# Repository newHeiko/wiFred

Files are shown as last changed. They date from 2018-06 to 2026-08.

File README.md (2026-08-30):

# wiFred
wiThrottle-compatible hardware controller

This repo contains schematics, PCB and documentation for the wiFred, a wiThrottle-compatible WiFi hardware controller developed to unchain the Fremo Fred [1] / Fredi [2] from its loconet cable.

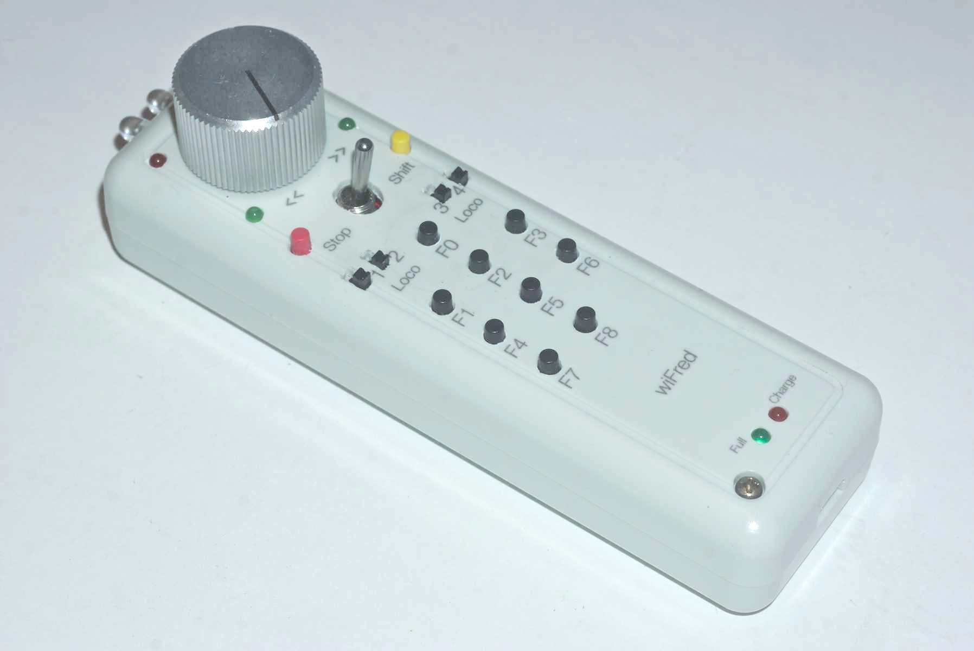
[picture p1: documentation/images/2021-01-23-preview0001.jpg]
wiFred rev0.5


### Branch information
Several versions are contained in different branches:

- master branch: Designed to fit into Strapubox 2090 housing, powered by a lithium battery, hardware: ESP32-S2-WROOM, THT pushbuttons
  - rev0.6 (initial)
  - rev0.62 (switched USB connector to USB-C)
  - rev0.63 (replaced constant current source for flashlight with charge pump, replaced a few out-of-stock parts)
  - rev0.64 (added silk-screen text for LEDs and colored buttons, moved flashlight LEDs further apart, added twist protection for direction switch)
  - Latest Firmware: https://github.com/newHeiko/wiFred/blob/master/software/pre-compiled/2026-08-30-5456979-master.bin
- esp12 branch: Designed to fit into Strapubox 2090 housing, powered by a lithium battery, hardware: AVR ATMega328P plus ESP12F, SMD pushbuttons
  - rev0.4 (no flashlight prototype)
  - rev0.5 (Added flashlight)
  - rev0.51 (Fixed silkscreen on PCB)
  - rev0.52 (Moved LEDs out of the key matrix to get rid of double function key presses)
  - Latest Firmware: https://github.com/newHeiko/wiFred/blob/master/software/pre-compiled/2026-08-30-b6b983a-esp12.bin to go with AVR firmware https://github.com/newHeiko/wiFred/blob/master/software/pre-compiled/2025-03-26-ddf1322-esp12.hex
- esp12-old branch: No longer developed. Mostly the same hardware as esp12 branch before the rev0.52 fix, but with old protocol between AVR and ESP12F and key presses often activating multiple functions. See the documentation at https://newHeiko.github.io/wiFred/documentation/fix05matrix_en.html for fixing the PCB to work with firmware from esp12-branch.
- newAgeEnclosures branch: No longer developed, designed for New Age Enclosures Compact AA housing, powered by 2x AA cells, hardware: AVR ATMega328P plus ESP12F, SMD pushbuttons
- AABatteryPrototype branch: No longer developed, designed for Strapubox 6090 housing, powered by 2x AA cells, hardware: AVR ATMega328P plus ESP12F, SMD pushbuttons, very tight fit requires multiple modifications to Strapubox housing

[1]: <http://fremodcc.sourceforge.net/diy/fred/fred_e.html>
[2]: <http://fremodcc.sourceforge.net/diy/fred2/fredi_d.html>

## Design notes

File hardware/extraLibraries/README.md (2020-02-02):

Extra libraries used in creating the wiFred schematic and PCB:

- my_devices for crystal - included here
- ESP8266.lib for ESP-12F - found at https://github.com/jdunmire/kicad-ESP8266
- NCV8161BSN300T1G.lib for NCV8161 from mouser component download
- MCP73831T-2ACI_OT.lib for MCP73831 from mouser component download

The mouser component download links to http://componentsearchengine.com/ - search either mouser or componentsearchengine.com for the device name and click on the Download ECAD button. You will need the library loader software to convert the .epw file to kicad library files.

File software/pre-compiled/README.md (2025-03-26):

# Pre-compiled firmware updates for wiFred

## wiFred starting from rev0.6 (single controller)

- Use the \*-master.bin files

## wiFred rev 0.5x starting from 0.52 (two controllers)

- Use the \*esp12.bin files for the ESP12 and the \*esp12.hex files for the AVR

## wiFred rev 0.5 or rev0.51 (two controllers)

- Fix the PCB to match 0.52 or higher as following:
  - Remove SMD LED resistors R302, R303 and R304
  - Solder new wired resistors from the R302/R303/R304 pads to the ISP connector pins 1 and 3. See the documentation for pictures and a more detailed description
- Use the same firmwares as for rev0.52 mentioned above

## wiFred up to rev0.4x (two controllers)

- Compile AVR firmware from source from the esp12 branch, undefining WITH_FLASHLIGHT in led.h
- Use the \*esp12.bin files for the ESP12

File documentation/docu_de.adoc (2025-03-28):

= wiFred: WLAN-Drehregler für Modelleisenbahnen mit dem wiThrottle-Protokoll
Heiko Rosemann
0.3, 6-27-2021: v0.6 Beschreibung hinzugefügt - automatisch übersetzt von Axel Thobaben unter Verwendung von Microsoft Edge
:description: Usage documentation, server choices, building instructions, schematics, part lists...
:url-repo: https://github.com/newHeiko/wiFred
:icons: image
:iconsdir: images/icons/
:imagesdir: images/
:lang: de
:toc:

wiFred mit lasergraviertem Gehäuse

[abstract]
== Zusammenfassung

Dieses Dokument beschreibt die Verwendung und Konfiguration des wiFred - eine sehr einfache drahtlose Drehregler für Modelleisenbahnen, um sich mit wiThrottle-Servern wie JMRI zu verbinden. Es enthält auch Schaltpläne und Stücklisten für das Gerät - sowohl für LiPo-Akkuversionen in der aktiven Entwicklung - als auch Programmieranleitungen und Montagetipps sowie eine Übersicht über Optionen für die Serverseite.

Die neueste Version dieses Dokuments finden Sie unter https://newheiko.github.io/wiFred/documentation/docu_de.html, https://github.com/newHeiko/wiFred/raw/master/docu_de.pdf und https://github.com/newHeiko/wiFred/blob/master/docu_de.adoc.

Wenn Sie mehr über die Entwicklungsgeschichte des wiFred erfahren möchten, springen Sie zu <<background>> - ansonsten lesen Sie weiter mit <<throttle>>.

[#throttle]
== Schnellstartanleitung

include::quickBuild_de.adoc[leveloffset=+1,tags=!drilljig]
include::quickBuild_de.adoc[leveloffset=+1,tags=!laser]
include::quickStartup_de.adoc[leveloffset=+1]

== Verwendung

=== Betriebsloks

[#ledTable]
[cols="1,1,1,3"]
.LED-Muster und ihre Bedeutung auf dem wiFred
|===
|Rote LED|Grüne LED (links)|Grüne LED (rechts)|Status

|Langsames Blinken (0.5 Hz)|Aus|Aus|Versuch, eine Verbindung zum WLAN-Netzwerk herzustellen

|Schnelles Blinken (2 Hz)|Aus|Aus|Erfolgreiche WLAN-Verbindung, Versuch, eine Verbindung zum wiThrottle-Server herzustellen und Loks zu erwerben

|Aus|Aus|An|Regelbetrieb, Vorwärtsrichtung

|Aus|An|Aus|Regelbetrieb, Rückwärtsrichtung

|Aus|Blinken|An|Not-Halt, Vorwärtsrichtung. Passiert auch beim Richtungswechsel mit Drehzahlpotentiometer nicht bei Null

|Aus|An|Blinken|Not-Halt, umgekehrte Richtung. Passiert auch beim Richtungswechsel mit Drehzahlpotentiometer nicht bei Null

|Aus|Aus|Blinken|Batterie schwach, Regelbetrieb, Vorwärtsrichtung

|Aus|Blinken|Aus|Batterie schwach, normaler Betrieb, umgekehrte Richtung

|Aus|Blinken|Blinken|Batterie schwach, Not-Halt, Vorwärtsrichtung

|Aus|Blinken|Blinken|Batterie schwach, Not-Halt, umgekehrte Richtung

|Kurze Blitze|Aus|Aus|Handregler im Low-Power-Modus

|Aus|Aus|Aus|Batterie leer oder kein Akku eingelegt

|An|Aus|Aus|Keine Verbindung zum vorhandenen WLAN-Netzwerk. Interne Konfiguration WiFi-Netzwerk erstellt

|Blinken|Blinken|Aus|Beim Start: ESTOP gedrückt, wird nach fünf Sekunden auf die Werkseinstellungen zurückgesetzt. Taste loslassen für normalen Startfootnote:ESP32[Nur verfügbar für Versionen ab 0.6 mit ESP32-S2 MCU]

|Blinken|Aus|Blinken|Beim Start: SHIFT gedrückt, öffnet das interne Konfigurations-WLAN-Netzwerk nach fünf Sekunden. Taste loslassen für normalen Startfootnote:ESP32[]

|Aus|Blinken|Blinken|Beim Start: F0 gedrückt, wenn eine Verbindung mit einem WLAN hergestellt wird. Stellt keine Verbindung zum Server her, sondern aktiviert den Konfigurationsmodus nach fünf Sekunden. Taste loslassen für normalen Startfootnote:ESP32[]

|An|An|An|Konfigurationsmodus aktiviert, während eine Verbindung mit dem vorhandenen WLAN-Netzwerk besteht. Alle Loks Not-Halt, um Ausreißer zu vermeiden. Drücken Sie erneut SHIFT + ESTOP, um den Konfigurationsmodus zu beenden

4+|Um sich von einem Not-Halt zu erholen, drehen Sie das Geschwindigkeitspotentiometer auf Null, um die Verstärkungssteuerung wiederherzustellen.

4+|Siehe auch <<ledTableVoltage>> um die LED-Muster beim Ausschalten aller Loks zu interpretieren.
|===

[#ledTableVoltage]
[cols="1,1,1,3"]
.LED-Muster und wie sie die Batteriespannung beim Ausschalten des wiFred anzeigen
|===
|Rote LED|Grüne LED (links)|Grüne LED (rechts)|Batteriespannung

|Blinken|Aus|Aus|Unter 3,7V

|An|Aus|Aus|Zwischen 3,7V und 3,8V

|An|Blinken|Aus|Zwischen 3,8V und 3,9V

|An|An|Aus|Zwischen 3,9V und 4,0V

|An|An|Blinken|Über 4,0V
|===

[#throttleControls]
.Bedienelemente und Funktionen des wiFred-Handreglers
Handregler

<<throttleControls>> zeigt die Bedienelemente des WLAN-Handreglers. Sie bestehen aus:

- Vier Lokauswahlschalter (Lok 1 links, Lok 4 rechts, Drehzahl potentiometer aktivieren)

- Geschwindigkeitspotentiometer (Gegen den Uhrzeigersinn Endstop: Stop, Endstop im Uhrzeigersinn: Full Speed)

- Richtungsschalter - bewegen Sie sich nach rechts für Vorwärtsbewegung, links für Rückwärtsbewegung

- Schwarze Funktionstasten F0 bis F8

- Gelbe Shift-Taste zum Auslösen von F9-F16 und Einschalten der Taschenlampenfunktion

- Rote Nothalt-Taste

- Zwei grüne Fahrtrichtungsanzeige-LEDs neben dem Drehzahlpotentiometer

- Rote Status-LED neben Drehzahlpotentiometer

- Rote Ladeanzeige-LED am unteren Ende des Geräts - leuchtet während des Ladevorgangs

- Grüne voll aufgeladene Anzeige-LED am unteren Ende des Geräts - leuchtet bei voller Ladung, solange das Ladegerät noch angeschlossen ist

Sobald einer der Lokauswahlschalter in die Position "aktiviert" bewegt wird, wird der Handregler hochgefahren und versucht, eine Verbindung zu einem drahtlosen Netzwerk herzustellen. Wenn alle vier Lokauswahlschalter "deaktiviert" sind, trennt sich die Drehregler nach einer Kulanzzeit von fünf Sekunden vom drahtlosen Netzwerk. Das Gerät wechselt dann in den Energiesparmodus, in dem der Akku länger als ein Jahr hält.

Wenn innerhalb von 60 Sekunden keine Verbindung zu dem im Gerät konfigurierten Netzwerk hergestellt werden kann, erstellt die Drehregler ein eigenes drahtloses Netzwerk namens wiFred-config sowie sechs Hex-Ziffern, die von der MAC-Adresse der wiFred-WLAN-Schnittstelle, z. B. wiFred-config61FB7B, entnommen wurden, um die Konfiguration wie unter <<config>> beschrieben zu aktivieren.

Den vier Lokauswahlschaltern können vier verschiedene Loks zugeordnet werden. Befehle, die vom Geschwindigkeitspotentiometer, dem Richtungsschalter und den Funktionstasten abgeleitet werden, werden (quasi) gleichzeitig an alle ausgewählten Loks übertragen, wobei eine bestimmte Übersetzungstabelle es ermöglicht, dass einige Loks rückwärts fahren, wenn andere vorwärts fahre, und auch Funktionstasten nur auf einige der vier Loks beschränkt - dies wird in <<throttle_LocoConf>> und <<throttle_FunctionConf>> ausführlicher beschrieben.

Durch Drücken der roten Nothalt-Taste sendet der Handregler einen Nothalt-Befehl an alle vier angeschlossenen Loks. Drehen Sie nach einem Not-Halt das Geschwindigkeitspotentiometer auf Null, um die Steuerung der Loks wieder zu aktivieren.

Wenn Sie die rote Not-Aus-Taste drücken, während Sie die Umschalttaste gedrückt halten, wird das Gerät in den Konfigurationsmodus versetzt (und es wird ein Not-Halt für alle angeschlossenen Loks ausgelöst). Weitere Informationen zum Zugriff auf die Konfiguration des Handreglers finden Sie unter <<config>>.

Jede Änderung der Lokauswahlschalter führt dazu, dass der Handregler einen Not-Halt-Befehl an alle angeschlossenen Loks sendet. Dadurch wird sichergestellt, dass jede Lok, die deaktiviert wird, auf dem Layout anhält und verhindert, dass neu ausgewählte Loks plötzlich mit Geschwindigkeit abheben. Gleiches gilt für eine Änderung des Richtungswechsels, um Schnelle Rückwärtsmanöver zu vermeiden. Drehen Sie das Geschwindigkeitspotentiometer auf Null, um die Steuerung der Loks wieder zu aktivieren.

Wenn der Akku schwach ist, wird das Gerät vor dem Laden der Batterien nicht wieder aktiviert, aber wenn es schon aktiv ist, läuft es etwa eine Stunde weiter. Wenn der Akku leer ist, wird er getrennt und in den Energiesparmodus versetzt. Die erwartete Laufzeit beträgt etwa 20 Stunden Vollzeitbetrieb, mehr, wenn die Drehregler in den Energiesparmodus versetzt wird, wenn die Loks nicht laufen.

Während der Inbetriebnahme und des Betriebs zeigen die LEDs die in <<ledTable>> beschriebenen Muster an. Nach dem Ausschalten des wiFred zeigen die LEDs für einige Sekunden die aktuelle Batteriespannung an, wie in <<ledTableVoltage>> beschrieben.

=== Aufladen des wiFred

Der wiFred kann über den Micro-USB- oder USB-C-Anschluss am unteren Ende des Gerätes aufgeladen werden. Der maximale Ladestrom beträgt ca. 400 mA und das Gerät kommuniziert nicht mit dem USB-Host, so dass technisch gesehen keine Garantie dafür besteht, dass das Aufladen über ein USB-Kabel funktioniert, aber die meisten Ladegeräte, Computeranschlüsse oder Powerbanks überprüfen den Strom vor dem Einschalten nicht.

Solange der Akku geladen wird, leuchtet die rote Ladeanzeige-LED. Wenn der Akku vollständig geladen ist, leuchtet die grüne Anzeige-LED, solange das Ladegerät noch angeschlossen ist. Die erwartete Ladezeit beträgt etwa fünf bis sechs Stunden für eine vollständige Ladung.

Auch während des Ladevorgangs kann das Gerät noch betrieben werden (besonders hilfreich bei einer Powerbank), aber da der Betriebsstrom aus dem Akku kommt, wird der Akku nie vollständig geladen.

Wenn beide Ladezustands-LEDs aufleuchten, wenn ein Ladekabel angeschlossen wird, ist wahrscheinlich die interne Verbindung zum Akku fehlerhaft.

[#config]
== Konfigurieren des wiFred

Bevor Sie das Gerät verwenden können, muss es konfiguriert werden. Zumindest muss die wiFred-Hauptkonfigurationsseite <<#throttleConfMainPage>> einmal abgeschickt werden, um im nichtflüchtigen Speicher gespeichert zu werden. Wenn beim Start keine gültige Konfiguration erkannt wird, startet das Gerät mit einer Standardkonfiguration ohne aktivierte Loks und ohne WLAN-Einstellungen, sodass es keine Verbindung zu einem WLAN-Netzwerk herstellen kann.

IMPORTANT: Nach Eingabe jeglicher Art von Text (Namen, Zahlen...) in Textfelder muss der entsprechende "Speichern"-Button gedrückt werden, um die Änderungen an den wiFred zu übermitteln.

=== Wechseln in den Konfigurationsmodus

NOTE:  Der wiFred sollte zur Konfiguration in den Konfigurationsmodus versetzt werden. Wenn die IP-Adresse oder der Hostname des wiFred bekannt ist, ist auch ein Zugriff auf die Konfigurationsseiten möglich, indem man zu einem beliebigen Zeitpunkt (während der wiFred mit dem WLAN verbunden ist) mit einem Webbrowser darauf zugreift. Dies ist größtenteils ungetestet und kann zu zwischenzeitlich inkonsistenter Konfiguration führen. Mindestens die Deaktivierung und anschließende Re-Aktivierung der Lok mit dem Schiebeschalter dürfte immer nötig sein, um Konfigurationsänderungen zu übernehmen.

Es gibt vier Möglichkeiten, in den Konfigurationsmodus zu wechseln:

. Schalten Sie die Drehregler ein / wählen Sie eine Lok, wenn das konfigurierte WLAN-Netzwerk nicht in Reichweite ist (oder wenn keine gültige Konfiguration vorhanden ist - der erste Start einer neuen Drehregler fällt in diese Kategorie)

. Schalten Sie die Drehregler ein / wählen Sie eine Lok aus, während Sie fünf Sekunden lang die SHIFT-Taste gedrückt haltenfootnote:ESP32[]

. Drücken Sie die SHIFT-Taste und ESTOP zusammen, wenn die Drehregler angeschlossen ist

. Drücken Sie F0 für fünf Sekunden, während / nachdem das Gerät mit einem WLAN-Netzwerk verbunden istfootnote:ESP32[]

In den ersten beiden Fällen erstellt der Handregler ein drahtloses Netzwerk mit dem Namen wiFred-config plus sechs Hex-Ziffern, die von der MAC-Adresse der wiFred-WLAN-Schnittstelle stammen, z. B. wiFred-config61FB7B, und kündigt seine Anwesenheit unter dem Namen config.local an sowie die Erstellung eines Captive-Portals an. Jedes WIFi-Gerät mit einem Webbrowser kann eine Verbindung zu diesem Netzwerk herstellen und einen Webbrowser öffnen und http://192.168.4.1 oder http://config.local zu öffnen.

NOTE: Dies wurde mit Mozilla Firefox und Opera unter Linux mit Avahi (einer Zeroconf-Implementierung), FOSS Browser auf Android 9/10 und Safari auf iOS 13/14 getestet.

Im dritten und vierten Fall kündigt der Handregler seine Anwesenheit nur unter dem Namen config.local unter Verwendung des Bonjour/Zeroconf-Protokolls. Jedes Gerät im selben WLAN-Netzwerk mit Bonjour/Zeroconf kann über einen Webbrowser auf die Konfiguration unter http://config.local zugreifen. Unter <<configurationComputer>> finden Sie eine Erläuterung, was erforderlich ist, damit Ihr Gerät Bonjour/Zeroconf-Ankündigungen liest.

NOTE:  Dies wurde mit Mozilla Firefox und Opera unter Linux mit Avahi (einer Zeroconf-Implementierung) und BonjourBrowser auf Android 10 getestet.

<<throttleConfMainPage>> zeigt die erste Seite, die Sie sehen, wenn Sie einen Webbrowser auf Ihren wiFred-Drehregler richten. Es ist in mehrere Abschnitte unterteilt, die in den folgenden Kapiteln erläutert werden.

[#throttleConfMainPage]
.Screenshot der wiFred-Hauptkonfigurationsseite
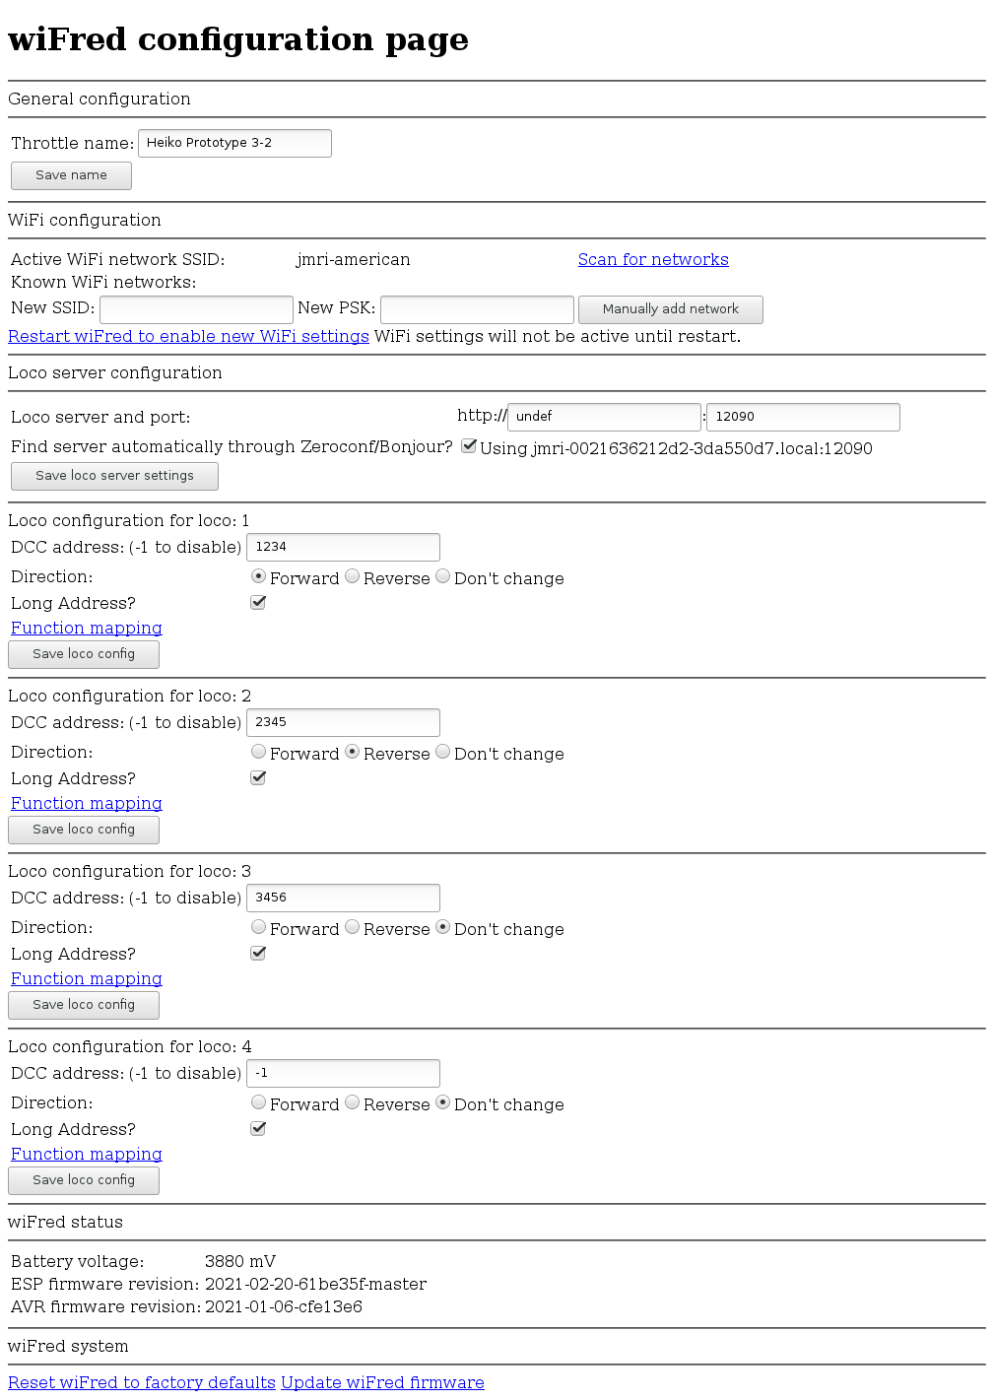
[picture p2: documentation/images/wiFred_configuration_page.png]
wiFred main configuration page


=== Allgemeine Konfiguration

Im Abschnitt "General Configuration" gibt es nur eine Konfigurationsoption: Den Handregler-Namen. Dies ist eine Freiform-Identifikationszeichenfolge des Handreglers. Es wird im wiThrottle-Fenster von JMRI angezeigt, wie in  <<withrottleScreenshot>> gezeigt, der eine angeschlossene Drehregler zeigt, und kann verwendet werden, um die Drehregler während der Konfiguration zu identifizieren.

NOTE: Der wiFred kündigt seine Präsenz im WiFi-Netzwerk auch über Bonjour / Zeroconf mit einer bereinigten Version des Namens an, d.h. ein Handregler namens "Heiko Prototype 2-2" wird seine Anwesenheit als heikoprototype22.local ankündigen, wenn er sich nicht im Konfigurationsmodus befindet.

=== WLAN-Konfiguration

Der Abschnitt "WiFi configuration" zeigt eine Liste der konfigurierten WLAN-Netzwerke. Der wiFred stellt eine Verbindung zu einem Netzwerk in dieser Liste her. Wenn mehrere konfigurierte Netzwerke in Reichweite sind, wählt er das stärkste aus.

Vorhandene Einträge können durch Klicken auf die Schaltfläche "Remove SSID" in der Zeile des Netzwerks, das entfernt werden soll, entfernt werden.

Neue Einträge können entweder durch manuelle Eingabe der SSID und PSKfootnote:PSK[Pre-Shared Key, oft nur Passwort genannt] bei Bedarf und Klick auf die Schaltfläche "Manually add network" oder durch Klicken auf den Link "Scan for networks" hinzugefügt werden, der den Benutzer auf die in <<throttleConfWiFiPage>> gezeigte Seite führt.

[#throttleConfWiFiPage]
.Screenshot der wiFred "Scan for networks"-Seite
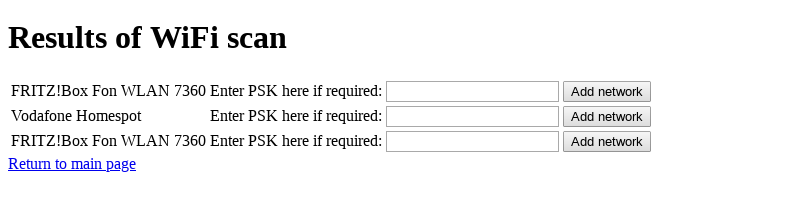
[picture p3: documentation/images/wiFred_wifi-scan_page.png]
Scan for networks Seite


Das Laden dieser Seite dauert einige Sekunden, da der Scan nach Netzwerken zuerst abgeschlossen werden muss. Es zeigt alle Netzwerke an, die während des Scans gefunden wurden. Netzwerke können der Liste hinzugefügt werden, indem Sie auf die Schaltfläche "Add network" klicken, nachdem Sie das PSKfootnote:PSK[] in das Feld daneben eingegeben haben.

NOTE: Der wiFred unterstützt WPS nicht und akzeptiert nicht mehrere Netzwerke mit derselben SSID, aber unterschiedlichen PSKs. Weitere Details zu den Netzwerkanforderungen finden Sie unter <<serverSetup>>.

Die neue WLAN-Konfiguration wird erst aktiviert, wenn der wiFred neu gestartet wird, entweder durch einen Aus- und Einschaltvorgang oder durch Klicken auf den Link "Restart wiFred to enable new WiFi-settings" auf der Konfigurationsseite.

=== Lok-Server-Konfiguration

Im Anschluss an die WLAN-Konfiguration ermöglicht der Abschnitt "Loco server configuration" die Konfiguration des wiThrottle-Servers, mit dem sich der wiFred verbinden soll. Die Standardeinstellung - Server automatisch erkennen - funktioniert gut, wenn nur ein wiThrottle-Server im Netzwerk vorhanden ist. Es verbindet sich mit jedem Server, der seine Anwesenheit auf Port 12090 über Zeroconf / Bonjour ankündigt. Das Ergebnis der Zeroconf / Bonjour-Suche wird hier angezeigt, wenn der wiFred automatisch einen Server entdeckt hat.

[#throttle_LocoConf]
=== Loco configuration

Nach der "Lokserverkonfiguration" sind den vier verschiedenen Lokomotiven vier identische Abschnitte zugeordnet, die mit diesem Handregler gesteuert werden können. Jeder Abschnitt besteht aus den folgenden Einstellungen:

DCC address:: Kann eine kurze Adresse zwischen 1 und 127 (auch für Mehrfachtraktionen verwendet) oder eine lange Adresse zwischen 0 und 10239 sein.

NOTE: Kurze Adressen zwischen 1 und 127 sind nicht dasselbe wie lange Adressen zwischen 1 und 127, und viele DCC-Systeme unterstützen nicht alle diese Adressen.footnote:[Insbesondere die langen Adressen 0-127 werden häufig nicht unterstützt, z.B. auf Loconet-Systemen.] Nicht unterstützte Adressen werden stillschweigend ignoriert.

Ist diese auf -1 gesetzt, ist die entsprechende Lok deaktiviert.

Long address?:: Kontrollkästchen, um das Verhalten des oben beschriebenen DCC-Adresseingabefeldes zu ändern.

Direction:: Dies hat drei Möglichkeiten:

* Forward: Lok fährt vorwärts, wenn wiFred auf vorwärts eingestellt ist und umgekehrt

* Reverse: Lok fährt rückwärts, wenn wiFred auf vorwärts eingestellt ist und umgekehrt

* Don't change: Die Lok fährt weiterhin in die gleiche Richtung, in die sie bei der Aktivierung eingestellt wurde, und wechselt die Richtung, wenn die wiFred die Richtung wechselt

Function mapping:: Link zur Funktionsmapping-Unterseite für die entsprechende Lok, wie unter <<throttle_FunctionConf>> beschrieben. Wenn Sie auf diesen Link klicken, gehen alle auf der aktuellen Seite eingegebenen Informationen verloren und der Webbrowser gelangt auf eine andere Unterseite.

IMPORTANT: Erinnerung: Änderungen werden über die Schaltfläche "Save loco config" gespeichert, die in verschiedenen Webbrowsern unterschiedlich aussehen kann (Firefox gezeigt).

[#throttle_FunctionConf]
=== Konfiguration der DCC-Funktion

Wenn eine Funktionstaste gedrückt wird, sendet die Drehregler standardmäßig die entsprechenden Befehle an jede unter Kontrolle befindliche Lok. Unter Umständen ist dies nicht erwünscht - das naheliegende Beispiel ist eine Lok in der Mitte einer Mehrfachtraktion, die kein Spitzenlicht haben sollte. So bietet diese Seite - gezeigt in <<throttleConfigFunctionPage>> - die Möglichkeit, zwischen verschiedenen Einstellungen für jede Funktion an jeder der vier Lokomotiven (eine Seite pro Lokomotive) zu wählen:

[#throttleConfigFunctionPage]
.Screenshot der Konfigurationsseite für die WiFred-Funktionszuordnung
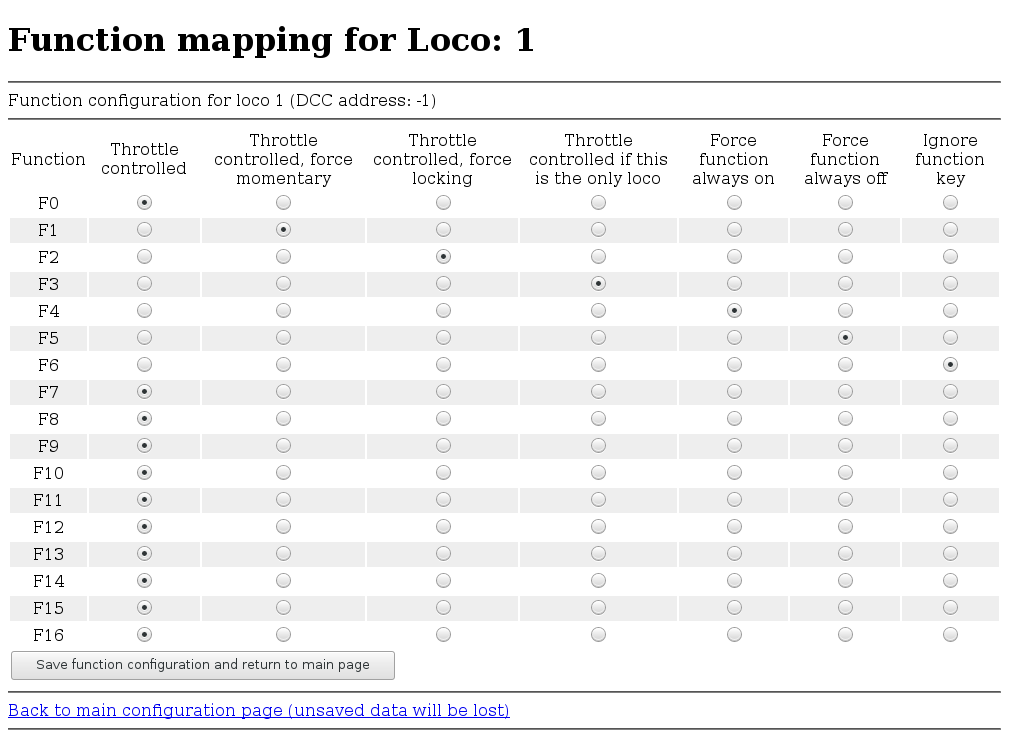
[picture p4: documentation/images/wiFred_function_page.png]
wiFred function page


Throttle controlled:: Wenn die erste Lok durch Bewegen des Auswahlschalters an die "ausgewählte" Position aktiviert wird, wird der aktuelle Status der Funktion abgefragt und gespeichert. Bei der Auswahl der nächsten Lok wird der Funktionsstatus auf den gleichen stellen. Anschließend werden Tastendrücke an die Lok durchgereicht. Ob die Funktion tastendfootnote:MOM[Tastende Funktionen werden nur aktiviert, solange die Funktionstaste gedrückt wird - wie eine Pfeife oder eine Hupe, die genauso lange ertönt, wie die Taste gedrückt wird.] oder rastendfootnote:[Rastende Funktionen werden mit jedem Druck auf die Funktionstaste umgeschaltet - wie das erste Drücken von F0 normalerweise das Spitzenlicht einschaltet, das nächste Drücken von F0 schaltet es wieder aus.] sein wird, wird vom Server bestimmt, im Falle von JMRI durch den Roster-Eintrag.

Throttle controlled, force momentary:: Die Funktionstaste wird als tastende Funktionfootnote:MOM[] an die Lok durchgereicht.

Throttle controlled, force locking:: Wie für *Throttle controlled* beschrieben, wird die Funktion jedoch unabhängig von den Servereinstellungen als rastend festgelegtfootnote:[Die JMRI-Einstellung "F2 always momentary" überschreibt dies.]

Throttle controlled if this is the only loco:: Wie für *Throttle controlled, force locking* beschrieben, aber die Funktionstaste wird die Funktion nur umschalten, wenn keine andere Lok aktiviert ist. Dies ermöglicht z.B. das Ein- und Ausschalten von Spitzenlicht und Rücklicht an einzelnen Loks vor dem Zusammenkoppeln einer Mehrfachtraktion.

Force function always on:: Die Funktion wird bei Aktivierung der Lok eingeschaltet und bleibt unabhängig von Tastendrücken eingeschaltetfootnote:[Dadurch werden auch momentane Funktionen dauerhaft eingeschaltet.].

Force function always off:: Die Funktion wird bei Aktivierung der Lok abgeschaltet und bleibt unabhängig von Tastendrücken ausgeschaltet.

Ignore function key:: Es werden keine Funktionsbefehle an diese Lok gesendet.

IMPORTANT: Erinnerung: Änderungen werden über die Schaltfläche "Save function configuration" gespeichert, die in verschiedenen Webbrowsern unterschiedlich aussehen kann (Firefox gezeigt).

=== wiFred-Status

Der Abschnitt "wiFred status" zeigt die aktuelle Batteriespannung, gemessen am wiFred. Dies wird beim erneuten Laden der Seite aktualisiert, nicht kontinuierlich.

Es zeigt auch die aktuelle Firmware-Version(en).

=== wiFred-System

Im Abschnitt wiFred system können diverse Einstellungen zur Hardware des wiFred angepasst werden.

Die erste Einstellung betrifft wiFreds, die einen Fahrtrichtungsumschalter mit Mittelstellung haben, und bestimmt, welche Befehle der wiFred bei Mittelstellung sendet. Die Optionen sind:

Ignore:: Behält die Fahrtrichtung bei, die der wiFred vor dem Umschalten in Mittelstellung hatte. Die Geschwindigkeit wird weiterhin durch das Potentiometer bestimmt. Eine vollständige Fahrtrichtungsumkehr löst einen Not-Halt aus.

Zero Speed:: Behält die Fahrtrichtung bei, sendet aber Fahrstufe Null an alle Loks. Diese Einstellung ist für Loks gedacht, die auf hohe Anfahr- und Bremsverzögerung eingestellt sind. Wenn die Fahrtrichtung in weniger als einer halben Sekunde vollständig umgeschaltet wird, löst der wiFred einen Not-Halt aus, sonst beschleunigen die Loks in der neuen Fahrtrichtung wieder auf die eingestellte Geschwindigkeit.footnote:[Diese Einstellung ist kompatibel mit der "Segeln"-Funktion des Fredi]

Set F<n>:: Simuliert die Betätigung der eingestellten Funktionstaste beim Umschalten von Vorwärts auf Mittelstellung und das Loslassen beim Umschalten von Mittelstellung auf Rückwärts (und umgekehrt).footnote:[Die entsprechende Funktion sollte, wie in <<throttle_FunctionConf>> beschrieben, als tastend festgelegt sein damit dies wie gedacht funktioniert] Diese Einstellung ist für Loks gedacht, die auf einer Funktionstaste eine Bremsfunktion oder ESUs Drive Hold haben. Die an die Loks gesendete Geschwindigkeit wird weiterhin durch das Potentiometer bestimmt, solange der Fahrtrichtungsumschalter in Mittelstellung liegt. Wenn die Fahrtrichtung in weniger als einer halben Sekunde vollständig umgeschaltet wird, löst der wiFred einen Not-Halt aus, sonst sendet der wiFred weiterhin die am Potentiometer eingestellte Geschwindigkeit an die Loks.

Der Abschnitt schließt mit zwei Links:

- Reset wiFred to factory defaults - der zu einer Bestätigungsseite führt, die in <<throttleConfResetPage>> angezeigt wird, um alle Konfigurationsdaten auf die Werkseinstellungen wie bei einem neuen wiFred zurückzusetzen.

- Update wiFred firmware - der zu einer Firmware-Update-Seite führt, die in <<throttleConfUpdatePage>>  angezeigt wird, um die wiFred-Firmware des ESP8266 / ESP32-S2 zu aktualisieren. Suchen Sie die .bin-Datei aus dem arduino-Build-Ordner oder aus dem [Github-Repository für wiFred], klicken Sie auf "Durchsuchen", navigieren Sie zur .bin-Datei und starten Sie schließlich das Update mit einem Klick auf "Update Firmware" - was eine Weile dauern wird.

NOTE: Es kann erforderlich sein, den wiFred vollständig auszuschalten, damit er nach einem Firmware-Update ordnungsgemäß neu gestartet werden kann.

NOTE: Bei einer wiFred-Version ab 0.6 mit ESP32-S2 MCU kann das Zurücksetzen auf die Werkseinstellungen auch durch Fünf-Sekunden-Halten der ESTOP-Taste beim Start erfolgen.

[#throttleConfResetPage]
.Screenshot der wiFred-Konfigurationsrücksetzungsseite
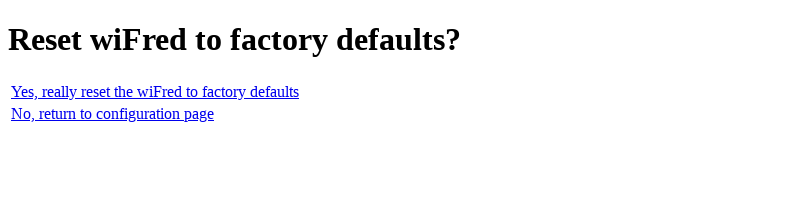
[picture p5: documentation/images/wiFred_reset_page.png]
wiFred-Konfigurationsrücksetzungsseite


[#throttleConfUpdatePage]
.Screenshot der wiFred-Firmware-Update-Seite
wiFred-Firmware-Update-Seite

[#serverSetup]
== Optionen für die Servereinrichtung

=== Komponenten, die zum Betrieb des wiFred erforderlich sind

[#withrottleScreenshot]
.Screenshot des wiThrottle-Bildschirms mit einem angeschlossenen Handregler
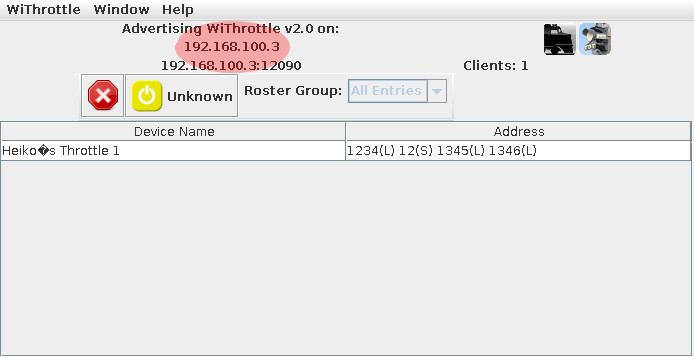
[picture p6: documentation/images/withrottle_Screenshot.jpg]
wiThrottle Bildschirm


<<runningTrains>> zeigt die Verbindungen zwischen den Geräten, die für den Betrieb von Zügen mit dem wiFred erforderlich sind.

[#runningTrains]
.Infrastruktur zum Betrieb von Loks mit dem wiFred
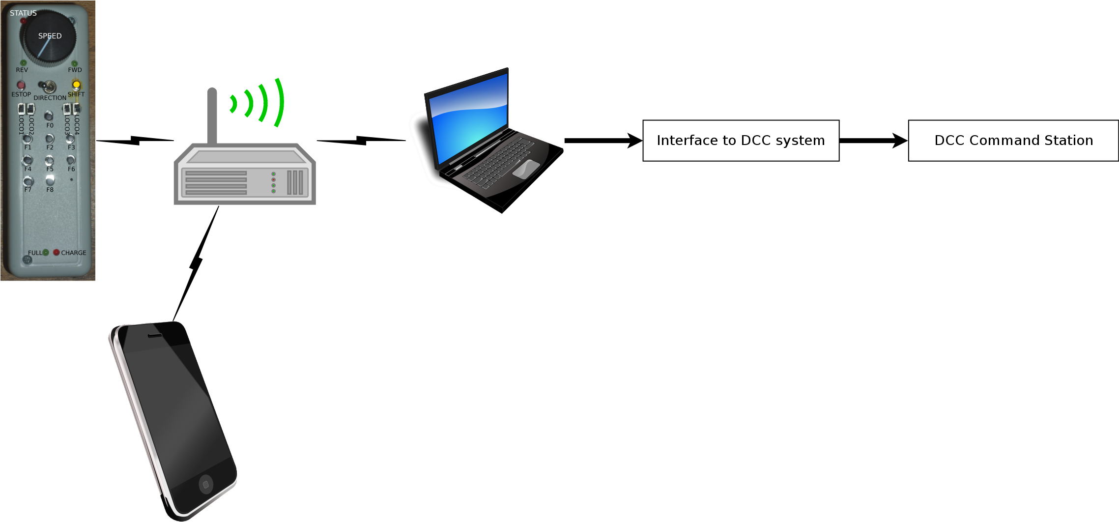
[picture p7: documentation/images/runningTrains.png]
Infrastruktur zum Betrieb von Loks mit dem wiFred


Die Symbole in <<runningTrains>> symbolisieren die folgenden Teile:

. Ein IEEE 802.11b/g/n 2,4 GHz WiFi Access Point, der ausführlich unter <<serverWiFi>>  beschrieben wird

. Ein PC oder Laptop mit Windows, Linux oder MacOS zum Ausführen des JMRI-Servers, der in den <<serverJMRI>> ausführlich beschrieben ist

. Eine Möglichkeit, den JMRI-Server mit dem Modelleisenbahnlayout zu verbinden, das unter <<serverLayoutConn>> ausführlich beschrieben wird

. Ein Gerät mit einem Webbrowser, das mit demselben Netzwerk wie der wiFred verbunden ist, um den wiFred zu konfigurieren - kann das gleiche physische Gerät wie dasjenige sein, auf dem der Server ausgeführt wird, wenn es die Anforderungen in <<configurationComputer>> erfüllt

In den folgenden Abschnitten werden mehrere Optionen für jeden Schritt oder die Kombination dieser Schritte beschrieben.

NOTE: Grundsätzlich gilt: Wenn ein Layout so eingerichtet ist, dass Züge mit einem Smartphone mit wiThrottle oder EngineDriver gesteuert werden können, sollte ein wiFred ohne Änderungen an der Layoutkonfiguration funktionieren. Wenn ein Layout so eingerichtet ist, dass Züge von einem JMRI-Fahrregler auf einem Computer gesteuert werden können, muss nur eine WLAN-Verbindung zum JMRI-Computer hinzugefügt werden.

=== Sofort einsatzbereite serverseitige Optionen

Eine ziemlich out-of-the-box-Lösung für einen Raspberry Pi wird von <<rpiImage>> bereitgestellt, der sein eigenes WiFi-Netzwerk erstellt, automatisch mehrere Optionen für die Schnittstelle zu einem DCC-Layout erkennt und einen wiThrottle-Server startet. Es wurde in den Versionen JMRI 4.16 und JMRI 4.20 getestet, um mit dem wiFred zu arbeiten und sowohl über einen RRCircuits LocoBuffer USB als auch über einen Digitrax PR3 über Loconet mit einem Z21 black verbunden zu werden.

Obwohl bisher ungetestet, sollte das Hinzufügen eines <<Digitrax>> zu einem Digitrax-System oder eines <<MRC>> zu einem MRC-System es dem wiFred ermöglichen, auch Loks out-of-the-box zu steuern.

[#windowsWiFi]
=== Schritt-für-Schritt-Anleitung für einen Windows-Computer-Hotspot

Dies wurde auf einem Windows 7 64Bit Laptop-Computer mit einer 2,4 GHz WiFi-Karte im PC getestet.

==== Installation

. Installieren Sie https://www.nirsoft.net/utils/wifi_hotspot_starter.html[HostedNetworkStarter]

. Installieren Sie https://www.dhcpserver.de/cms/download/[DHCP server] - laden Sie alle Dateien aus der ZIP-Datei herunter und extrahieren Sie sie an einen Ort auf Ihrer Festplatte, z. B. C:\DHCPServer

. Installieren Sie ein JDK, Version 8 und 11 wurden getestet. Beispiel: https://adoptopenjdk.net/releases.html[Version OpenJDK 11 (LTS), JVM HotSpot]  Wählen Sie die 64-Bit-Version für die meisten modernen Hardware, 32-Bit nur, wenn Sie ein 32-Bit-Betriebssystem verwenden. Einfachste Option: MSI-Datei, Download und Installation.

. Installieren Sie https://www.jmri.org[JMRI] - Versionen, die für die Ausführung mit dem wiFred getestet wurden, umfassen 4.14, 4.16, 4.18 und 4.20. Neueste Produktionsversion empfohlen.

NOTE: Windows 10 bietet eine Hotspot-Funktion, die anstelle von HostedNetworkStarter und DHCP-Server funktioniert, sodass Sie direkt in die Installation von JDK und JMRI einsteigen können.

==== Konfiguration

. Starten Sie HostedNetworkStarter über das Startmenü, geben Sie einen Netzwerknamen und einen Netzwerkschlüssel ein und klicken Sie dann auf die Schaltfläche Start. Notieren Sie sich den "Namen der gehosteten Netzwerkverbindung" für den nächsten Schritt

. Starten Sie den DHCP-Server-Assistenten von C:\DHCPServer\dhcpwiz.exe, wählen Sie das Netzwerk mit dem Namen aus, der mit dem "Host Network Connection Name" aus dem Schritt zuvor identisch ist, klicken Sie einige Male auf "Next" (Deaktivieren Sie die Auswahl aller zusätzlichen unterstützten Protokolle), Schreiben Sie in die INI-Datei, starten Sie den Dienst und konfigurieren Sie Firewall-Ausnahmen

. Starten Sie JMRI mit dem DecoderPro-Symbol auf dem Desktop, richten Sie Ihre Layoutverbindung ein, testen Sie, ob Sie eine Lok mit einer JMRI-Drehregler ausführen können

. Starten Sie in JMRI den WiThrottle Server über das Menü Aktionen. Wenn ein Firewall-Popup angezeigt wird, lassen Sie alle zu.

. Bearbeiten Sie in JMRI die Einstellungen aus dem Menü Bearbeiten, wählen Sie WiThrottle im linken Bereich und klicken Sie auf das Kontrollkästchen "Automatisch mit Anwendung starten". Alle zulässigen Steuerelemente können deaktiviert werden.

==== Betrieb

. Starten Sie HostedNetworkStarter über das Startmenü, geben Sie einen Netzwerknamen und einen Netzwerkschlüssel ein und klicken Sie dann auf die Schaltfläche Start.

. Starten Sie JMRI mit dem DecoderPro-Symbol auf dem Desktop

[#serverWiFi]
=== Anforderungen an WLAN Access Points

Der wiFred funktioniert im Grunde auf jedem 2,4 GHz IEEE802.11b oder -g WiFi-Netzwerk, das neue Geräte akzeptiert und ihnen eine IPv4-Adresse über einen DHCP-Server zur Verfügung stellt. Es unterstützt offene Netzwerke oder WPA2-Verschlüsselung, jedoch nicht WPS.

Es wurde erfolgreich getestet mit einer FRITZ!Box, einem unbekannten Kabelrouter, mehreren öffentlichen WLAN-Netzwerken und mehreren Software-Hotspots einschließlich Linux hostapd sowohl auf einem Intel Atom Netbook der ersten Generation als auch auf einem Raspberry Pi, dem Windows 10 Hotspot und einer Windows 7 Software, wie in #serverWiFi beschrieben.

NOTE: Einige WLAN-Zugangspunkte und Router bieten eine Funktion namens "Wireless Isolation" oder ähnliches, die es verbundenen Geräten verbietet, sich miteinander zu verbinden. Diese Funktion sollte deaktiviert werden, damit wiFreds ihren Server finden und konfiguriert werden können.

[#serverJMRI]
=== JMRI-Serveranforderungen

Jeder PC, auf dem mindestens Java 8 ausgeführt werden kann, kann den JMRI-Server ausführen. Selbst alte 32Bit Netbook-Computer der ersten Generation wie der 2008 Eee-PC haben mehr als genug Rechenleistung für diese Aufgabe. Es gibt JMRI-Versionen für Windows, Linux oder MacOS, daher sollte jedes dieser Betriebssysteme in Ordnung sein.

[#serverLayoutConn]
=== Layout-Verbindungsoptionen

<<JMRI>> unterstützt eine Vielzahl unterschiedlicher Verbindungen zum Layout, wie unter <<jmrihardwaresupport>> beschrieben. Im Allgemeinen, wenn eine JMRI-Installation eine Lok auf dem Layout ausführen kann, ist es eine einfache Angelegenheit, den JMRI-Computer mit einem WLAN-Zugangspunkt zu verbinden (falls nicht bereits verbunden) und den wiThrottle-Server über das Aktionsmenü in DecoderPro zu starten.

Der wiFred wurde getestet mit einem LocoBufferUSB oder einem Digitrax PR3, die jeweils über Loconet mit einer Intellibox, einer Z21 black, einer DCS 51 Zephyr xtra oder einer Minibox 2 DIY DCC Zentrale verbunden ist. Es wurde auch verwendet, um eine Lok auf einem SPROG-Programmierer zu betreiben.

[#configurationComputer]
=== Computer oder Smartphone zur Konfiguration von wiFred

Webbrowser, Zeroconf. Avahi. Bonjour (iTunes?). MacOS out of the box?
iOS? Android?

Für die Erstkonfiguration des wiFred können die meisten der oben genannten Geräte entfallen. Wie in <<confWifred>> gezeigt wird nur ein WLAN-fähiges Gerät mit einem Webbrowser benötigt.

[#confWifred]
.Für die Erstkonfiguration sind die Anforderungen sehr gering
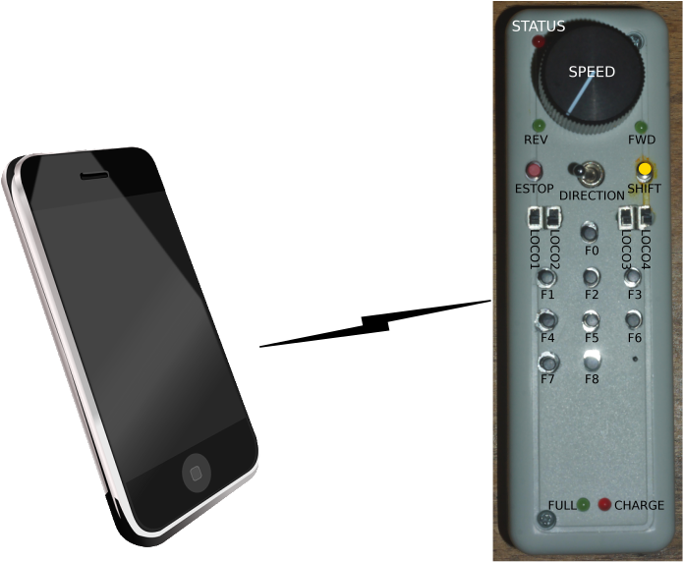
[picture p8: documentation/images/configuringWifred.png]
wiFred-Erstkonfiguration


Getestet mit iOS 13 und iOS 14, Android 9 und 10 sowie Firefox unter Linux wird die Erstkonfigurationsseite automatisch geladen, wenn das Gerät mit dem wiFred-configXXXX-Netzwerk verbunden ist.

Für die reguläre Konfiguration ist Bonjour/Zeroconf/mDNS-Unterstützung erforderlich, sobald der wiFred erfolgreich eine Verbindung zu einem WLAN-Netzwerk hergestellt und in den Konfigurationsmodus versetzt wurde, um das Gerät zu finden, das sich selbst als http://config.local ankündigt. Dieser Dienst wird unter Linux von einem Softwarepaket namens avahi bereitgestellt, sollte auf iOS und MacOS sofort funktionieren und kann unter Windows mit iTunes installiert werden. Für mobile Betriebssysteme gibt es Apps namens Discovery für iOS und BonjourBrowser für Android, die nicht nur http://config.local übersetzen, um auf die Konfigurationswebsite des im Netzwerk zu verweisen, der sich im Konfigurationsmodus befindet, sondern auch alle wiFreds durchsuchen, die derzeit ihre Anwesenheit ankündigen. <<bonjourBrowser>> zeigt einen Screenshot der Android-Version. Wenn Sie auf ein Gerät klicken, wird ein Browser zu seiner Konfigurationswebsite geöffnet.

NOTE:  Der wiFred sollte zur Konfiguration in den Konfigurationsmodus versetzt werden. Wenn die IP-Adresse oder der Hostname des wiFred bekannt ist, ist auch ein Zugriff auf die Konfigurationsseiten möglich, indem man zu einem beliebigen Zeitpunkt (während der wiFred mit dem WLAN verbunden ist) mit einem Webbrowser darauf zugreift. Dies ist größtenteils ungetestet und kann zu zwischenzeitlich inkonsistenter Konfiguration führen. Mindestens die Deaktivierung und anschließende Re-Aktivierung der Lok mit dem Schiebeschalter dürfte immer nötig sein, um Konfigurationsänderungen zu übernehmen.

[#bonjourBrowser]
.Benutzeroberfläche von BonjourBrowser, die zwei im Netzwerk aktive wiFreds anzeigt.
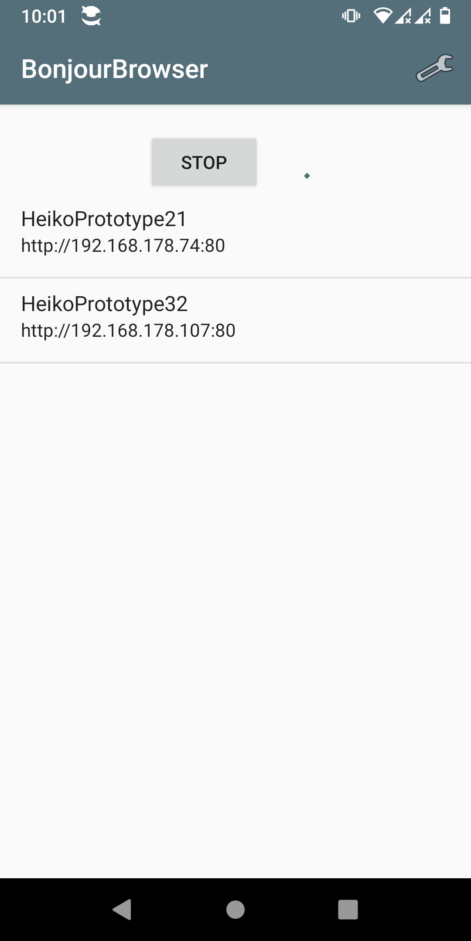
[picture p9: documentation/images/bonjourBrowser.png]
BonjourBrowser mit zwei wiFreds


=== Schnittstelle zu Konfigurationssoftware

Zur Verwendung mit einer Konfigurationssoftware sendet der wiFred unmittelbar nach der Verbindung ins WLAN einen UDP-Broadcast und stellt unter /api/getConfigXML die Konfiguration zur Verfügung.

Mehr Information dazu bei mailto:wiFred@bornwnd.de[Detlef Born].

== Hardware-Beschreibung

=== Ab Revision 0.6

Die wiFred-Hardware ist um ein ESP32-S2-WROOM-Modul zentriert, das die LEDs steuert und die Schalter, Drucktasten und Das Geschwindigkeitspotentiometer ausliest. Es erhält seine Energie von einer Einzelzellen-LiPo-Batterie über einen linearen 3,3-V-Spannungsregler, der direkt von den Lokwahlschaltern aktiviert wird, die durch einen Satz von Dioden logisch verbunden werden. Ein RC-Tiefpass verzögert das Ausschalten des wiFred um ein paar Sekunden.

Optional können zwei weiße 5 mm-LEDs, die aus der Oberseite der Leiterplatte herausragen, als Taschenlampe installiert werden. Sie werden von einer Konstantstromquelle direkt aus dem Akku angetrieben und beim Drücken der gelben SHIFT-Taste aktiviert.

Der ESP32-S2 überwacht auch die Batteriespannung und wechselt in den Ruhezustand, wenn die Batteriespannung zu niedrig abfällt. Dies sollte den Stromverbrauch auf einen einigermaßen sicheren Wert senken, auch wenn er nicht so niedrig ist, wie er sein kann, wenn alle Lokauswahlschalter ausgeschaltet sind. Das Aufladen des Akkus kann über den integrierten USB-Anschluss erfolgen, wobei zwei LEDs den Ladestatus anzeigen.

Der Schaltplan ist in mehrere Seiten aufgeteilt und wird in <<schematic06page1>> bis <<schematic06page3>> gezeigt. Er wurde mit kicad erstellt und ist zusammen mit dem PCB-Design im <<github>> verfügbar.

[#schematic06page1]
.Schaltplanseite mit Batterieanschluss, Ladeschaltung und Netzteil
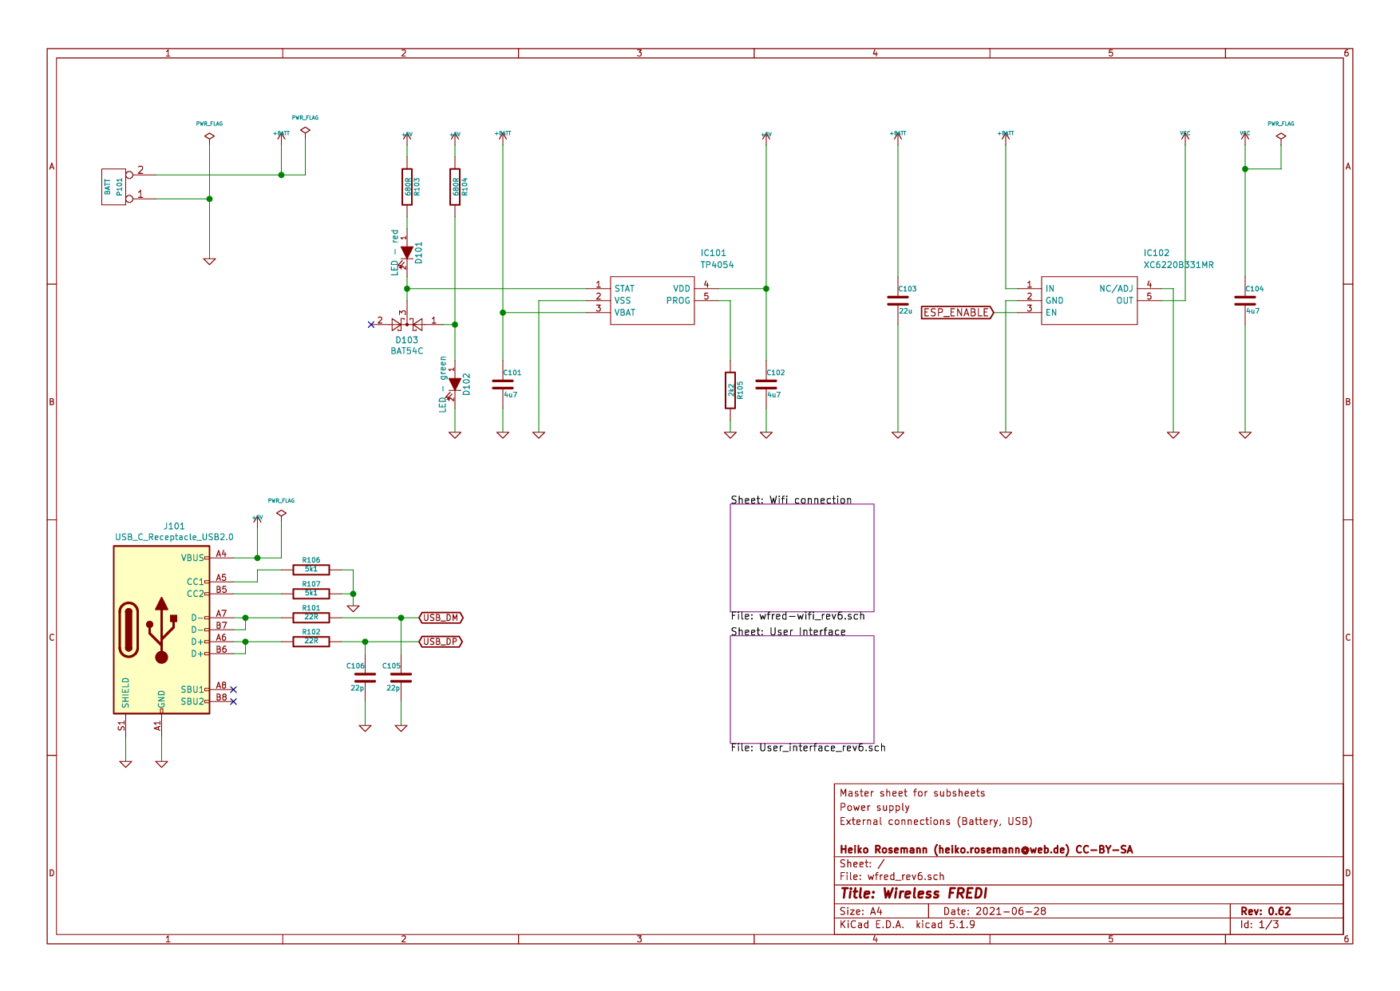
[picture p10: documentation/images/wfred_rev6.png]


[#schematic06page2]
.Schaltplanseite mit ESP32-S2-WROOM für WLAN-Verbindung, mit Bootloader-Jumper und Verbindung zum Programmierkabel
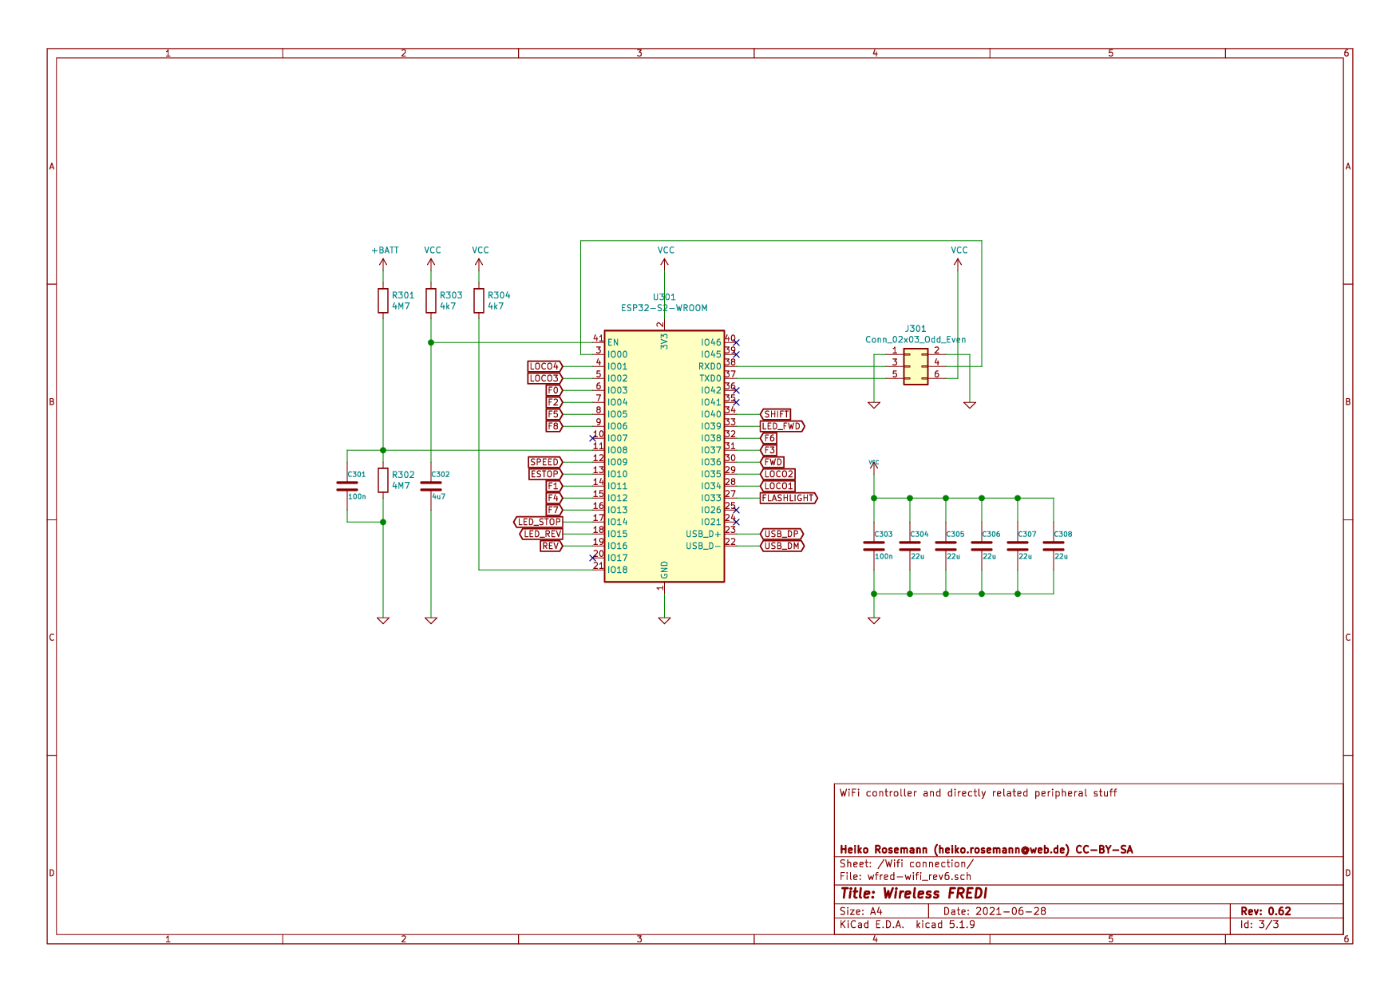
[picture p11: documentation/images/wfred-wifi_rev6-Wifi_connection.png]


[#schematic06page3]
.Schaltplanseite für Benutzeroberfläche (Taster, Schalter, LEDs, Poti und Taschenlampe)
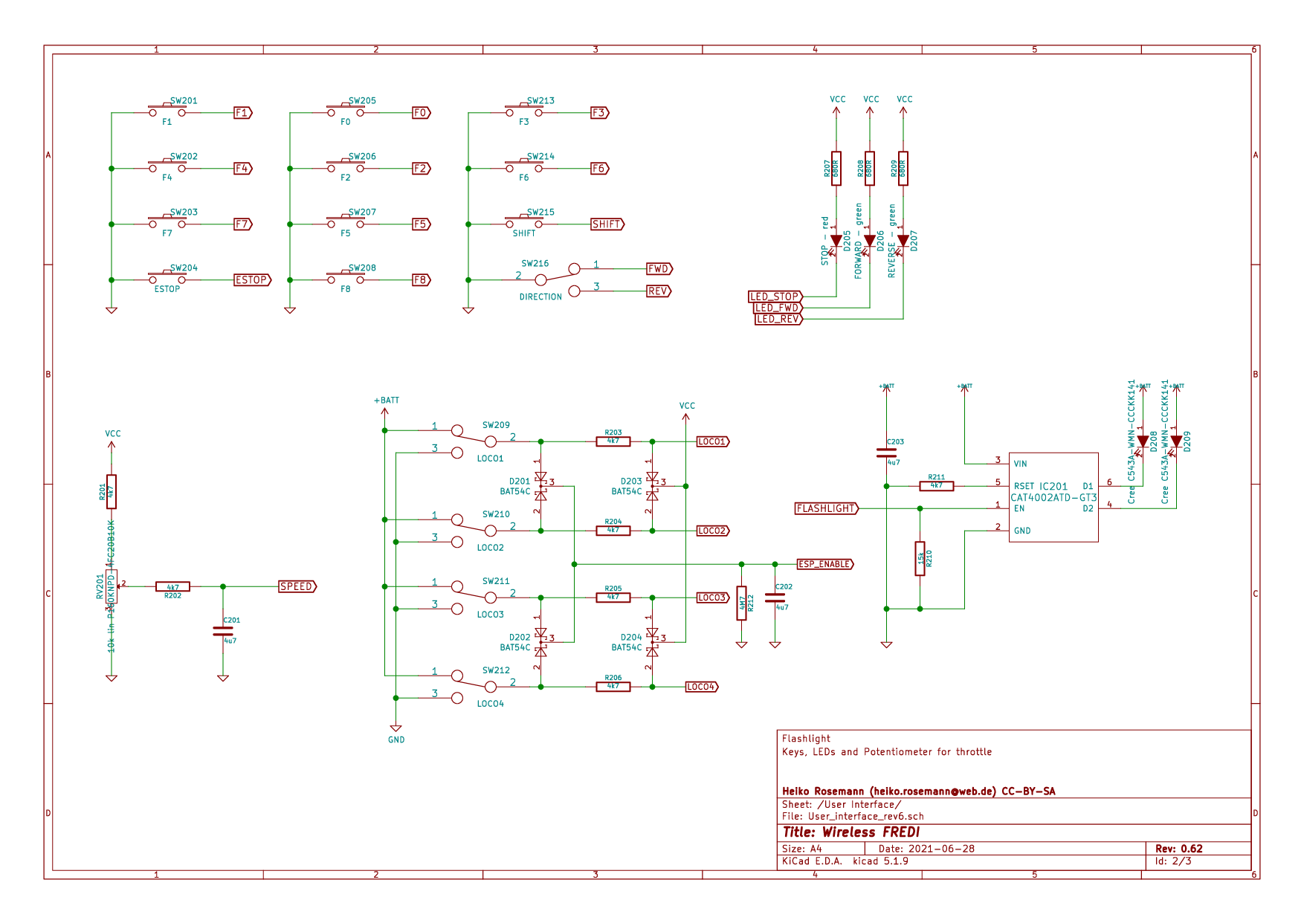
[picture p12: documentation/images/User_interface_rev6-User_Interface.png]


=== Schreiben der Firmware auf den ESP32-S2-WROOM

Um den ESP32-S2 in den Firmware-Flashing-Modus zu versetzen, muss vor dem Einschalten ein Jumper auf den BOOT-Pins installiert werden, wie in <<bootJumper06>> gezeigt. Nach dem Eintritt in den Bootloader registriert sich der ESP32-S2 als USB-CDC-Gerät, wenn er an einen PC angeschlossen ist, und kann über diesen programmiert werden. Alternativ kann die serielle Schnittstelle an den TXD/RXD-Pins verwendet werden. Die serielle Schnittstelle muss mit 3,3 V-Pegel arbeiten, wie von einem FTDI232-Gerät, das mit 3,3 V betrieben wird.

[#bootJumper06]
.Position des Boot-Jumpers - links vom 0.6 Prototyp, rechts von 0.62 Rendering
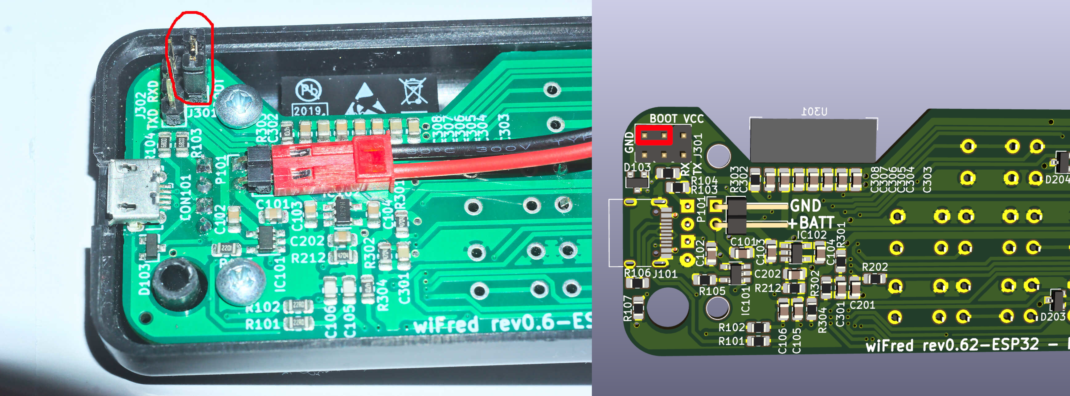
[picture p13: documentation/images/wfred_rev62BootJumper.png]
Boot jumper for 0.6 wiFred


Alle Dateien im Unterverzeichnis software/esp-firmware des <<github>> müssen in einem Ordner abgelegt werden, dann muss die Hauptskizze esp-firmware.ino mit der Arduino IDE geöffnet werden. Die Einstellungen für die Arduino IDE finden Sie in der Hauptdatei, die Programmierung des Geräts sollte über die Schaltfläche Hochladen im Sketch-Menü funktionieren. Eine alternative Lösung mit einer vorkompilierten Firmware und esptool.py kann in Zukunft dokumentiert werden.

=== Tipps zum Aufbau der Revision 0.6

Alle SMD-Teile und Steckverbinder in <<BOM06SMD>> befinden sich auf der Unterseite, so dass sie einfach von einem automatisierten PCB-Bestückungsservice installiert werden können. Gerber-Dateien und Speicherortdateien werden im <<github>> zur Verfügung gestellt. Sie sind jedoch nicht kleiner als 0805, so dass es auch für erfahrene Elektronik-Hobbyisten möglich sein sollte, sie von Hand zu löten, obwohl der USB-C-Stecker einen sehr kleinen Pitch hat.

[#BOM06SMD]
[cols="1,2,1",options="breakable,autowidth"]
.Liste der Komponenten auf der Unterseite - SMDs und Stiftleisten - für den wiFred ab revision 0.6
|===
|Designator|Package|Designation

|C106, C105|C_0805_2012Metric_Pad1.15x1.40mm_HandSolder|22p

|C201, C302, C102, C203, C202, C104, C101|C_0805_2012Metric_Pad1.15x1.40mm_HandSolder|4u7

|C303, C301|C_0805_2012Metric_Pad1.15x1.40mm_HandSolder|100n

|C308, C307, C306, C305, C103, C304|C_0805_2012Metric_Pad1.15x1.40mm_HandSolder|22u

|D103, D204, D203, D202, D201|SOT-23|BAT54C

|IC101|SOT-23-5_HandSoldering|TP4054

|IC102|SOT-23-5_HandSoldering|XC6220B331MR

|IC201|SOT-23-6_Handsoldering|CAT4002ATD-GT3

|J101|USB_C_Receptacle_HRO_TYPE-C-31-M-12|USB_C_Receptacle_USB2.0

|J301|PinHeader_2x03_P2.54mm_Vertical|Conn_02x03_Odd_Even

|P101|PinHeader_1x02_P2.54mm_Horizontal|BATT

|R102, R101|R_0805_2012Metric_Pad1.15x1.40mm_HandSolder|22R

|R103, R209, R208, R207, R104|R_0805_2012Metric_Pad1.15x1.40mm_HandSolder|680R

|R105|R_0805_2012Metric_Pad1.15x1.40mm_HandSolder|2k2

|R107, R106|R_0805_2012Metric_Pad1.15x1.40mm_HandSolder|5k1

|R212, R302, R301|R_0805_2012Metric_Pad1.15x1.40mm_HandSolder|4M7

|R303, R304, R206, R211, R205, R204, R203, R202, R201|R_0805_2012Metric_Pad1.15x1.40mm_HandSolder|4k7

|===

Dann - wie <<BOM06TOP>> gezeigt - gibt es nur das ESP32-S2-WROOM-Modul auf der Oberseite der Leiterplatte und alle Schalter, Drucktasten, Potentiometer und LEDs. Nach der Installation des ESP32-S2-WROOM sollte der Richtungsschalter zuerst mit einer 8-mm-Sechskantmutter in die Leiterplatte geschraubt, dann mit den Abschnitten der LEDs an den Pads befestigt und das Geschwindigkeitspotentiometer mit einer 10-mm-Sechskantmutter in die Leiterplatte geschraubt werden, bevor die Leitungen gelöt werden.

Bei allen anderen Schaltern, Tastern und LEDs empfiehlt es sich, zuerst die Löcher in das Gehäuse zu bohren, dann die Teile auf die Leiterplatte zu legen und die Leiterplatte vor dem Löten der Teile in das Gehäuse zu schrauben. Löcher für die Tasterschalter sollten mit einem Durchmesser von 3,5 mm gebohrt werden. Löcher für die LEDs sollten bei 3 mm Durchmesser und Löcher für das Drehzahlpotentiometer bei 8 mm, für den Richtungsschalter bei 6,5 mm Durchmesser gebohrt werden. Die Ausschnitte für die Lokauswahlschalter werden am besten mit 1,5 mm gebohrt und mit einer Laubsäge oder einem scharfen Hobbymesser und einer Feile ausgearbeitet. Der einfachste Ansatz ist ein lasergraviertes Gehäuse - PDF- und DXF-Dateien der Markierungen sind auch im <<github>> verfügbar.

[#BOM06TOP]
[cols="1,2,1",options="breakable,autowidth"]
.Liste der Komponenten auf der Oberseite - ESP32-S2-WROOM und Benutzerschnittstelle - für den wiFred ab revision 0.6
|===
|Designator|Package|Designation

|D101|LED_D3.0mm|LED - red

|D102|LED_D3.0mm|LED - green

|D205|LED_D3.0mm|STOP - red

|D206|LED_D3.0mm|FORWARD - green

|D207|LED_D3.0mm|REVERSE - green

|D208|LED_D5.0mm_Horicontal_FLIPPED_O1.27mm|Cree C543A-WMN-CCCKK141

|D209|LED_D5.0mm_Horizontal_O1.27mm_Z3.0mm_Clear|Cree C543A-WMN-CCCKK141

|RV201|P160KNPD|10k lin P160KNPD-4FC20B10K

|SW201|SW_PUSH_6mm_H9.5mm|F1

|SW202|SW_PUSH_6mm_H9.5mm|F4

|SW203|SW_PUSH_6mm_H9.5mm|F7

|SW204|SW_PUSH_6mm_H9.5mm|ESTOP

|SW205|SW_PUSH_6mm_H9.5mm|F0

|SW206|SW_PUSH_6mm_H9.5mm|F2

|SW207|SW_PUSH_6mm_H9.5mm|F5

|SW208|SW_PUSH_6mm_H9.5mm|F8

|SW209|OS102011MS2Q|LOCO1

|SW210|OS102011MS2Q|LOCO2

|SW211|OS102011MS2Q|LOCO3

|SW212|OS102011MS2Q|LOCO4

|SW213|SW_PUSH_6mm_H9.5mm|F3

|SW214|SW_PUSH_6mm_H9.5mm|F6

|SW215|SW_PUSH_6mm_H9.5mm|SHIFT

|SW216|100SP1T1B1M1QEH|DIRECTION

|U301|ESP32-S2-WROVER-HandSoldering|ESP32-S2-WROOM

|===

Um eine vollständige Stückliste zu bilden, schließen Sie auch die <<BOM06extra>> aufgeführten Teile ein, die nicht auf die Leiterplatte gelötet, sondern später in der Montage verwendet werden.

[#BOM06extra]
[cols="1,2,1"]
.Liste der Komponenten für die ab Revision 0.6 ohne elektronische Teile zum Löten auf Leiterplatte
|===
|Designator|Package|Designation

|B1|Battery|Lithium battery 1700mAh

|H1a|Housing black|Strapubox 2090

|or H1b|Housing white|Strapubox 2090

|J1|Jumper|

|K1a|Potentiometer Knob silver|24mm

|or K1b|Potentiometer Knob black|24mm

|P1|PCB|124mm x 35mm x 1.6mm

|S1, S2, S3, S4|Mounting Screws|2,9mm x 6,5mm

|===

Nach der Bestückung der Leiterplatte mit allen Komponenten müssen die Löcher und Ausschnitte im Gehäuse höchstwahrscheinlich überarbeitet / verlängert werden, um tatsächlich zu der Leiterplatte zu passen. Dann kann die Leiterplatte mit vier Schrauben in das Gehäuse geschraubt werden. Danach sollte die Batterie an den BATT-Stecker angeschlossen werden. Dabei ist sicherzustellen, dass die Ausrichtung korrekt ist, wie in <<battConnection06>> gezeigt und auf die Platine gedruckt. Der schwarze Draht ist GND, der rote Draht ist der positive. Dann sollte die Batterie mit doppelseitigem Klebeband auf die Unterseite des Gehäuses geklebt werden, damit sie nicht mit Teilen auf der Leiterplatte kollidiert. insbesondere den Stiftleisten und der Richtungsschalter.

[#battConnection06]
.Anschluss der Batterie an P101 ab Revision 0.6 - schwarzer Draht ist GND, roter Draht ist Plus
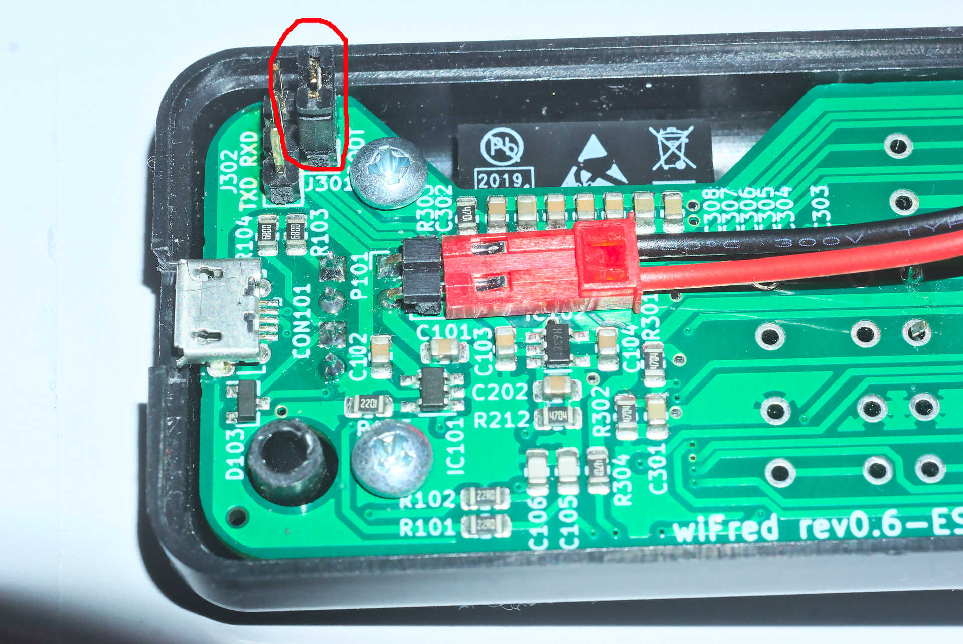
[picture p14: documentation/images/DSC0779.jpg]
Battery connection


[#drilljigPicture]
.Verwendung der Originalplatine und der Bohrvorrichtung, um die Positionen der Löcher auf das Gehäuse zu übertragen - bessere Ergebnisse werden erzielt, wenn die Leiterplatten festgeschraubt werden
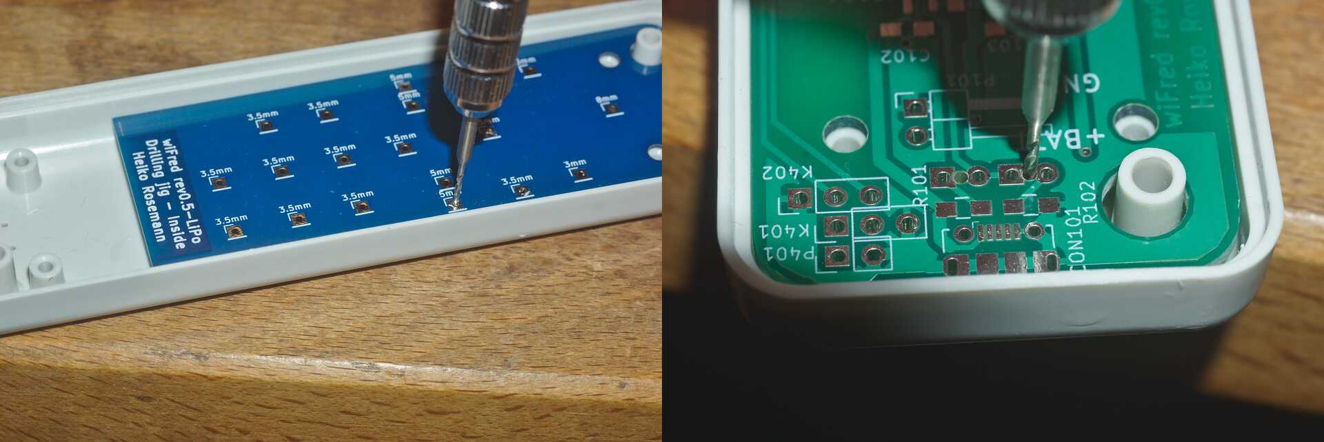
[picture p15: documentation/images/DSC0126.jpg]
Drilljig


[#battConnection]
.Anschluss der Batterie an P101 auf Revision 0.4 - schwarzer Draht ist GND, roter Draht ist Plus
Battery connection

=== Bis Revision 0.5

Die wiFred-Hardware ist um einen ESP8266 für die WLAN-Verbindung zentriert. Der ESP8266 kommuniziert über seine serielle Schnittstelle mit einem ATMega 328P-Mikrocontroller, der die Stromversorgung verwaltet, die LEDs steuert, die Lokwahlschalter, das Drehzahlpotentiometer, den Richtungsschalter und die Drucktastenschalter für Funktionen und Not-Halt liest. Die Kommunikation erfolgt über einen 2x3-Pin-Header, der es dem Benutzer ermöglicht, ein Programmierkabel an dieselbe serielle Schnittstelle anzuschließen, wenn die Jumper entfernt werden.

Optional können zwei weiße 5 mm-LEDs, die aus der Oberseite der Leiterplatte herausragen, als Taschenlampe installiert werden. Sie werden von einer Konstantstromquelle direkt aus dem Akku betrieben und beim Drücken der gelben SHIFT-Taste aktiviert.

Der wiFred wird von einem Einzelzellen-LiPo-Akku angetrieben. Der ATMega 328P wird direkt an die LiPo-Zelle angeschlossen und wechselt in den Ruhezustand, wenn kein Lokwahlschalter aktiv ist, wodurch der Stromverbrauch auf weniger als 1 μA reduziert wird. Der ESP8266 wird von einem linearen Spannungsregler mit einer Ausgangsspannung von 3 V gespeist, der vom ATMega 328P deaktiviert wird, wenn das Gerät in den Standby-Modus wechselt.

Der Schaltplan ist in mehrere Seiten aufgeteilt und findet sich in <<schematic05page1>> bis <<schematic05page4>>. Er wurde mit kicad erstellt und ist zusammen mit dem PCB-Design im <<github>> verfügbar.

[#schematic05page1]
.Schaltplanseite mit Batterieanschluss, Ladeschaltung und Netzteil
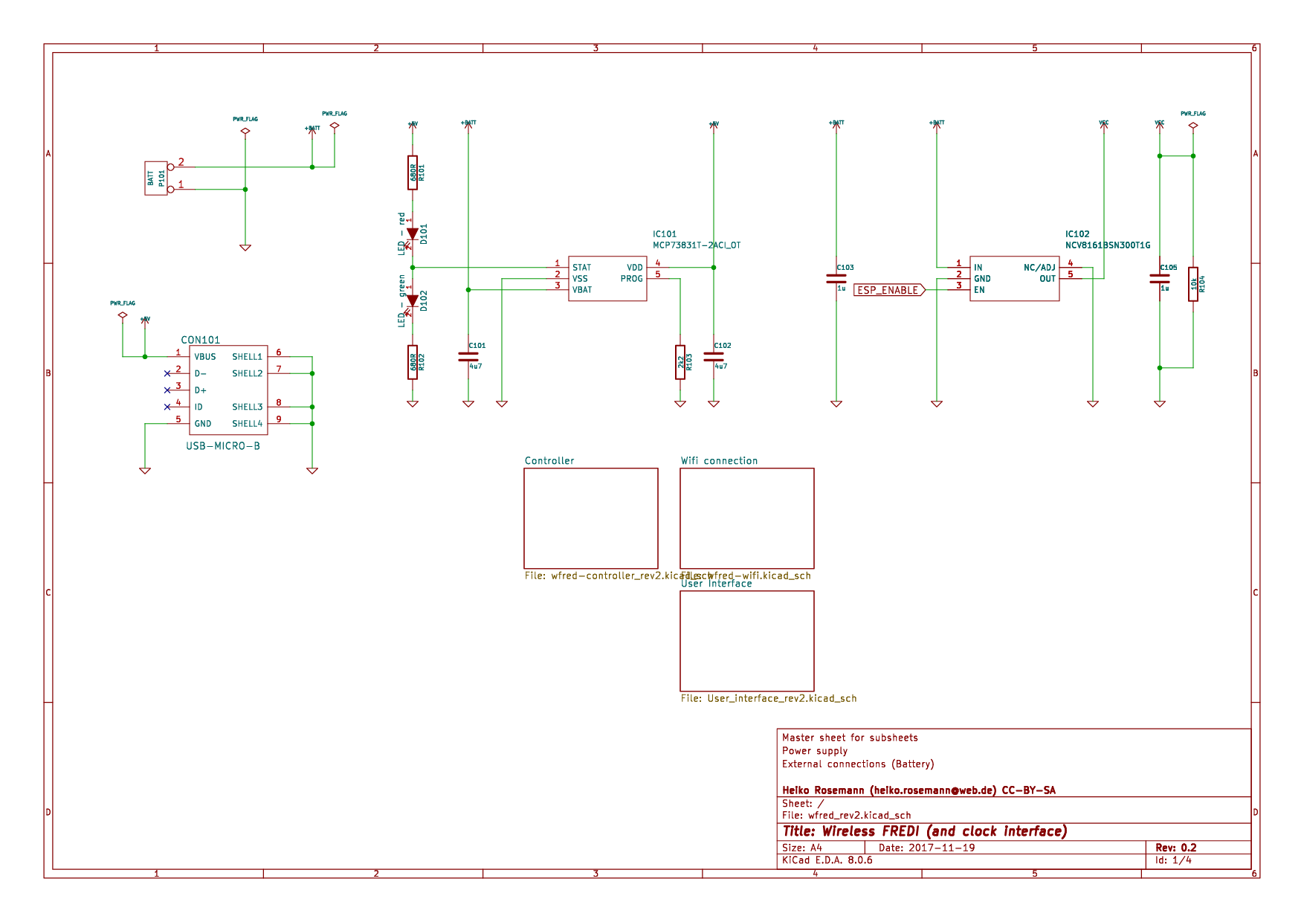
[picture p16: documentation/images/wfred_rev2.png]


[#schematic05page2]
.Schaltplanseite mit ESP8266 für WLAN-Verbindung mit Bootloader-Jumper und Verbindung zum Programmierkabel
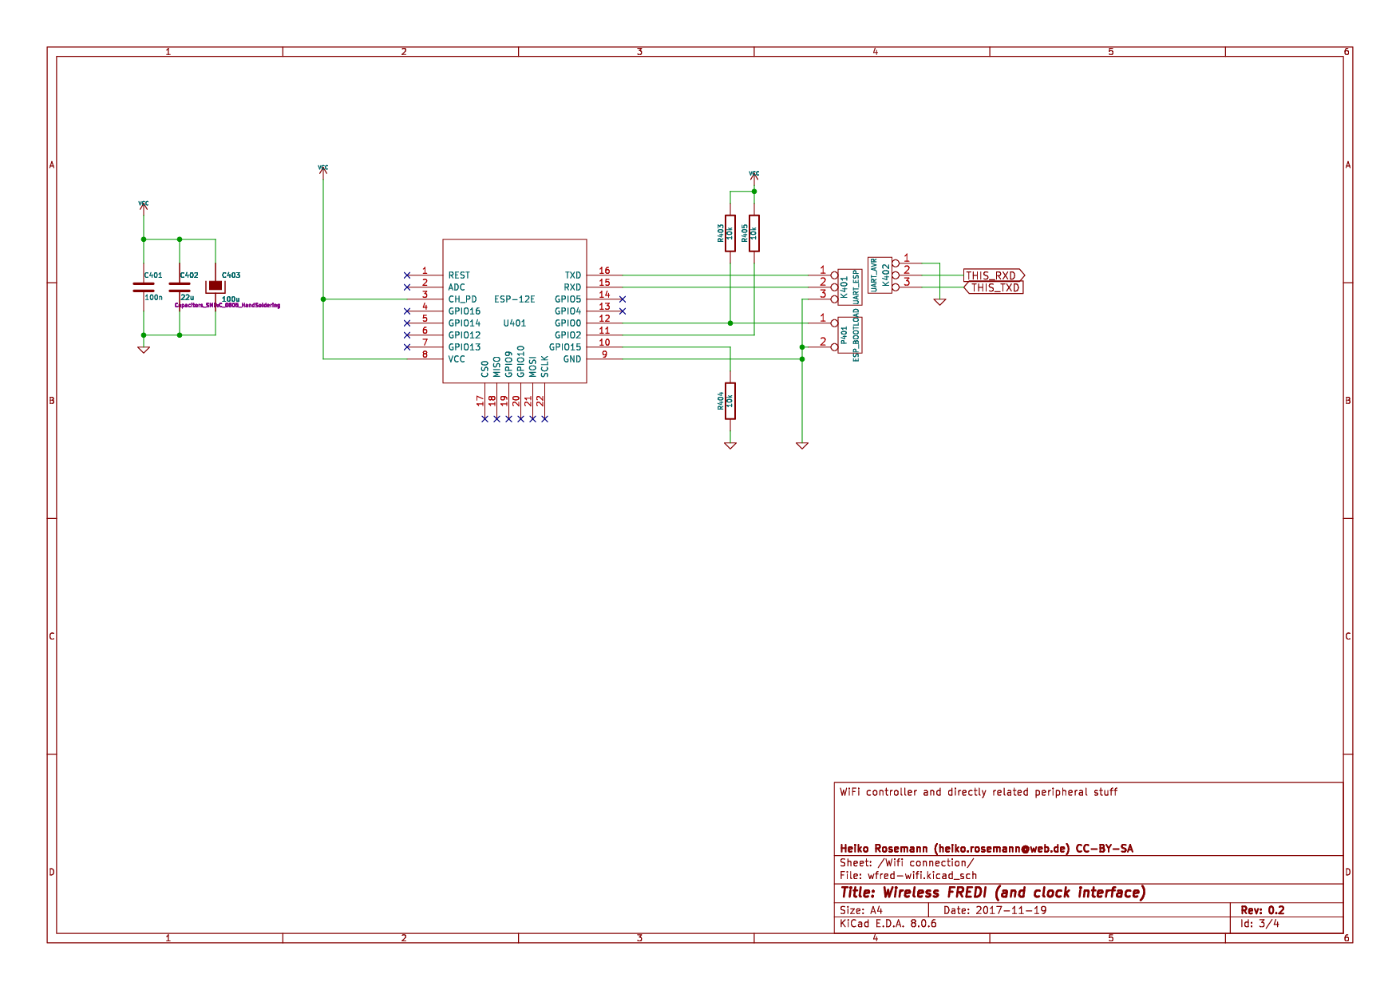
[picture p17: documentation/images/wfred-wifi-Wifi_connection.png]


[#schematic05page3]
.Schaltplanseite mit ATMega 328P zusammen mit Quartz und in ISP-Anschluss
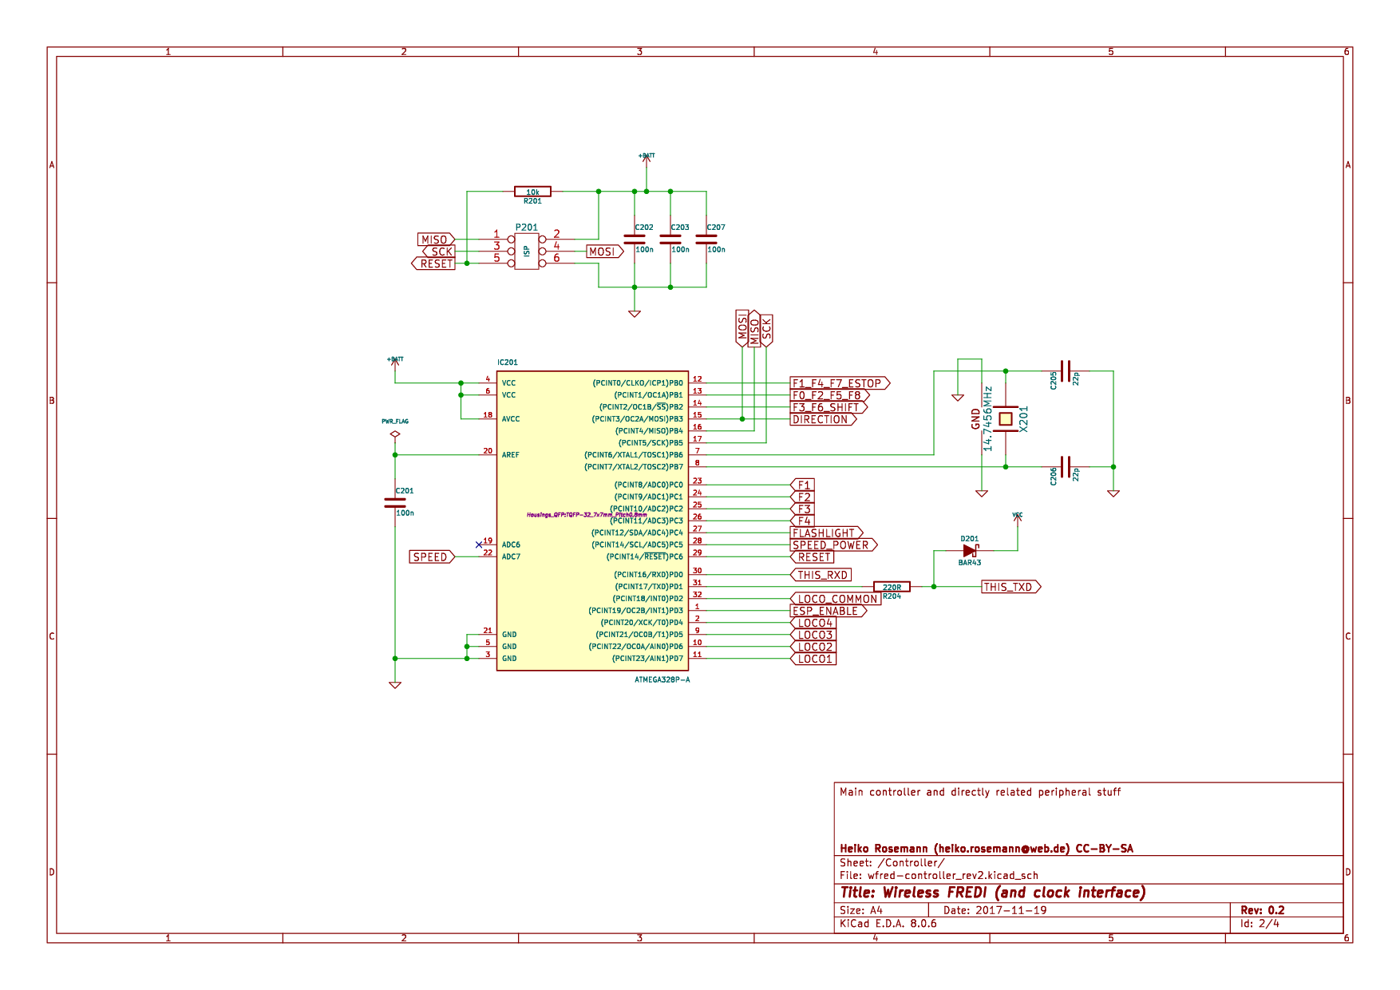
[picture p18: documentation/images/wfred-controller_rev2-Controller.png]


[#schematic05page4]
.Schaltplanseite mit Tastern, Lokwahlschaltern, Richtungsschalter, Drehzahlpotentiometer und Taschenlampen-LEDs mit Controller
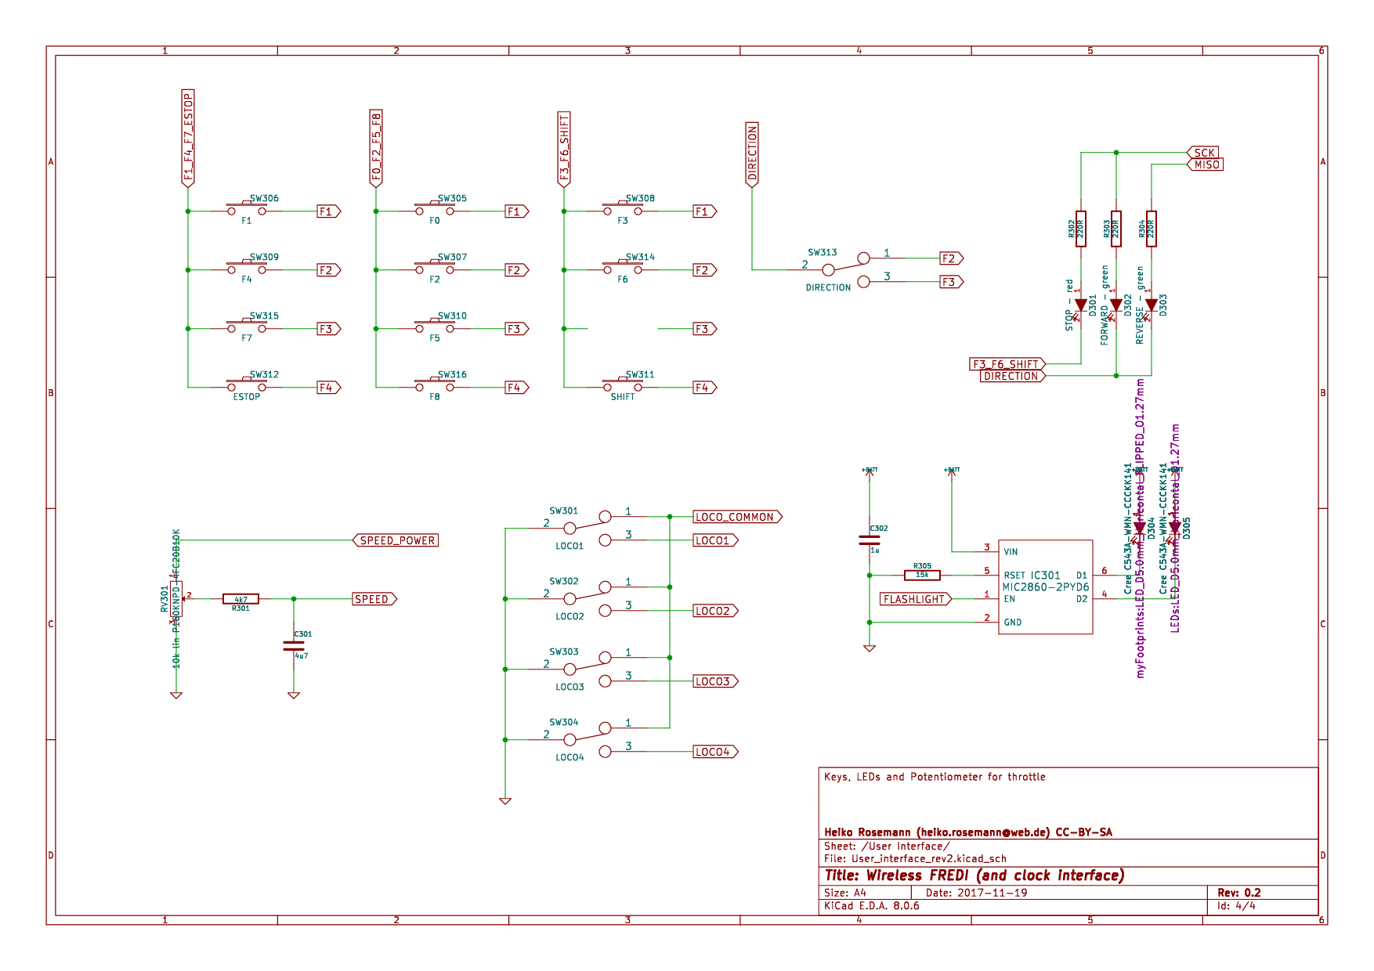
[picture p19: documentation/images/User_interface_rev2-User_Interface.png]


include::fix05matrix_de.adoc[leveloffset=+2,lines=1]
include::fix05matrix_de.adoc[leveloffset=+2,tag=largefile]

[#hintsFor05]
=== Tipps zum Aufbau der Revision bis 0.5

Die Leiterplatte hat Löcher in der Mitte der LED-Footprints, um ihre Positionen mit einer scharfen Nadel auf ein StrapuBox-Gehäuse zu übertragen oder Zentrierlöcher mit einem 1-mm-Bohrer zu bohren. Für alle anderen Löcher steht eine Bohrvorrichtung zur Verfügung, die auch das Bohren von Zentrierlöchern für die Taster, den Richtungsschalter und das Drehzahlpotentiometer ermöglicht. <<drilljigPicture>> zeigt den Prozess und seine Ergebnisse. Löcher für die Taster sollten mit einem Durchmesser von 3,5 mm gebohrt werden. Löcher für die LEDs sollten bei 3 mm Durchmesser und Löcher für das Drehzahlpotentiometer bei 8 mm, für den Richtungsschalter bei 6,5 mm Durchmesser gebohrt werden. Die Ausschnitte für die Lokauswahlschalter werden am besten bei 1,5 mm gebohrt und mit einer Laubsäge oder einem scharfen Hobbymesser und einer Feile auf die Leiterplatte angepasst.

[#BOM05]
[cols="1,2,1",options="breakable,autowidth"]
.Bauteile für die wiFred-Platine bis Revision 0.5
|===
|Designator|Package|Designation

|C102, C101|C_0805_HandSoldering|4u7

|C105, C103, C302|C_0805_HandSoldering|1u

|C206, C205|C_0805_HandSoldering|22p

|C401, C203, C202, C201, C207|C_0805_HandSoldering|100n

|C402, C301|C_0805_HandSoldering|22u

|C403|C_0805_HandSoldering|100u

|CON101|USB_Micro-B_Molex-105017-0001|USB-MICRO-B

|D101|LED_D3.0mm|LED - red

|D102|LED_D3.0mm|LED - green

|D201|SOT-23_Handsoldering|BAR43

|D301|LED_D3.0mm|STOP - red

|D302|LED_D3.0mm|FORWARD - green

|D303|LED_D3.0mm|REVERSE - green

|D303, D302, D301, D101, D102|LED Spacer|3mm

|D304|LED_D5.0mm_Horicontal_FLIPPED_O1.27mm|LED white

|D305|LED_D5.0mm_Horicontal_O1.27mm|LED white

|IC101|SOT95P270X145-5N|MCP73831T-2ACI_OT

|IC102|SOT95P275X110-5N|NCV8161BSN300T1G

|IC201|TQFP-32_7x7mm_Pitch0.8mm|ATMEGA328P-A

|IC301|SOT-23-6_Handsoldering|MIC2860-2PYD6

|K401|Pin_Header_Straight_1x03_Pitch2.54mm|UART_ESP

|K402|Pin_Header_Straight_1x03_Pitch2.54mm|UART_AVR

|P1|PCB|124mm x 35mm x 1.6mm

|P101|Pin_Header_Angled_1x02_Pitch2.54mm|BATT

|P201|Pin_Header_Straight_2x03_Pitch2.54mm_SMD|ISP

|P401|Pin_Header_Straight_1x02_Pitch2.54mm|ESP_BOOTLOAD

|R101, R102|C_0805_HandSoldering|680R

|R103|C_0805_HandSoldering|2k2

|R301|C_0805_HandSoldering|4k7

|R304, R303, R302, R204|C_0805_HandSoldering|220R

|R305|C_0805_HandSoldering|15k

|R405, R404, R403, R201, R104|C_0805_HandSoldering|10k

|RV301|P160KNPD|10k lin P160KNPD-4FC20B10K

|SW301|OS102011MS2Q|LOCO1

|SW302|OS102011MS2Q|LOCO2

|SW303|OS102011MS2Q|LOCO3

|SW304|OS102011MS2Q|LOCO4

|SW305|SW_SPST_PTS645|F0

|SW306|SW_SPST_PTS645|F1

|SW307|SW_SPST_PTS645|F2

|SW308|SW_SPST_PTS645|F3

|SW309|SW_SPST_PTS645|F4

|SW310|SW_SPST_PTS645|F5

|SW311|SW_SPST_PTS645|SHIFT

|SW312|SW_SPST_PTS645|ESTOP

|SW313|100SP1T1B1M1QEH|DIRECTION

|SW314|SW_SPST_PTS645|F6

|SW315|SW_SPST_PTS645|F7

|SW316|SW_SPST_PTS645|F8

|U401|ESP-12E_SMD|ESP-12E

|X201|Crystal_SMD_TXC_7M-4pin_3.2x2.5mm_HandSoldering|14.7456MHz

|===

Der weitere Aufbau ist die Installation aller Komponenten auf der Leiterplatte, die in <<BOM05>> aufgeführt sind. Aus Erfahrung mit der Montage der Prototypen empfiehlt sich die folgende Reihenfolge der Komponenten:

. IC101, IC102, IC201 (Hinweis: PCB drehen, so dass Designator rechts nach oben ist, dann Pin 1 oben links) und IC301

. X201 und D201

. USB-Anschluss CON101

. Kondensatoren und Widerstände in der Größe 0805 (zuerst die auf der gleichen Seite wie die Bauteile zuvor)

. U401

. Kondensatoren und Widerstände, die zuvor nicht installiert wurden - das sind R403, R404, R405, C401, C402 und C403

. Taster SW305 bis SW312 und SW314 bis SW316 - achten Sie darauf, den roten bei SW312 und den gelben bei SW311 zu platzieren

. Stiftleiste K401, K402 und P401 (korrekte Ausrichtung von K401 und K402 kann durch Hinzufügen eines Jumpers vor dem Löten sichergestellt werden)

. Pin-Header P101 und P201

. Lokauswahlschalter SW301 bis SW304

. LEDs D101, D102 und D301 bis D303 mit 3mm Abstandshaltern zur Leiterplatte - stellen Sie sicher, dass die Anode (langer Pin) mit dem quadratischen Pad ausgerichtet ist

. LEDs D304 und D305 nach Belieben oben oder unten auf der Leiterplatte installiert - stellen Sie sicher, dass die Anode (langer Pin) mit dem quadratischen Pad ausgerichtet ist

. Richtungsschalter SW313 (zuerst mit einer 8 mm Sechskantmutter in die Leiterplatte geschraubt, dann mit den Abschnitten von D301, D302 und D303 an den Pads befestigt) und Geschwindigkeitspotentiometer RV301 (zuerst mit einer 10-mm-Sechskantmutter in die Leiterplatte geschraubt)

Um eine vollständige Stückliste zu bilden, schließen Sie auch die <<BOM05extra>> aufgeführten Teile ein, die nicht auf die Leiterplatte gelötet, sondern später in der Montage verwendet werden.

[#BOM05extra]
[cols="1,2,1"]
.Liste der Komponenten für wiFred bis Revision 0.5 ohne elektronische Teile zum Löten auf Leiterplatte
|===
|Designator|Package|Designation

|B1|Battery|Lithium battery 1700mAh

|H1a|Housing black|Strapubox 2090

|or H1b|Housing white|Strapubox 2090

|J1, J2|Jumper|

|K1a|Potentiometer Knob silver|24mm

|or K1b|Potentiometer Knob black|24mm

|P1|PCB|124mm x 35mm x 1.6mm

|S1, S2, S3, S4|Mounting Screws|2,9mm x 6,5mm

|===

Nach der Bestückung der Leiterplatte mit allen Komponenten müssen die Löcher und Ausschnitte im Gehäuse höchstwahrscheinlich überarbeitet / verlängert werden, um tatsächlich zur Leiterplatte zu passen, dann kann die Leiterplatte mit vier Schrauben in das Gehäuse geschraubt werden. Danach sollte die Batterie an den BATT-Stecker angeschlossen werden. Dabei ist sicherzustellen, dass die Ausrichtung korrekt ist, wie in <<battConnection>> gezeigt und auf die Platine gedruckt. Der schwarze Draht ist GND, der rote Draht ist der positive. Dann sollte die Batterie mit doppelseitigem Klebeband auf die Unterseite des Gehäuses geklebt werden, damit sie nicht mit Teilen auf der Leiterplatte kollidiert. insbesondere den Stiftleisten und der Richtungsschalter.

Schließlich müssen sowohl der ATMega 328P als auch der ESP8266 mit Firmware programmiert werden, wie in <<flashing05>> beschrieben.

[#flashing05]
=== Schreiben der Firmware auf wiFreds der Revision 0.5 und älter

==== AVR firmware

Der ATMega 328P wird über die reguläre AVR ISP-Verbindung auf P201 programmiert. Pin 1 - GND - befindet sich in Richtung des Platinenrandes, wie in <<progAVR>> gezeigt. Ein ISP-Dongle mit automatischer Spannungswahl oder 3,3 V Versorgungsspannung sollte verwendet werden, um zu vermeiden, dass eine zu hohe Spannung auf den ESP8266 gelegt wird, der nur 3,3 V unterstützt. Die Firmware für den ATMega 328P befindet sich im Unterverzeichnis software/avr-firmware des <<github>> mit einer vorkompilierten Hexfile und dem gesamten Quellcode inklusive Makefile, das bei Bedarf neu kompiliert werden kann. Nach dem Schreiben der Firmware-Datei und der eeprom-Datei müssen auch die Fusebits richtig eingestellt werden, wie in der main.c-Datei beschrieben.

[#progAVR]
.Programmieranschluss für ATMega_328P - Pin 1 am violetten Kabel
AVR programmieren

==== ESP8266 firmware

Der ESP8266 wird mit der Arduino-IDE programmiert, die über einen seriellen Port oder einen USB-zu-seriell-Wandler mit dem K401-Header verbunden ist, wie in <<progESP8266>> gezeigt. Die serielle Schnittstelle muss auf 3,3 V-Pegel sein, wie von einem FTDI232-Gerät, das mit 3,3 V betrieben wird. Um den ESP8266 zu programmieren, muss zunächst der ATMega 328P programmiert, eine Batterie angeschlossen und vernünftig geladen werden und einer der Lokauswahlschalter muss in die "aktivierte" Position bewegt werden, um den ESP8266 einzuschalten.

[#progESP8266]
.Programmieranschluss für ESP8266 - GND auf orangefarbenem Draht, dann TXD des Programmierkabels (RXD von ESP8266), dann RXD des Programmierkabels (TXD von ESP8266) - beachten Sie auch den Jumper auf P401
ESP8266 programmieren

Alle Dateien im unterverzeichnis software/esp-firmware des <<github>> müssen in einem Ordner abgelegt werden, dann muss die Hauptskizze esp-firmware.ino mit der Arduino-IDE geöffnet werden. Die Einstellungen für die Arduino IDE finden Sie in der Hauptdatei, die Programmierung des Geräts sollte anschließend über die Schaltfläche *Hochladen* im *Sketch*-Menü funktionieren.

Um den ESP8266 in den Programmiermodus zu versetzen, muss ein Jumper über den P401-Header gelegt werden, bevor der ESP8266 eingeschaltet wird, indem einer der Lokauswahlschalter aktiviert wird, um das Gerät im Programmiermodus zu starten. Die rote STOP-LED sollte anfangen zu blinken und der Bootloader sollte einige Ergebnisse an der seriellen Schnittstelle anzeigen und während des Downloads sollte auch die LED am ESP8266-Modul blinken.

Nach der Programmierung müssen zwei Jumper zwischen den Pin-Headern K401 und K402 platziert werden, um die Kommunikation zwischen dem ESP8266 und dem ATMega 328P zu aktivieren, wie in <<serialJumpers>> gezeigt.

[#serialJumpers]
.Kommunikations-Jumper zur Verbindung zwischen ESP8266 und ATMega 328P
Jumper zur seriellen Verbindung

[#oldThrottle]
=== Erster Prototyp mit AA-Akkus

Die wiFred Prototyp Hardware ist um einen ESP8266 für die WiFi-Verbindung zentriert. Der ESP8266 liest auch die Lokwahlschalter und die Batteriespannung und kommuniziert über seine serielle Schnittstelle mit einem ATMega 328P-Mikrocontroller, der die LEDs steuert, das Drehzahlpotentiometer, den Richtungsschalter und die Drucktastenschalter für Funktionen und Not-Halt liest. Die Kommunikation erfolgt über einen 2x3-Pin-Header, der es dem Benutzer ermöglicht, ein Programmierkabel an dieselbe serielle Schnittstelle anzuschließen, wenn die Jumper entfernt werden.

Der wiFred-Prototyp wird von zwei Batteriezellen der Größe AA angetrieben, die mit einem Step-up-Konverter verbunden sind, der 3,3 V für das gesamte Gerät erzeugt. Sobald ein Paar Batterien in das Batteriefach eingelegt wird, wie die Symbole im Batteriefach zeigen, wird die Drehregler hochgefahren und versucht, eine Verbindung zu einem drahtlosen Netzwerk herzustellen. Die Drehregler wird nicht beschädigt, wenn Batterien falsch eingelegt werden, aber es funktioniert auch nicht. Verwenden Sie NiMH- oder primäre AA-Zellen mit 1,2 V bis 1,5 V Nennspannung, niedrige Selbstentladung NiMH-Zellen wie Eneloop oder ähnliches werden empfohlen.

Der Schaltplan ist in mehrere Seiten aufgeteilt und findet sich in <<oldSchematicPage1>> bis <<oldSchematicPage4>>. Er wurde mit kicad erstellt und ist zusammen mit dem PCB-Design im <<github>> verfügbar.

[#oldSchematicPage1]
.Schaltplanseite mit Batterien und Netzteil
Schematic page 1 for AA battery prototype

[#oldSchematicPage2]
.Schaltplanseite mit ESP8266 für WLAN-Verbindung mit Bootloader-Jumper und Verbindung zum Programmierkabel
Schematic page 2 for AA battery prototype

[#oldSchematicPage3]
.Schaltplanseite mit ATMega 328P zusammen mit Quartz und in ISP-Anschluss
Schematic page 3 for AA battery prototype

[#oldSchematicPage4]
.Schaltplanseite mit Tastern, Lokwahlschaltern, Richtungsschalter und Drehzahlpotentiometer
Schematic page 4 for AA battery prototype

=== Tipps zum Bau des wiFred AA Batterieprototyps

Die Prototyp-Leiterplatte hat Löcher in der Mitte der Taster-Footprints und LED-Footprints, um ihre Positionen mit einer scharfen Nadel oder ähnlichem auf ein StrapuBox-Gehäuse zu übertragen. Die Positionen der Lokauswahlschalter können auch durch Markieren durch die Nicht-Kupferlöcher an ihren Enden auf das Gehäuse übertragen werden. Siehe <<drilljigPicture>> für Bilder und weitere Details, die Unterschiede zwischen dem AA-Batterieprototyp und den LiPo-Batterierevisionen sind in diesem Aspekt minimal.

Der weitere Aufbau ist die Installation aller Komponenten auf der Leiterplatte, die in <<oldWiFredBOM>> aufgeführt sind.

[#oldWiFredBOM]
[cols="1,2,1",options="breakable,autowidth"]
.Liste der Komponenten für AA-Batterie-Prototyp
|===
|Designator|Package|Designation

|B101|KEYSTONE1013|BATT_HOLDER

|C206, C205|C_0805_HandSoldering|22p

|C301, C105, C104, C102, C101, C402|C_0805_HandSoldering|22u

|C401, C204, C203, C202, C201, C103|C_0805_HandSoldering|100n

|D301|LED_D3.0mm|STOP - red

|D302|LED_D3.0mm|FORWARD - green

|D303|LED_D3.0mm|REVERSE - green

|IC201|TQFP-32_7x7mm_Pitch0.8mm|ATMEGA328P-A

|K401|Pin_Header_Straight_1x03_Pitch2.54mm|UART_ESP

|K402|Pin_Header_Straight_1x03_Pitch2.54mm|UART_AVR

|L101|L_2424_HandSoldering|22u

|P201|Pin_Header_Straight_2x03_Pitch2.54mm_SMD|ISP

|P401|Pin_Header_Straight_1x02_Pitch2.54mm|ESP_BOOTLOAD

|R301|C_0805_HandSoldering|4k7

|R304, R303, R302|C_0805_HandSoldering|470R

|R401|C_0805_HandSoldering|100k

|R402|C_0805_HandSoldering|47k

|R405, R404, R403, R201|C_0805_HandSoldering|10k

|RV301|P160KNPD|10k lin P160KNPD-4FC20B10K

|SW301|OS102011MS2Q|LOCO1

|SW302|OS102011MS2Q|LOCO2

|SW303|OS102011MS2Q|LOCO3

|SW304|OS102011MS2Q|LOCO4

|SW305|KSC621G|F0

|SW306|KSC621G|F1

|SW307|KSC621G|F2

|SW308|KSC621G|F3

|SW309|KSC621G|F4

|SW310|KSC621G|SHIFT2

|SW311|KSC621G|SHIFT

|SW312|KSC621G|ESTOP

|SW313|100SP1T1B1M1QEH|DIRECTION

|U101|TSSOP-8_4.4x3mm_Pitch0.65mm|L6920D

|U401|ESP-12E_SMD|ESP-12E

|X201|Crystal_SMD_TXC_7M-4pin_3.2x2.5mm_HandSoldering|14.7456MHz

||Gehäuse StrapuBox 6090|

||Zwei Jumper, 2,54 mm|                                

||Potentiometerknopf, 21 mm|

||Drei Befestigungsschrauben, 2,9 mm Durchmesser x 6,5 mm|

|===

Nach der Montage der Leiterplatte mit allen Komponenten und dem Bohren und Schneiden der Löcher und Ausschnitte in das Gehäuse sind nur noch wenige Schritte übrig. Zuerst müssen einige Vorsprünge im Inneren des Gehäuses entfernt werden, damit die Leiterplatte richtig passt. <<breakProtrusions>> zeigt, wie sie leicht entfernt werden können, Reste können mit einem Hobbymesser abgeschnitten werden. Zweitens müssen neue PCB-Montagepads installiert werden, wie in <<#mountingPads>> gezeigt. Für den Prototyp wurde Forex PVC-Schaum verwendet, mit einer Schere geschnitten und mit Sekundenkleber auf das Gehäuse geklebt, um sicherzustellen, dass keine Komponenten auf der Leiterplatte im Weg sind, aber jede Art von leicht zu arbeitendem Material mit einer Dicke von 3 mm kann verwendet werden, solange es selbstschneidende Schrauben nimmt (Prototyp verwendet 2,9 mm x 6,5 mm DIN 7981 Schrauben). Drittens benötigen die beiden Shiftttasten gelbe Farbe auf der Oberseite und die Nothalt-Taste rote Farbe - entweder irgendeine Art von Farbe oder ein Farbmarker wie Edding 751. Schließlich müssen sowohl der ESP8266 als auch der ATMega 328P wie in <<flashing05>> beschrieben programmiert werden.

[#breakProtrusions]
.Entfernen von Vorsprüngen im Gehäuse, damit die Leiterplatte passt
Vorsprünge im Gehäuse abbrechen

[#mountingPads]
.Neue PCB-Montagepads aus 3 mm starkem Forex PVC
Neue Platinenhalter

[#background]
== Hintergrund für die wiFred-Entwicklung

Zum Zeitpunkt des Schreibens dieses Dokuments hat <<JMRI>> bereits eine lange Erfolgsbilanz bei der Bereitstellung eines Servers für die Verwendung von Smartphones als drahtlose Modelleisenbahn-Handregler, zusammen mit Apps wie <<wiThrottleApp>>footnote:[wiThrottle ist auch der Name, den JMRI für das Protokoll und den Server verwendet.] und <<EngineDriver>>. Dieser Server ermöglicht WLAN-Handregler, um Loks jedes Modelleisenbahnlayout zu steuern, zu dem JMRI eine Verbindung aufbauen kann <<jmrihardwaresupport>>. Darüber hinaus bieten <<Digitrax>> und <<MRC>> spezifische Hardwarelösungen an, um die Verbindung der oben genannten Smartphone-Apps mit ihren DCC-Systemen über ein WLAN-Netzwerk zu ermöglichen.

Der <<Fremo>> ist ein europäischer modularer Modelleisenbahnclub, dessen einzigartige Anforderungen an seine DCC-Handregler zur Schaffung der Handregler <<FRED>> und <<FREDI>> führten - eine Reihe von LocoNet-Handregler, die als Hobbyprojekte mit großen Stückzahlen im Umlauf begannen, später von <<Uhlenbrock>> kommerziell erhältlich waren.

=== Spezifikation Wunschliste

Bei modularen Eisenbahnveranstaltungen, insbesondere der Fremo-americaN-Gruppe, haben mehrere Personen die Smartphone-Handregler-Apps ausprobiert und festgestellt, dass ihnen ein schönes, haptisches Feedback fehlt. Aber die Idee der drahtlosen Steuerung ohne Bindung an einen bestimmten Anbieter und deren notwendigerweise teure Ausrüstung fand große Zustimmung. Also wurde eine Wunschliste zusammengestellt, um die Anforderungen an eine drahtlose Drehregler zu definieren:

- Gleicher Formfaktor wie der <<FRED>> mit ähnlicher Bedienung

- Möglichkeit, mindestens zwei, bessere vier Lokomotiven für Doppel-/Dreifachtraktion zu steuern (ähnlich dem Duo-FREDI)

- Akkulaufzeit von mindestens sechs Stunden

- Austauschbare Batterien, so dass, wenn der Akku leer ist, sie schnell gegen ein geladenes Set oder billige Primärzellen ausgetauscht werden können

- Einfache Konfiguration, aber nicht zu einfach, um zu verhindern, dass Bediener versehentlich andere Lokomotiven auswählen

- So wenig Änderung am bestehenden Fremo Loconet Netzwerk wie möglich

- Verwendung des wiThrottle-Protokolls, so dass davon ausgegangen werden kann, dass die Serverseite der Kommunikation funktioniert und nicht ebenso entwickelt werden muss

=== Entwicklungsgeschichte

Die ersten Prototypen des wiFred wurden so gebaut, dass sie mit zwei AA-Zellen betrieben werden, entweder Batterien oder wiederaufladbaren NiMH-Akkus. Wie in <<oldThrottle>> beschrieben, erforderte dies einige spezielle Anpassungen des Gehäuses, um alle Komponenten unterzupassen. Schon damals zeigte die Erfahrung mit den Prototypen, dass die Batteriefachabdeckung nicht wirklich passte und beim Versuch, das Batteriefach zu öffnen und zu schließen, leicht kaputt ging.

So wurden die nächsten Versionen um einen integrierte Lithiumakku herum entwickelt, womit die Option verloren ging, leere Batterien einfach auszutauschen. Dafür war die Laufzeit länger und die Elektronik passte richtig in das Gehäuse. Das Aufladen der zweiten Generation erfolgt über einen Micro-USB-Anschluss, so dass eine Powerbank die Laufzeit des Geräts verlängern kann, wenn der interne Akku erschöpft ist. Außerdem fungieren die Lokauswahlschalter mehr als ein Netzschalter als bei den ersten Prototypen und reduzieren den Stromverbrauch auf einen vernachlässigbaren Betrag, wenn alle Loks deaktiviert sind.

Der neueste Prototyp wird von zwei Prozessoren auf einen einzigen, neuen ESP32-S2-Prozessor umgestellt, was Platz spart, die Anzahl der Komponenten reduziert, alle SMD-Komponenten auf einer Seite der Leiterplatte platziert und einen direkten USB-Firmware-Download ermöglicht. Es wird keine neuen Funktionen gegenüber den früheren LiPo-Akkuversionen enthalten, aber hauptsächlich für den Bastler einfacher zu bauen sein.

=== Drahtlose Uhr

Während der Entwicklung dieses wiFred kam in der americaN-Gruppe der Fremo ein weiteres Thema auf, nämlich drahtlose Uhren mit einstellbarer Taktrate für Timetable & Trainorder-Betrieb. Dies führte zur Ausgliederung des <<wiClock>>-Projekts.

[bibliography]
== Quellen

- [[[github,Github repository für wiFred]]] newHeiko/wiFred: wiThrottle-compatible hardware controller, https://github.com/newHeiko/wiFred

- [[[JMRI]]] JMRI: A Java Model Railroad Interface, https://www.jmri.org

- [[[jmrihardwaresupport,Supported Hardware]]] JMRI: Hardware Support, https://www.jmri.org/help/en/html/hardware/index.shtml

- [[[wiThrottleApp,wiThrottle]]] WiThrottle, https://www.withrottle.com/html/home.html

- [[[EngineDriver]]] Home | EngineDriver, https://enginedriver.mstevetodd.com/

- [[[Fremo]]] Home - FREMO - Freundeskreis Europäischer Modelleisenbahner e.V., https://www.fremo-net.eu/

- [[[FRED]]] FRED, http://fremodcc.sourceforge.net/diy/fred/fred_d.html

- [[[FREDI]]] FREDI, http://fremodcc.sourceforge.net/diy/fred2/fredi_d.html

- [[[Uhlenbrock]]] Uhlenbrock | FRED, der Handregler für die Intellibox, https://uhlenbrock.de/de_DE/produkte/prodarch/I62AD172-001.htm!ArcEntryInfo=0004.41.I62AD172

- [[[Digitrax,Digitrax LNWI]]] LocoNet WiFi interface, https://www.digitrax.com/products/wireless/lnwi/

- [[[MRC,MRC Prodigy WiFi]]] Prodigy WiFi, https://www.modelrectifier.com/Prodigy-WiFi-s/332.htm

- [[[rpiImage,Steve Todd]]] JMRI RaspberryPi as Access Point | M Steve Todd, https://mstevetodd.com/rpi

- [[[wiClock]]] wiClock, a WiFi-JMRI-Clock, zu finden unter https://github.com/newHeiko/WiFi-JMRI-Clock und Dokumentation unter https://newHeiko.github.io/WiFi-JMRI-Clock

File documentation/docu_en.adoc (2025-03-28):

= wiFred: WiFi throttle for model railroads using the wiThrottle protocol
Heiko Rosemann
0.3, 6-27-2021: Added v0.6 description
:description: Usage documentation, server choices, building instructions, schematics, part lists...
:url-repo: https://github.com/newHeiko/wiFred
:icons: image
:iconsdir: images/icons/
:imagesdir: images/
:toc:

wiFred with laser engraved housing

[abstract]
== Abstract

This document describes the usage and configuration of the wiFred - a very simple wireless throttle for model railroads to connect to wiThrottle servers like JMRI. It also contains schematics and BOMs for the device - for both LiPo battery versions in active development - as well as programming instructions and assembly tips, and also an overview of options for the server side of things.

The most recent version of this document can be found at https://newheiko.github.io/wiFred, https://github.com/newHeiko/wiFred/raw/master/documentation/docu_en.pdf and https://github.com/newHeiko/wiFred/blob/master/documentation/docu_en.adoc.

If you want to know more about the development history of the wiFred, skip ahead to <<background>> - otherwise read on with <<throttle>>.

[#throttle]
== Quickstart Guide

include::quickBuild.adoc[leveloffset=+1,tags=!drilljig]
include::quickBuild.adoc[leveloffset=+1,tags=!laser]
include::quickStartup.adoc[leveloffset=+1]

== Usage

=== Operating locos

[#ledTable]
[cols="1,1,1,3"]
.LED patterns and their meaning on the wiFred
|===
|Red LED|Green LED (Left)|Green LED (Right)|Status

|Slow Blinking (0.5 Hz)|Off|Off|Trying to connect to WiFi network

|Fast Blinking (2 Hz)|Off|Off|Successful WiFi connection, trying to connect to wiThrottle server and acquire locos

|Off|Off|On|Regular operation, forward direction

|Off|On|Off|Regular operation, reverse direction

|Off|Flashing|On|Emergency stop, forward direction. Also happens when switching direction with speed potentiometer not at zero

|Off|On|Flashing|Emergency stop, reverse direction. Also happens when switching direction with speed potentiometer not at zero

|Off|Off|Blinking|Battery low, regular operation, forward direction

|Off|Blinking|Off|Battery low, regular operation, reverse direction

|Off|Flashing|Blinking|Battery low, Emergency stop, forward direction

|Off|Blinking|Flashing|Battery low, Emergency stop, reverse direction

|Short flashes|Off|Off|Throttle in low-power mode

|Off|Off|Off|Battery empty or no battery inserted

|On|Off|Off|No connection to existing WiFi network. Created internal configuration WiFi network

|Flashing|Flashing|Off|At startup: ESTOP pressed, will reset to factory defaults after five seconds. Release key for normal startupfootnote:ESP32[Only available on versions from 0.6 onwards with an ESP32-S2 MCU]

|Flashing|Off|Flashing|At startup: SHIFT pressed, will open internal configuration WiFi network after five seconds. Release key for normal startupfootnote:ESP32[]

|Off|Flashing|Flashing|At startup: F0 pressed when connected to WiFi, will not connect to server but enable configuration mode after five seconds. Release key for normal startupfootnote:ESP32[]

|On|On|On|Configuration mode enabled while connected to existing WiFi network. All locos emergency stop to avoid runaways. Push SHIFT + ESTOP again to exit configuration mode

4+|To recover from an emergency stop, turn speed potentiometer to zero to re-gain control.

4+|Also see <<ledTableVoltage>> for interpreting the LED patterns when turning off all locos.
|===

[#ledTableVoltage]
[cols="1,1,1,3"]
.LED patterns and how they show battery voltage when turning off the wiFred
|===
|Red LED|Green LED (Left)|Green LED (Right)|Battery voltage

|Flashing|Off|Off|Below 3.7V

|On|Off|Off|Between 3.7V and 3.8V

|On|Flashing|Off|Between 3.8V and 3.9V

|On|On|Off|Between 3.9V and 4.0V

|On|On|Flashing|Above 4.0V
|===

[#throttleControls]
.Controls and features of the wiFred throttle
Throttle

<<throttleControls>> shows the controls of the wireless throttle. They consist of the following:

- Four loco selection switches (loco 1 on the left, loco 4 on the right, move towards speed potentiometer to enable)

- Speed potentiometer (Counter-clockwise endstop: Stop, clockwise endstop: Full speed)

- Direction switch - move right for forward movement, left for reverse movement

- Black function keys F0 to F8

- Yellow shift key to trigger F9-F16 and turn on flashlight function

- Red emergency stop key

- Two green direction indicator LEDs next to speed potentiometer

- Red status LED next to speed potentiometer

- Red charging indicator LED at lower end of device - lit while charging

- Green fully charged indicator LED at lower end of device - lit when fully charged as long as charger still connected

As soon as any of the loco selection switches is moved into the "enabled" position, the throttle will boot up and try to connect to a wireless network. When all four loco selection switches are "disabled", the throttle will disconnect from the wireless network after a grace period of five seconds. The device will then go into low power mode, in which the battery will last for more than a year.

If no connection to the network configured into the device can be established within 60 seconds, the throttle will create it's own wireless network named *wiFred-config* plus six hex digits taken from the MAC address of the throttle WiFi interface, for example *wiFred-config61FB7B*, to enable configuration as described in <<config>>.

Four different locos with long DCC addresses can be assigned to the four loco selection switches. Commands derived from the speed potentiometer, the direction switch and the function keys will be transmitted to all selected locos (near) simultaneously, with a certain translation table enabling some locos to go backwards when others go forwards and also limiting function keys to some of the four locos only - this is described in more detail in <<throttle_LocoConf>> and <<throttle_FunctionConf>>.

Pushing the red emergency stop key will cause the throttle to send an emergency stop signal to all four locos attached. After an emergency stop, turn the speed potentiometer to zero to re-enable control of the locos.

Pushing the red emergency stop key while holding down the shift key will place the device into configuration mode (as well as issueing an emergency stop to all attached locos). See <<config>> for more details on how to access the throttle to do the configuration.

Any change in the loco selection switches will cause the throttle to send an emergency stop command to all attached locos. This makes sure that any loco that is deselected will stop on the layout and avoids newly selected locos suddenly taking off at speed. The same is true for a change in the direction switch, to avoid high-speed reverse maneuvers. Turn the speed potentiometer to zero to re-enable control of the locos.

When the battery is low, the device will not re-activate before charging the batteries, but continue operating for approximately an hour if active. When the battery is empty, it will disconnect and enter low power mode. Expected runtime is around 20 hours of full time operations, more if the throttle is placed in low power mode when the locos are not running.

During startup and operation, the LEDs will show the patterns explained in <<ledTable>>. After turning off the wiFred, the LEDs will show the current battery voltage for a few seconds, as described in <<ledTableVoltage>>.

=== Charging the wiFred

The wiFred can be charged through the Micro-USB connector at the lower end of the device. Maximum charging current is approximately 400 mA and the device does not communicate with the USB host, so technically there is no guarantee that charging from a USB cable will work, but most chargers, computer ports or power banks do not check the current before powering up.

As long as the battery is being charged, the red charging indicator LED will be lit. When the battery is fully charged, the green charged indicator LED will be lit as long as the charger is still connected. Expected charging time is around five to six hours for a full charge.

Even while charging, the device can still be operated (particularly helpful with a power bank) but since the operating current will come out of the battery, the battery will never be fully charged.

If both charging status LEDs light up when a charging cable is connected, probably the internal connection to the battery is faulty.

[#config]
== Configuring the wiFred

Before using the device, it must be configured. At the very least, the General Configuration page <<#throttleConfMainPage>> has to be submitted once to be saved to non-volatile memory. If no valid configuration is detected at startup, the device will start with a default configuration with no locos enabled and no WiFi settings, so it won't be able to connect to any WiFi network.

IMPORTANT: After entering any kind of text (names, numbers...) into text fields, the corresponding "Save" button has to be pressed to submit the changes to the wiFred.

=== Entering configuration mode

NOTE:  The wiFred is designed to be configured in configuration mode. If the IP address or the name of the throttle during normal operation is known, the configuration pages can also be accessed by pointing a web browser to it at any time while it is connected. This is mostly untested and therefore not recommended while the throttle is running locos, as it may lead to a temporarily inconsistent configuration. At the very least, deactivating and re-activating a loco with the respective loco selection switch will be required for changed settings to take effect.

There are four ways to enter configuration mode:

. Power up the throttle/select a loco when the configured WiFi network is not in range (or when there is no valid configuration - the first startup of a new throttle will fall into this category)

. Power up the throttle/select a loco while holding down SHIFT for five secondsfootnote:ESP32[]

. Press SHIFT and ESTOP together when the throttle is connected

. Press F0 for five seconds while / after the device has connected to a WiFi networkfootnote:ESP32[]

In the first two cases, the throttle will create a wireless network named *wiFred-config* plus six hex digits taken from the MAC address of the throttle WiFi interface, for example *wiFred-config61FB7B* and announce its presence under the name *config.local* as well as creating a captive portal. Any WiFi device with a web browser can connect to that network and open a web browser to point to *http://192.168.4.1* or *http://config.local*.

NOTE: This has been tested with Mozilla Firefox and Opera on Linux with Avahi (a Zeroconf implementation), FOSS Browser on Android 9/10 and Safari on iOS 13/14.

In the third and fourth case, the throttle will only announce its presence under the name *config.local* using the Bonjour/Zeroconf-protocol. Any device on the same WiFi network with Bonjour/Zeroconf can use a web browser to access the configuration at *http://config.local*. See <<configurationComputer>> for an explanation what is required to have your device read Bonjour/Zeroconf announcements.

NOTE: This has been tested with Mozilla Firefox and Opera on Linux with Avahi (a Zeroconf implementation) and BonjourBrowser on Android 10.

<<throttleConfMainPage>> shows the first page you will see when you point a web browser at your wiFred throttle. It is divided into multiple sections explained in the following chapters.

[#throttleConfMainPage]
.Screenshot of wiFred main configuration page
wiFred main configuration page

=== General configuration

In the "General configuration" section there is only one configuration option: The throttle name. This is a free-form identification string of the throttle. It shows up in the wiThrottle window of JMRI as shown in <<withrottleScreenshot>> and can be used to identify the throttle during configuration.

NOTE: The wiFred also announces its presence on the WiFi network through Bonjour/Zeroconf using a sanitized version of the name, i.e. a throttle called "Heiko Prototype 2-2" will announce its presence as *heikoprototype22.local* when not in configuration mode.

=== WiFi configuration

The "WiFi configuration" section shows a list of configured WiFi networks. The wiFred will connect to any network in this list, choosing the strongest one if multiple configured networks are in range.

Existing entries can be removed by clicking on the "Remove SSID" button in the line of the network that shall be removed.

New entries can be added either by manually entering the SSID and PSKfootnote:PSK[Pre-Shared Key, often just called password] if required and clicking the "Manually add network" button or by clicking on the "Scan for networks" link which takes the user to the page shown in <<throttleConfWiFiPage>>.

[#throttleConfWiFiPage]
.Screenshot of wiFred "Scan for WiFi"-page
Scan for WiFi page

This page will take a few seconds to load, since the scan for networks has to be completed first. It shows all the networks found during the scan. Networks can be added to the list by clicking the "Add network" button, after entering the PSKfootnote:PSK[] in the field next to it.

NOTE: The wiFred does not support WPS and it won't accept multiple networks with the same SSID but different PSKs. More details regarding the network requirements can be found in <<serverSetup>>.

The new WiFi configuration will not be activated until the wiFred is restarted, either through a power-cycle or by clicking on the "Restart wiFred to enable new WiFi-settings" link on the configuration page.

=== Loco server configuration

Following the WiFi configuration, the section "Loco server configuration" allows configuring the wiThrottle server to which the wiFred shall connect. The default setting - automatically detect server - works well if there is only one wiThrottle server on the network. It will connect to any server announcing its presence on port 12090 through Zeroconf/Bonjour, the result of the Zeroconf/Bonjour-search will be shown here when the wiFred has automatically discovered a server.

[#throttle_LocoConf]
=== Loco configuration

Following the "Loco server configuration", there are four identical sections assigned to the four different locomotives which can be controlled with this throttle. Each section consists of the following settings:

DCC address:: Can be a short address between 1 and 127 (also used for consists) or a long address between 0 and 10239.

NOTE: Short addresses between 1 and 127 are not the same as long addresses between 1 and 127, and many DCC systems do not support all those addresses.footnote:[In particular, long addresses 0-127 are not supported on many systems, for example those based on loconet.] A DCC address that the DCC system does not support is silently ignored.

If this is set to -1, the corresponding loco is disabled.

Long address?:: Checkbox to change the behaviour of the DCC address input field described above.

Direction:: This has three options:

* Forward: Loco will travel forwards if wiFred is set to forwards and vice versa

* Reverse: Loco will travel backwards if wiFred is set to forwards and vice versa

* Don't change: Loco will continue to travel in the same direction it was set to when it was activated and switch direction when the wiFred switches direction

Function mapping:: Link to the function mapping subpage for the corresponding loco, as described in <<throttle_FunctionConf>>. Clicking this link will lose all information entered on the current page and take the web browser to a different subpage.

IMPORTANT: Reminder: Changes are saved using the "Save loco config" button which
may look different in different web browsers (firefox shown).

[#throttle_FunctionConf]
=== DCC function configuration

By default, if a function key is pressed, the throttle will send the appropriate commands to every loco under control. Under certain circumstances, this may not be desired - the obvious example being a loco in the middle of a multi-unit consist, which should not have lights or ditchlights. So this page - shown in <<throttleConfigFunctionPage>> - offers the option to chose between three different settings for every function on each of the four locomotives (one page per locomotive):

[#throttleConfigFunctionPage]
.Screenshot of wiFred function handling config page
wiFred function page

Throttle controlled:: When the first loco is enabled by moving the selection switch to the "selected" position, the current status of the function is queried and saved. When selecting the next loco, the function status is set to be the same. Afterwards, key presses are handed through to the loco. Whether the function will be momentaryfootnote:MOM[Momentary functions are only activated for as long as the function key is pressed - like a whistle or horn that sounds just as long as the key is pressed.] or lockingfootnote:TOG[Locking functions are toggled with every press of the function key - like pressing F0 once typically turns the headlight on, pressing F0 again turns it off.] will be determined by the server, in the case of JMRI by the roster entry.

Throttle controlled, force momentary:: Function key will be handed through to the loco as a momentaryfootnote:MOM[] function.

Throttle controlled, force locking:: As described for *Throttle controlled* but the function will be forced to be lockingfootnote:TOG[] regardless of the server settingsfootnote:[The JMRI setting "F2 always momentary" will override this.].

Throttle controlled if this is the only loco:: As described for *Throttle controlled, force locking* but the function key will only be toggling the function if no other loco is enabled. This allows for i.e. turning headlights and rearlights on and off on individual locos before assembling a consist.

Force function always on:: The function will be forced on when the loco is activated and kept on regardless of key pressesfootnote:[This will also turn momentary functions permanently on.].

Force function always off:: The function will be forced off when the loco is activated and kept off regardless of key presses.

Ignore function key:: No function commands will be sent to this loco.

IMPORTANT: Reminder: Changes are saved using the "Save function configuration" button which may look different in different web browsers (firefox shown).

=== wiFred status

The "wiFred status" section shows the current battery voltage, as
measured by the wiFred. This is updated on reloading the page, not
continuosly.

It also shows the current firmware version(s).

=== wiFred system

In the wiFred system section of the configuration page, various settings related to the hardware can be changed.

The first setting concerns wiFreds with an On-Off-On direction switch and determines what the center position will do. The options are:

Ignore:: Don't do anything special when the switch is in the center position - just continue as before, same direction, speed controlled by speed potentiometer. Reversing entirely will trigger an emergency stop.

Zero speed:: Keep the direction but send out zero speed to all locos. This setting is intended for locos with high momentum settings. Reversing quicker than within half a second will trigger an emergency stop, otherwise the locos will resume their old speed setting in the opposite direction.footnote:[This is compatible to the Fredi's "coasting" function]

Set F<n>:: Simulates a function key press when switching from forward to center position and a key release when switching from center position to reverse (and vice versa).footnote:[It is suggested to configure the function to momentary as described in <<throttle_FunctionConf>> for this to work as intended] This is intended for locos with either a brake function or ESU's Drive Hold on a function key. The speed commands sent to the loco will still be controlled by the speed potentiometer while the direction switch is in the center position. Reversing quicker than within half a second will trigger an emergency stop, otherwise the throttle will continue to send speed commands according to the speed potentiometer position.

The section concludes with two links:

- Reset wiFred to factory defaults - which leads to a confirmation page shown in <<throttleConfResetPage>> to reset all configuration data to factory defaults as on a new wiFred.

- Update wiFred firmware - which leads to a firmware update page shown in <<throttleConfUpdatePage>> to update the wiFred firmware of the ESP8266 / ESP32-S2. Find the .bin-file from the arduino build folder or from the <<github>>, click on "Browse", navigate to the .bin-file and finally initiate the update with a click on "Update Firmware" - which will take a while.

NOTE: It may be necessary to power down the wiFred entirely for a firmware update to restart properly.

NOTE: On a wiFred version from 0.6 onwards with an ESP32-S2 MCU, resetting to factory defaults can also be done by holding down the ESTOP key for five seconds at startup.

[#throttleConfResetPage]
.Screenshot of wiFred configuration reset page
wiFred configuration reset page

[#throttleConfUpdatePage]
.Screenshot of wiFred firmware update page
wiFred firmware update page

[#serverSetup]
== Options for server setup

=== Components required to get the wiFred running

[#withrottleScreenshot]
.Screenshot of wiThrottle screen showing one throttle connected
wiThrottle screen

<<runningTrains>> shows the connections between the devices required to run trains using the wiFred.

[#runningTrains]
.Overview of devices required to run trains with the wiFred
Devices required to run trains with a wiFred

The symbols in <<runningTrains>> symbolize the following parts:

. An IEEE 802.11b/g/n 2.4 GHz WiFi access point described in detail in <<serverWiFi>>

. A PC or laptop computer with Windows, Linux or MacOS to run the JMRI server described in detail in <<serverJMRI>>

. A way to connect the JMRI server to the model railroading layout described in detail in <<serverLayoutConn>>

. A device with a web browser connected to the same network as the wiFred to configure it - can be the same physical device as the one running the server, if it meets the requirements in <<configurationComputer>>

Multiple options for every step or combining these steps are described in the following sections.

NOTE: Basically, if a layout is set up to run trains with a smartphone running wiThrottle or EngineDriver, a wiFred should work with no changes to the layout configuration. If a layout is set up in a way that trains can be run from a JMRI screen throttle on a computer, only a WiFi connection to the JMRI computer needs to be added.

=== Out-of-the-box server-side options

A pretty much out-of-the-box solution for a Raspberry Pi is provided by <<rpiImage>>, which creates its own WiFi network, auto-detects multiple options to interface to a DCC layout and starts a wiThrottle server. It has been tested in the JMRI 4.16 and JMRI 4.20 versions to work with the wiFred, connecting to a Z21 black through both an RRCircuits LocoBuffer USB and a Digitrax PR3 via Loconet.

Although untested so far, adding a <<Digitrax>> to a Digitrax system or an <<MRC>> to an MRC system should allow the wiFred to run locos out-of-the-box as well.

[#windowsWiFi]
=== Step by step instructions for a Windows computer

This has been tested on a Windows 7 64Bit laptop computer with a 2.4GHz WiFi card inside the PC.

==== Installation

. Install https://www.nirsoft.net/utils/wifi_hotspot_starter.html[HostedNetworkStarter]

. Install https://www.dhcpserver.de/cms/download/[DHCP server] - download and extract all the files from the zip file to somewhere on your harddrive, for example C:\DHCPServer

. Install a JDK, version 8 and 11 have been tested. For example, https://adoptopenjdk.net/releases.html[Version OpenJDK 11 (LTS), JVM HotSpot]. Choose the 64bit version for most modern hardware, 32bit only if you are running a 32bit operating system. Easiest option: MSI file, download and install.

. Install https://www.jmri.org[JMRI] - versions tested to run with the wiFred include 4.14, 4.16, 4.18 and 4.20. Most recent production version recommended.

NOTE: Windows 10 provides a Hotspot feature that will work in place of HostedNetworkStarter and DHCP server, so you can jump right into installing JDK and JMRI.

==== Configuration

. Start HostedNetworkStarter from the start menu, enter a Network Name and Network Key, then hit the Start button. Note the "Hosted Network Connection Name" for the next step

. Start the DHCP server wizard from C:\DHCPServer\dhcpwiz.exe, select the network with the name that's the same as the "Hosted Network Connection Name" from the step before, hit "Next" a few times (deselecting all additional supported protocols), Write INI file, Start Service and Configure Firewall Exceptions

. Start JMRI using the DecoderPro icon on the desktop, setup your layout connection, test if you can run a loco with a JMRI throttle

. Within JMRI, start the WiThrottle Server from the Actions menu. If a firewall popup comes up, allow all.

. Within JMRI, edit the Preferences from the Edit menu, choose WiThrottle on the left pane, click the "Start automatically with application" checkbox. All the Allowed Controls can be disabled.

==== Running

. Start HostedNetworkStarter from the start menu, enter a Network Name and Network Key, then hit the Start button.

. Start JMRI using the DecoderPro icon on the desktop

[#serverWiFi]
=== WiFi access point requirements

The wiFred will work on basically any 2.4GHz IEEE802.11b or -g WiFi network that will accept new devices and provide them with an IPv4 address through a DHCP server. It supports open networks or WPA2 encryption, though not WPS.

It has successfully been tested with a FRITZ!Box, a random cable router, multiple public WiFi networks and several software hotspots including Linux hostapd both on a first generation Intel Atom netbook and a Raspberry Pi, the Windows 10 Hotspot and a Windows 7 software as described in <<windowsWiFi>>.

NOTE: Some WiFi access points and routers offer a feature called "Wireless Isolation" or similar that will forbid connected devices from connecting to each other. This feature should be disabled for wiFreds to find their server and to be configured.

[#serverJMRI]
=== JMRI server requirements

Any PC that can run at least Java 8 will be able to run the JMRI server. Even old 32Bit first generation netbook computers like the 2008 Eee-PC have more than enough computing power for that task. There are JMRI versions for Windows, Linux or MacOS available, so any of these operating systems should be fine.

[#serverLayoutConn]
=== Layout connection options

<<JMRI>> supports a multitude of different connections to the layout as described in <<jmrihardwaresupport>>. In general, if a JMRI installation can run a loco on the layout, it's a simple matter of connecting the JMRI computer to a WiFi access point (if not already connected) and starting the wiThrottle server from the Actions-menu inside DecoderPro.

The wiFred has been tested to work with a LocoBufferUSB or a Digitrax PR3 connected via Loconet to an Intellibox, a Z21 black, a DCS 51 Zephyr xtra or a Minibox 2 DIY DCC central station. It has also been used to run a loco on a SPROG programmer.

[#configurationComputer]
=== Computer or smartphone to configure wiFred

Webbrowser, Zeroconf. Avahi. Bonjour (iTunes?). MacOS out of the box?
iOS? Android?

For initial configuration of the wiFred, most of the devices mentioned above can be omitted. As shown in <<confWifred>>, only a WiFi capable device with a web browser is required.

[#confWifred]
.For initial configuration, the requirements are very small
Configuring wiFred

Tested with iOS 13 and iOS 14, Android 9 and 10 as well as Firefox on Linux, the initial configuration page is automatically loaded when the device is connected to the *wiFred-configXXXX*-network.

For regular configuration, once the wiFred has successfully connected to a WiFi network and put into configuration mode, Bonjour/Zeroconf/mDNS support is required to find the device announcing itself as http://config.local. This service is provided on Linux by a software package called avahi, should work out of the box on iOS and MacOS and can be installed on Windows with iTunes. For mobile operating systems, there are apps called Discovery for iOS and BonjourBrowser for Android which not only translate http://config.local to point to the configuration website of the one wiFred on the network that is in configuration mode but also browse all wiFreds currently announcing their presence. <<bonjourBrowser>> shows a screenshot of the Android version. Clicking on a device will open a browser to its configuration website.

NOTE:  The wiFred is designed to be configured in configuration mode. If the IP address or the name of the throttle during normal operation is known, the configuration pages can also be accessed by pointing a web browser to it at any time while it is connected. This is mostly untested and therefore not recommended while the throttle is running locos, as it may lead to a temporarily inconsistent configuration. At the very least, deactivating and re-activating a loco with the respective loco selection switch will be required for changed settings to take effect.

[#bonjourBrowser]
.User interface of BonjourBrowser, showing two wiFreds active on the network.
BonjourBrowser with two wiFreds

=== Support for configuration software

To support a specialized configuration software, the wiFred will send a UDP broadcast upon successfully connecting to a WiFi network and present its configuration at /api/getConfigXML.

For more information, contact mailto:wiFred@bornwnd.de[Detlef Born].

== Hardware description

=== From revision 0.6 onwards

The wiFred hardware is centered around an ESP32-S2-WROOM module that controls the LEDs and reads the switches, push buttons and speed potentiometer. It gets its power from a single cell LiPo battery through a 3.3V low drop linear voltage regulator that is activated directly from the loco selection switches combined through a set of diodes. An RC lowpass will delay turning off the wiFred by a couple of seconds.

Optionally, two white 5 mm-LEDs protruding from the top of the PCB can be installed to serve as a flashlight. They are driven by a constant-current source directly from the battery and enabled when pushing the yellow SHIFT key.

The ESP32-S2 also monitors the battery voltage, going into sleep mode when the battery voltage drops too low. This should drop power consumption to a reasonably safe value, even though not as low as it can go when all the loco selection switches are off. Charging the battery can be done through the integrated USB port with two LEDs showing the charging status.

The schematic is split into several pages and can be found in <<schematic06page1>> to <<schematic06page3>>. It has been created with kicad and is available on the <<github>> along with the PCB design.

[#schematic06page1]
.Master schematic sheet with battery connector, charging circuit and power supply
"Schematic

[#schematic06page2]
.Schematic sheet including ESP32-S2-WROOM for WiFi connection with bootloader enabling jumper and connection to programming cable
"Schematic

[#schematic06page3]
.Schematic sheet for user interface (Keys, switches, LEDs, poti and flashlight)
"Schematic

=== Writing the firmware to the ESP32-S2-WROOM

To place the ESP32-S2 into firmware flashing mode, a jumper has to be installed on the BOOT pins as shown in <<bootJumper06>> when the device is powered up. After entering boot mode, the ESP32-S2 will register as a USB CDC device when connected to a PC and can be programmed through it. Alternately, the serial port at the TXD/RXD pins can be used. The serial port needs to be at 3.3 V-levels like from an FTDI232-device run at 3.3 V.

[#bootJumper06]
.Display of boot jumper - left from 0.6 prototype, right from 0.62 rendering
Boot jumper for 0.6 wiFred

All files in the *software/esp-firmware*-subdirectory of the <<github>> need to be placed in a folder, then the main sketch *esp-firmware.ino* needs to be opened with the Arduino IDE. Settings for the Arduino IDE can be found inside the main file, programming the device should work using the *Upload*-button in the *Sketch*-menu. An alternate solution using a pre-compiled firmware and esptool.py may be documented in the future.

=== Hints for building revision 0.6

All the SMD parts and connectors in <<BOM06SMD>> are located on the bottom side, so they can easily be installed by an automated PCB assembly service. Gerber files and location files will be made available on the <<github>>. They are no smaller than 0805, though, so it should be possible for experienced electronics hobbyists to hand-solder them as well, although the USB-C-connector has a very small pitch.
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

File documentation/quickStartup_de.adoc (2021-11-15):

== Erste Inbetriebnahme

. Laden Sie das Gerät mit einem Micro-USB- oder USB-C-Ladegerät, bis die LADE-LED auf grün schaltet
. Gerät mit noch angeschlossenem Ladegerät einschalten (kalibriert Batteriespannungsmessung)
. Warten Sie, bis die rote LED oben aufhört zu blinken und leuchtet
. Verwenden Sie ein beliebiges WLAN-Gerät, um nach dem Netzwerk wiFred-configXXXX zu suchen und eine Verbindung herzustellen
. Herstellen einer Verbindung mit http://config.local und Konfigurieren des Geräts

Weitere Informationen finden Sie unter https://newHeiko.github.io/wiFred/documentation/docu_de.html.

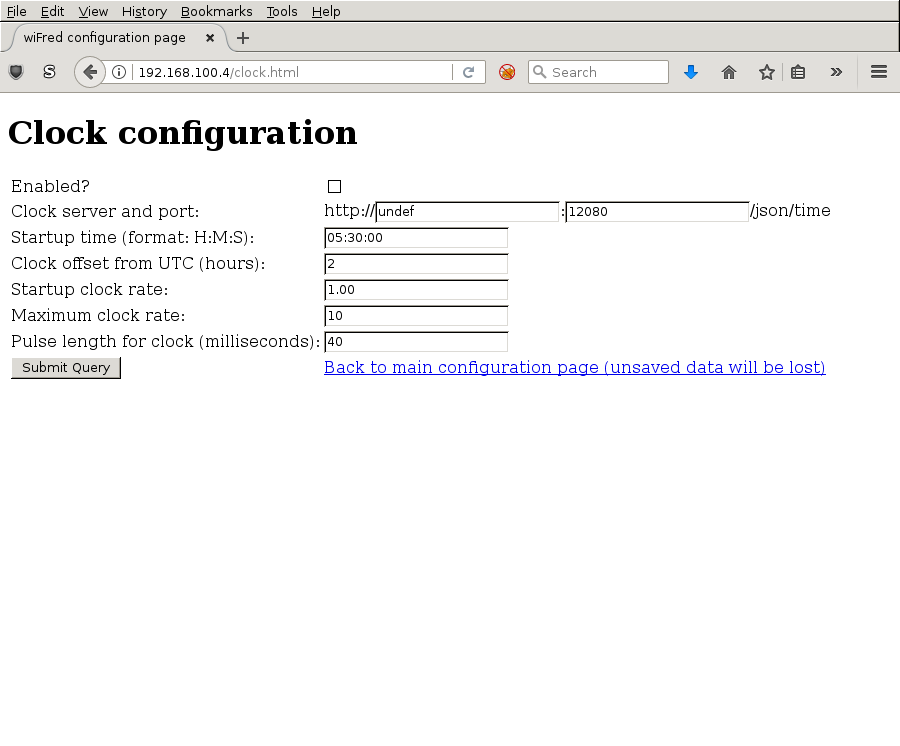
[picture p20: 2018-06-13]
documentation/images/screenShot_clock.png

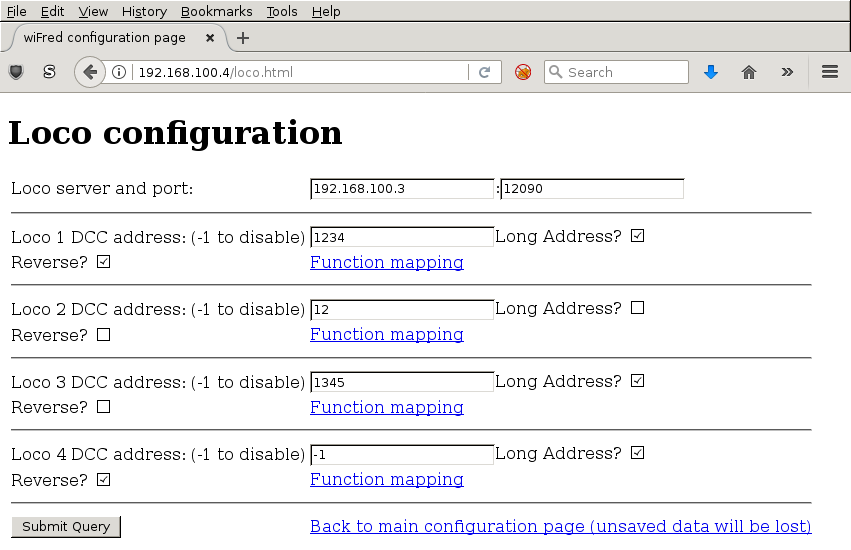
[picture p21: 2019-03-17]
documentation/images/screenShot_loco.png

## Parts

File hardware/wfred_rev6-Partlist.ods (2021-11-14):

Designator | Package | Quantity | Designation | Supplier | ID | Price | Total
P1 | PCB | 1 | 124mm x 35mm x 1.6mm | JLCPCB | PCB-SMT Service | 4.000 | 4.00
SW305 | SW_SPST_PTS645 | 1 | F0 | Mouser | 113-DTS65KV | 0.228 | 0.23
SW306 | SW_SPST_PTS645 | 1 | F1 | Mouser | 113-DTS65KV | 0.228 | 0.23
SW307 | SW_SPST_PTS645 | 1 | F2 | Mouser | 113-DTS65KV | 0.228 | 0.23
SW308 | SW_SPST_PTS645 | 1 | F3 | Mouser | 113-DTS65KV | 0.228 | 0.23
SW309 | SW_SPST_PTS645 | 1 | F4 | Mouser | 113-DTS65KV | 0.228 | 0.23
SW310 | SW_SPST_PTS645 | 1 | F5 | Mouser | 113-DTS65KV | 0.228 | 0.23
SW311 | SW_SPST_PTS645 | 1 | F6 | Mouser | 113-DTS65KV | 0.228 | 0.23
SW312 | SW_SPST_PTS645 | 1 | F7 | Mouser | 113-DTS65KV | 0.228 | 0.23
SW314 | SW_SPST_PTS645 | 1 | F8 | Mouser | 113-DTS65KV | 0.228 | 0.23
SW315 | SW_SPST_PTS645 | 1 | ESTOP | Mouser | 113-DTS65RV | 0.302 | 0.30
SW316 | SW_SPST_PTS645 | 1 | SHIFT | Mouser | 113-DTS65YV | 0.302 | 0.30
U301 | ESP32-S2-WROOM | 1 |  | Mouser | 356-ESP32S2WRM320PS3 | 2.118 | 2.12 | alternativ TME | ESP32S2-WROOM-32
SW301 | OS102011MS2Q | 1 | LOCO1 | Mouser | 611-OS102011MS2QN1 | 0.346 | 0.35 | alternativ TME | OS102011MS2QN1
SW302 | OS102011MS2Q | 1 | LOCO2 | Mouser | 611-OS102011MS2QN1 | 0.346 | 0.35 | alternativ TME | OS102011MS2QN1
SW303 | OS102011MS2Q | 1 | LOCO3 | Mouser | 611-OS102011MS2QN1 | 0.346 | 0.35 | alternativ TME | OS102011MS2QN1
SW304 | OS102011MS2Q | 1 | LOCO4 | Mouser | 611-OS102011MS2QN1 | 0.346 | 0.35 | alternativ TME | OS102011MS2QN1
SW313 | 100SP1T1B1M1QEH | 1 | DIRECTION | Mouser | 612-100-A1111 | 1.868 | 1.87
D303,D302,D301,D101,D102 | LED Spacer | 5 | 3mm | Mouser | 749-ELM-7-3MM | 0.045 | 0.23
RV301 | P160KNPD | 1 | 10k lin P160KNPD-4FC20B10K | Mouser | 858-P160KNP4FC20B10K | 0.706 | 0.71
H1 | Housing | 1 |  | Oliver |  | 6.000 | 6.00
J1 | Jumper | 1 | Jumper 2,54mm | Reichelt | JUMPER 2,54 SW | 0.030 | 0.03
K1 | Potentiometer Knob silver | 1 | 24mm | Reichelt | KNOPF 24-6 AL | 2.600 | 2.60
D101 | LED_D3.0mm | 1 | FORWARD - green | Reichelt | LED 3MM GN | 0.120 | 0.12
D205 | LED_D3.0mm | 1 | LED - green | Reichelt | LED 3MM GN | 0.120 | 0.12
D206 | LED_D3.0mm | 1 | REVERSE - green | Reichelt | LED 3MM GN | 0.120 | 0.12
D102 | LED_D3.0mm | 1 | LED - red | Reichelt | LED 3MM RT | 0.130 | 0.13
D207 | LED_D3.0mm | 1 | STOP - red | Reichelt | LED 3MM RT | 0.130 | 0.13
D304 | LED_D5.0mm_Horicontal_FLIPPED_O1.27mm | 1 | LED | Reichelt | LED EL 5-22500KW | 0.220 | 0.22
D305 | LED_D5.0mm_Horicontal_O1.27mm | 1 | LED | Reichelt | LED EL 5-22500KW | 0.220 | 0.22
S1,S2,S3,S4 | Mounting Screws | 4 | 2,9mm x 6,5mm | Reichelt | SBL 29065-100 | 0.020 | 0.08
B1 | Battery | 1 | Lithium battery 1700mAh | TME | ACCU-LP103058/CL | 8.639 | 8.64
 | Summe |  |  |  |  |  | 31.41

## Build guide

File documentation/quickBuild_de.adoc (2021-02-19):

// tag::drilljig[]
== Finish assembly (blank enclosure)
// end::drilljig[]
// tag::laser[]
== Finish assembly (laser engraved enclosure)
// end::laser[]

// tag::drilljig[]
. Use drilling jig to drill holes into housing
// end::drilljig[]
. Make cutout for micro USB connector
// tag::drilljig[]
. Use PCB to drill holes for LEDs next to micro USB connector (D101, D102)
// end::drilljig[]
. Install LEDs - long pin (positive) into square pad
  - Red LEDs at D101 and D205/D301 with 3mm spacers
  - Green LEDs at D102, D206/D302 and D207/D303 with 3mm spacers
  - White LEDs at D208/D304 and D209/D305 - choose where and how long they should stick out of housing
. Install potentiometer and loco selection switches
. Install direction selection switch and connect pins to PCB with short wires or cutoffs from LEDs
// tag::drilljig[]
. Make cut-outs in housing fit slide switches and flashlight LEDs
// end::drilljig[]
// tag::laser[]
. Drill holes in enclosure - 3mm for LEDs, 3.5mm for push buttons, 6.5mm for direction switch, 8mm for potentiometer, 1.5mm for slide switches and carefully file slide switch slots to match switch handles
// end::laser[]
. If push button switches are not installed: Place them on PCB (red at SW204, yellow at SW215) screw PCB into housing so they fit into the holes and solder them to the PCB
. Connect battery to P101 - BATT-connector
. Arrange battery so it fits between direction selection switch and PCB screws and glue into back housing

WARNING: Make sure red wire is connected to + and black wire connected to GND. Reversing the connection may destroy the wiFred.

WARNING: Make sure nothing pinches the battery. LiIon batteries are susceptible to mechanical damage.

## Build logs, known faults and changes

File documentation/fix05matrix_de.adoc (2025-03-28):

= Notwendige Reparaturarbeiten an wiFreds der Revisionen 0.5 und 0.51
Heiko Rosemann
0.1, 3-28-2025: Erste Ausgabe
:description: Fehlerbeseitigung an der LED-Tasten-Matrix um mehrfache Funktionsauslösungen zu verhindern
:url-repo: https://github.com/newHeiko/wiFred
:icons: image
:iconsdir: images/icons/
:imagesdir: images/
:lang: de
:toc:

// tag::largefile[]

Intensive Nutzung der wiFreds der Revisionen 0.5 und 0.51 brachte einen Fehler in der Tastatur- und LED-Matrix ans Licht. Mit Platinen der Revisionen 0.5 und 0.51 kann es in bestimmten Situationen dazu kommen, dass die Betätigung einer Funktionstaste vom wiFred als mehrere Funktionstasten interpretiert wird. Besonders auffällig ist dies, wenn F2, F5 oder F8 auch den Nothalt aktivieren. Dieses Dokument beschreibt eine Reparatur, die an vielen wiFreds erfolgreich angewendet wurde und auch in Schaltplan und Platine der Revision 0.52 eingeflossen ist. Die LEDs werden hierbei aus der Tastatur-Matrix herausgenommen und an andere Pins des AVR angeschlossen.

== Erforderliche Werkzeuge und Bauelemente

Diese Reparatur braucht etwas Entlötlitze, insgesamt drei bedrahtete 220-Ohm-Widerstände der Größe 0207 (die üblichen 0,25W-Kohleschicht oder 0,6W-Metallschicht-Widerstände passen) und etwas Schrumpfschlauch mit ca. 2,4mm Durchmesser.

Um im Anschluss die Firmware zu aktualisieren, ist zudem ein AVR-ISP-Programmierer für den typischen ISP-Anschluss an P201 auf der Platine nötig.

== Schrittweise Anleitung zur Reparatur

Als erstes die SMD-Widerstände R302, R303 und R304 entfernen und ihre Pads von Lötzinn befreien, wie in <<fix05matrix-001>> und <<fix05matrix-002>> gezeigt.

[#fix05matrix-001]
.Platine rev0.51 - die Hälfte, die die zu entfernenden SMD-Widerstände R302, R303 und R304 enthält
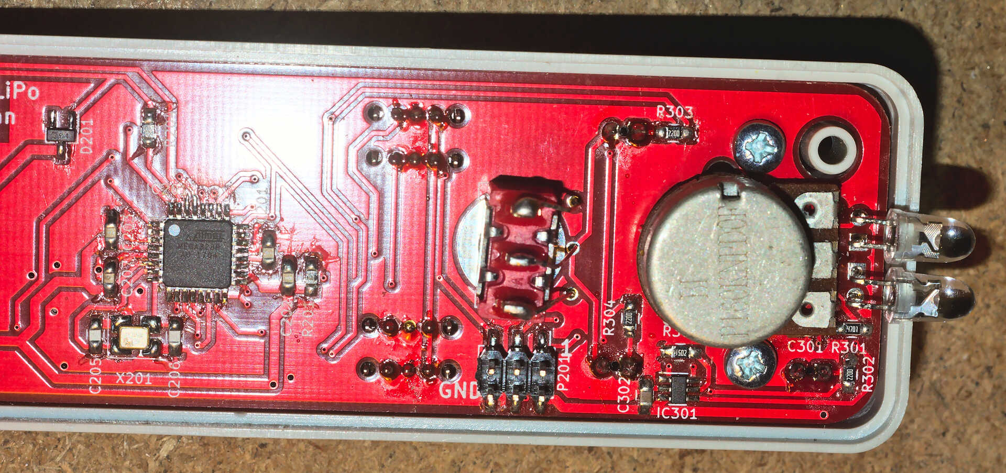
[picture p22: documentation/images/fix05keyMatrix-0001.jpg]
Platine wie ursprünglich entwickelt


[#fix05matrix-002]
.Platine rev0.51 nach der Entfernung von R302, R303 und R304
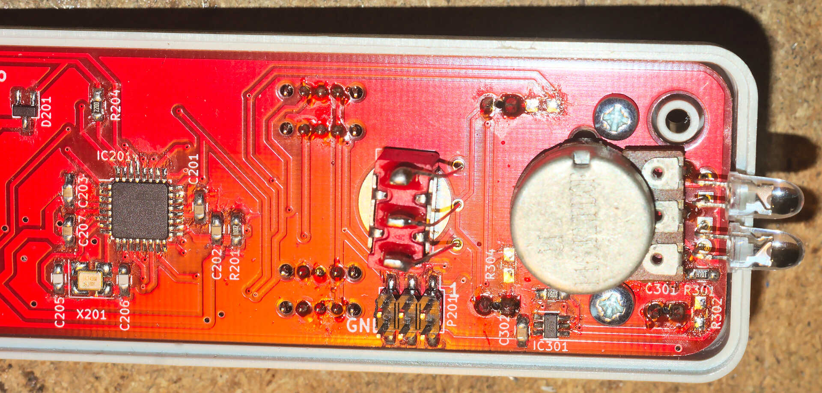
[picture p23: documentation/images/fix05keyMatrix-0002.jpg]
Platine ohne R302, R303 und R304


Anschließend den ersten der bedrahteten 220-Ohm-Widerstände (Größe 0207) so kurz ablängen und biegen, dass er Pin 1 von P201 zum äußeren Pad des ehemaligen R304 verbindet, und ihn so einlöten wie in <<fix05keymatrix-003>> gezeigt.

[#fix05keymatrix-003]
.Platine rev0.51 mit dem ersten Austausch-Widerstand
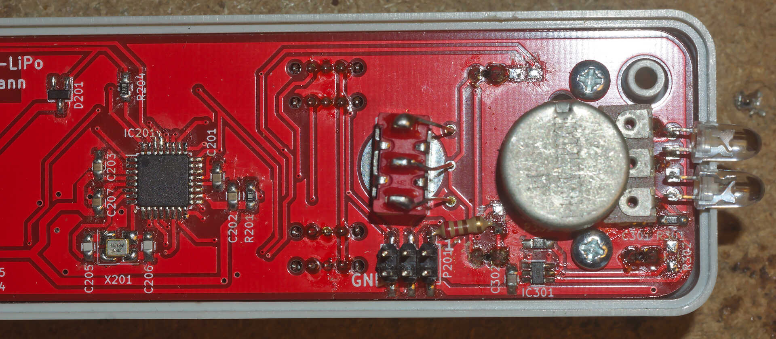
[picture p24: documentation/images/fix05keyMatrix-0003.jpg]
Platine mit dem ersten der drei Austausch-Widerstände


Die Anschlussdrähte des zweiten bedrahteten 220-Ohm-Widerstands müssen ein wenig komplexer geformt werden. Er soll Pin 3 von P201 (den mittleren in er oberen Reihe) verbinden mit dem inneren (linken) Pad von ehemals R303, wie <<fix05keymatrix-004>> zeigt. Da der längere Anschlussdraht dieses Widerstands nahe an verschiedenen Metallteilen im Inneren des wiFred verbeiläuft, empfiehlt sich eine Abdeckung mit einem passenden Stück Schrumpfschlauch, wie <<fix05keymatrix-005>> zeigt. Der Schrumpfschlauch muss dazu nicht geschrumpft werden, da er vom Widerstand und der Lötstelle in Position gehalten wird.

[#fix05keymatrix-004]
.Platine rev0.51 mit dem zweiten Austausch-Widerstand probehalber aufgelegt, aber noch nicht gelötet
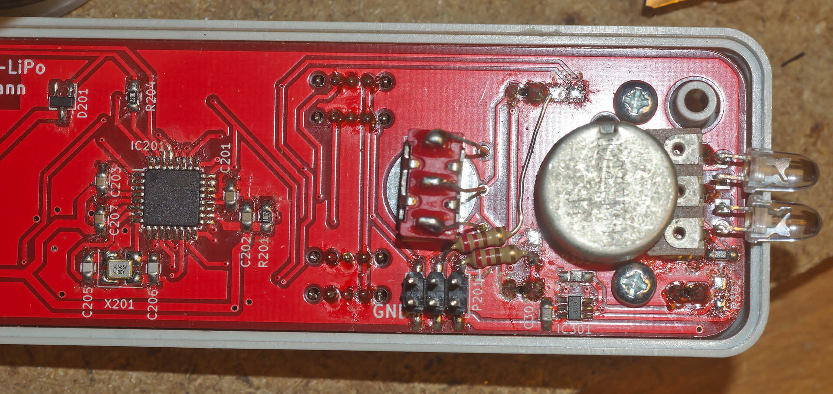
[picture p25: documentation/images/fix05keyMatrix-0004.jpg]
Anpassung des zweiten Austausch-Widerstands


[#fix05keymatrix-005]
.Platine rev0.51 mit dem zweiten Austausch-Widerstand eingelötet nach dem Aufschieben eines Stücks Schrumpfschlauch auf den blanken, oberen Anschlussdraht
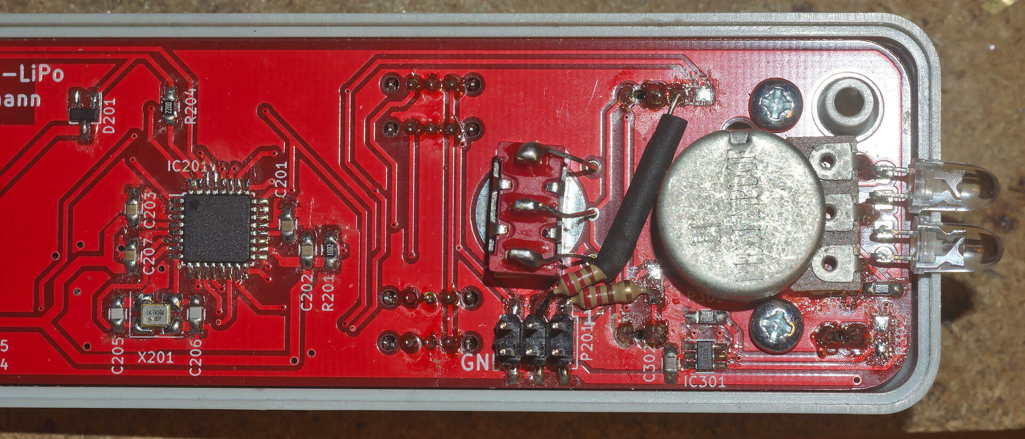
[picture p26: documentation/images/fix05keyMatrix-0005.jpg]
Zweiter Austausch-Widerstand mit einem Stück Schrumpfschlauch eingelötet


Der dritte bedrahtete 220-Ohm-Widerstand wird ähnlich installiert wie der zweite. Er wird ebenfalls an Pin 3 von P201 angelötet, aber dann an das obere (innere) Pad von ehemals R302 wie <<fix05keymatrix-006>> zeigt. Auch dieser Widerstand hat einen langen, blanken Anschlussdraht, der zwischen anderen Metallteilen im wiFred schwebt, so dass auch hier eine Isolierung mit einem Stück Schrumpfschlauch zu empfehlen ist. Ferner blockiert dieser Widerstand die untere rechte Platinenbefestigungsschraube, so dass der Anschluss entweder etwas anders gebogen werden sollte als im Bild oder die Schraube entfernt oder sichergestellt sein sollte, dass die Platine auf absehbare Zeit nicht aus dem Gehäuse entfernt werden muss.

[#fix05keymatrix-006]
.Platine rev0.51 mit allen drei Austausch-Widerständen
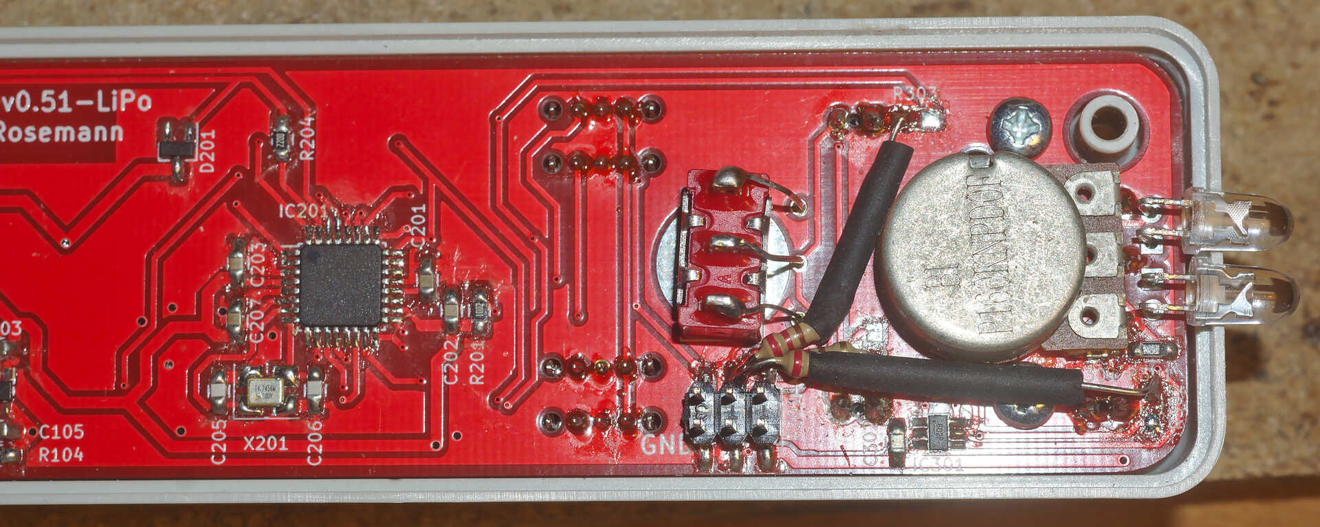
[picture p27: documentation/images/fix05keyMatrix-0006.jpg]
Alle drei Austausch-Widerstände installiert


== Erforderliche Software

Damit die LEDs an ihren neuen Anschlüssen leuchten, ist eine neue Firmware nötig. Sie ist über das Github-Repository verfügbar und hat das Datum 2025-03-26.

Vor dem Update der AVR-Firmware wird empfohlen, die ESP12-Firmware über das Webinterface zu aktualisieren. Zum Zeitpunkt der Erstellung dieser Zeilen sollte jede Firmware mit -esp12.bin im Dateinamen funktionieren, beginnend mit 2022-10-16-ff2c954-esp12.bin.

// end::largefile[]

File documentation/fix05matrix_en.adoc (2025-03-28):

= Required PCB fixes for wiFred revisions 0.5 and 0.51
Heiko Rosemann
0.1, 3-28-2025: Initial writeup
:description: Fixing key-matrix-LED errors to get rid of multiple function activations
:url-repo: https://github.com/newHeiko/wiFred
:icons: image
:iconsdir: images/icons/
:imagesdir: images/
:toc:

// tag::largefile[]

Intensive use of the wiFred of revisions 0.5 and 0.51 revealed a mistake in the way the LEDs and key switches are connected to the AVR on PCBs with rev0.5 and rev0.51: In certain situations, pressing one function key will be read as multiple key presses. This is most obvious with F2, F5 or F8 also activating ESTOP. This document describes a fix which has been implemented successfully in many wiFreds and also incorporated into the rev0.52 PCB and schematic. It removes the LEDs from the key read-in matrix.

== Tools and parts needed

This work requires some solder wick, a total of three 220-Ohm THT resistors of size 0207 (the usual 0.25W carbon film or 0.6W metal film types are fine) and some length of heat-shrink tube of about 2.4mm diameter.

To update the firmware, an AVR programmer for the regular AVR ISP connector P201 on the PCB is required.

== How to fix, step by step

First, remove the SMD resistors R302, R303 and R304 as shown in <<fix05matrix-001>> and <<fix05matrix-002>> and clean their pads with some solder wick.

[#fix05matrix-001]
.PCB rev0.51 showing the half with resistors R302, R303 and R304 to be removed
PCB as originally designed

[#fix05matrix-002]
.PCB rev0.51 after removal of R302, R303 and R304
PCB without R302, R303 and R304

Next, get the first of the 220-Ohm THT resistors (size 0207), cut and bend the leads very short so it connects Pin 1 of P201 to the outer pad of former R304 and solder it as shown in <<fix05keymatrix-003>>.

[#fix05keymatrix-003]
.PCB rev0.51 with the first of three replacement resistors installed
PCB with first of three replacement resistors

The second 220-Ohm THT resistors needs a little more shaping of its leads. It should connect pin 3 of P201 (center pin in the upper row) with the inner, left pad of former R303, as shown in <<fix05keymatrix-004>>. As the longer lead of that resistor passes close to a couple of metal pieces in the wiFred, it is recommended to cut a piece of heat-shrink tube and fit it over the bare metal of the lead, as shown in <<fix05keymatrix-005>>. It is not required to actually shrink it as it will be held in place by the resistor and the solder point.

[#fix05keymatrix-004]
.PCB rev0.51 with the second of three replacement resistors test-fit, but not yet soldered
Test fitting the second of three replacement resistors

[#fix05keymatrix-005]
.PCB rev0.51 with the second of three replacement resistors soldered after covering the bare lead with heat-shrink tube
Installed the second of three replacement resistors with heat-shrink tube

The final 220-Ohm THT resistor is installed in a similar fashion to the second one, also attaching to pin 3 of P201 and connecting it to the center (upper) pad of former R302 as shown in <<fix05keymatrix-006>>. It also has a long bare lead floating close to other metal parts, so insulation with heat-shrink tube is recommended. Also it blocks access to the lower right (in the picture) screw attaching the PCB to the housing, so either bend it a little different from the picture, remove the screw or make sure access to the top side of the PCB is not required.

[#fix05keymatrix-006]
.PCB rev0.51 with all three replacement resistors installed
All three replacement resistors installed

== Software required

To make the LEDs light up with their new connections, a new AVR firmware is required. It is distributed through the github repository and dated 2025-03-26.

Before updating the AVR firmware, it is recommended to update the ESP12 firmware through the web interface of the wiFred. As of this writing, any firmware with -esp12.bin in the filename should work, starting from 2022-10-16-ff2c954-esp12.bin.

// end::largefile[]

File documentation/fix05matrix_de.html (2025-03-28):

# Notwendige Reparaturarbeiten an wiFreds der Revisionen 0.5 und 0.51

Heiko Rosemann
version 0.1, 3-28-2025
Erste Ausgabe

Table of Contents

- Erforderliche Werkzeuge und Bauelemente
- Schrittweise Anleitung zur Reparatur
- Erforderliche Software

Intensive Nutzung der wiFreds der Revisionen 0.5 und 0.51 brachte einen Fehler in der Tastatur- und LED-Matrix ans Licht. Mit Platinen der Revisionen 0.5 und 0.51 kann es in bestimmten Situationen dazu kommen, dass die Betätigung einer Funktionstaste vom wiFred als mehrere Funktionstasten interpretiert wird. Besonders auffällig ist dies, wenn F2, F5 oder F8 auch den Nothalt aktivieren. Dieses Dokument beschreibt eine Reparatur, die an vielen wiFreds erfolgreich angewendet wurde und auch in Schaltplan und Platine der Revision 0.52 eingeflossen ist. Die LEDs werden hierbei aus der Tastatur-Matrix herausgenommen und an andere Pins des AVR angeschlossen.

## Erforderliche Werkzeuge und Bauelemente

Diese Reparatur braucht etwas Entlötlitze, insgesamt drei bedrahtete 220-Ohm-Widerstände der Größe 0207 (die üblichen 0,25W-Kohleschicht oder 0,6W-Metallschicht-Widerstände passen) und etwas Schrumpfschlauch mit ca. 2,4mm Durchmesser.

Um im Anschluss die Firmware zu aktualisieren, ist zudem ein AVR-ISP-Programmierer für den typischen ISP-Anschluss an P201 auf der Platine nötig.

## Schrittweise Anleitung zur Reparatur

Als erstes die SMD-Widerstände R302, R303 und R304 entfernen und ihre Pads von Lötzinn befreien, wie in Platine rev0.51 - die Hälfte, die die zu entfernenden SMD-Widerstände R302, R303 und R304 enthält und Platine rev0.51 nach der Entfernung von R302, R303 und R304 gezeigt.

Platine wie ursprünglich entwickelt

Figure 1. Platine rev0.51 - die Hälfte, die die zu entfernenden SMD-Widerstände R302, R303 und R304 enthält

Platine ohne R302, R303 und R304

Figure 2. Platine rev0.51 nach der Entfernung von R302, R303 und R304

Anschließend den ersten der bedrahteten 220-Ohm-Widerstände (Größe 0207) so kurz ablängen und biegen, dass er Pin 1 von P201 zum äußeren Pad des ehemaligen R304 verbindet, und ihn so einlöten wie in Platine rev0.51 mit dem ersten Austausch-Widerstand gezeigt.

Platine mit dem ersten der drei Austausch-Widerstände

Figure 3. Platine rev0.51 mit dem ersten Austausch-Widerstand

Die Anschlussdrähte des zweiten bedrahteten 220-Ohm-Widerstands müssen ein wenig komplexer geformt werden. Er soll Pin 3 von P201 (den mittleren in er oberen Reihe) verbinden mit dem inneren (linken) Pad von ehemals R303, wie Platine rev0.51 mit dem zweiten Austausch-Widerstand probehalber aufgelegt, aber noch nicht gelötet zeigt. Da der längere Anschlussdraht dieses Widerstands nahe an verschiedenen Metallteilen im Inneren des wiFred verbeiläuft, empfiehlt sich eine Abdeckung mit einem passenden Stück Schrumpfschlauch, wie Platine rev0.51 mit dem zweiten Austausch-Widerstand eingelötet nach dem Aufschieben eines Stücks Schrumpfschlauch auf den blanken, oberen Anschlussdraht zeigt. Der Schrumpfschlauch muss dazu nicht geschrumpft werden, da er vom Widerstand und der Lötstelle in Position gehalten wird.

Anpassung des zweiten Austausch-Widerstands

Figure 4. Platine rev0.51 mit dem zweiten Austausch-Widerstand probehalber aufgelegt, aber noch nicht gelötet

Zweiter Austausch-Widerstand mit einem Stück Schrumpfschlauch eingelötet

Figure 5. Platine rev0.51 mit dem zweiten Austausch-Widerstand eingelötet nach dem Aufschieben eines Stücks Schrumpfschlauch auf den blanken, oberen Anschlussdraht

Der dritte bedrahtete 220-Ohm-Widerstand wird ähnlich installiert wie der zweite. Er wird ebenfalls an Pin 3 von P201 angelötet, aber dann an das obere (innere) Pad von ehemals R302 wie Platine rev0.51 mit allen drei Austausch-Widerständen zeigt. Auch dieser Widerstand hat einen langen, blanken Anschlussdraht, der zwischen anderen Metallteilen im wiFred schwebt, so dass auch hier eine Isolierung mit einem Stück Schrumpfschlauch zu empfehlen ist. Ferner blockiert dieser Widerstand die untere rechte Platinenbefestigungsschraube, so dass der Anschluss entweder etwas anders gebogen werden sollte als im Bild oder die Schraube entfernt oder sichergestellt sein sollte, dass die Platine auf absehbare Zeit nicht aus dem Gehäuse entfernt werden muss.

Alle drei Austausch-Widerstände installiert

Figure 6. Platine rev0.51 mit allen drei Austausch-Widerständen

## Erforderliche Software

Damit die LEDs an ihren neuen Anschlüssen leuchten, ist eine neue Firmware nötig. Sie ist über das Github-Repository verfügbar und hat das Datum 2025-03-26.

Vor dem Update der AVR-Firmware wird empfohlen, die ESP12-Firmware über das Webinterface zu aktualisieren. Zum Zeitpunkt der Erstellung dieser Zeilen sollte jede Firmware mit -esp12.bin im Dateinamen funktionieren, beginnend mit 2022-10-16-ff2c954-esp12.bin.

Version 0.1
Last updated 2025-03-28 20:43:19 +0100

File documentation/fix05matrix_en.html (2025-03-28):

# Required PCB fixes for wiFred revisions 0.5 and 0.51

Heiko Rosemann
version 0.1, 3-28-2025
Initial writeup

Table of Contents

- Tools and parts needed
- How to fix, step by step
- Software required

Intensive use of the wiFred of revisions 0.5 and 0.51 revealed a mistake in the way the LEDs and key switches are connected to the AVR on PCBs with rev0.5 and rev0.51: In certain situations, pressing one function key will be read as multiple key presses. This is most obvious with F2, F5 or F8 also activating ESTOP. This document describes a fix which has been implemented successfully in many wiFreds and also incorporated into the rev0.52 PCB and schematic. It removes the LEDs from the key read-in matrix.

## Tools and parts needed

This work requires some solder wick, a total of three 220-Ohm THT resistors of size 0207 (the usual 0.25W carbon film or 0.6W metal film types are fine) and some length of heat-shrink tube of about 2.4mm diameter.

To update the firmware, an AVR programmer for the regular AVR ISP connector P201 on the PCB is required.

## How to fix, step by step

First, remove the SMD resistors R302, R303 and R304 as shown in PCB rev0.51 showing the half with resistors R302, R303 and R304 to be removed and PCB rev0.51 after removal of R302, R303 and R304 and clean their pads with some solder wick.

PCB as originally designed

Figure 1. PCB rev0.51 showing the half with resistors R302, R303 and R304 to be removed

PCB without R302, R303 and R304

Figure 2. PCB rev0.51 after removal of R302, R303 and R304

Next, get the first of the 220-Ohm THT resistors (size 0207), cut and bend the leads very short so it connects Pin 1 of P201 to the outer pad of former R304 and solder it as shown in PCB rev0.51 with the first of three replacement resistors installed.

PCB with first of three replacement resistors

Figure 3. PCB rev0.51 with the first of three replacement resistors installed

The second 220-Ohm THT resistors needs a little more shaping of its leads. It should connect pin 3 of P201 (center pin in the upper row) with the inner, left pad of former R303, as shown in PCB rev0.51 with the second of three replacement resistors test-fit, but not yet soldered. As the longer lead of that resistor passes close to a couple of metal pieces in the wiFred, it is recommended to cut a piece of heat-shrink tube and fit it over the bare metal of the lead, as shown in PCB rev0.51 with the second of three replacement resistors soldered after covering the bare lead with heat-shrink tube. It is not required to actually shrink it as it will be held in place by the resistor and the solder point.

Test fitting the second of three replacement resistors

Figure 4. PCB rev0.51 with the second of three replacement resistors test-fit, but not yet soldered

Installed the second of three replacement resistors with heat-shrink tube

Figure 5. PCB rev0.51 with the second of three replacement resistors soldered after covering the bare lead with heat-shrink tube

The final 220-Ohm THT resistor is installed in a similar fashion to the second one, also attaching to pin 3 of P201 and connecting it to the center (upper) pad of former R302 as shown in PCB rev0.51 with all three replacement resistors installed. It also has a long bare lead floating close to other metal parts, so insulation with heat-shrink tube is recommended. Also it blocks access to the lower right (in the picture) screw attaching the PCB to the housing, so either bend it a little different from the picture, remove the screw or make sure access to the top side of the PCB is not required.

All three replacement resistors installed

Figure 6. PCB rev0.51 with all three replacement resistors installed

## Software required

To make the LEDs light up with their new connections, a new AVR firmware is required. It is distributed through the github repository and dated 2025-03-26.

Before updating the AVR firmware, it is recommended to update the ESP12 firmware through the web interface of the wiFred. As of this writing, any firmware with -esp12.bin in the filename should work, starting from 2022-10-16-ff2c954-esp12.bin.

Version 0.1
Last updated 2025-03-28 20:00:15 +0100

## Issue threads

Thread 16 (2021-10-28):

Has anyone tested this on DCC++EX?

FrightRisk, 2021-10-28:
Any WiThrottle device should work, but since we don't broadcast our info to WiThrottle and expect WiThrottle to ask and get back our ID string, some throttles may need to account for that. Creating a DCC++EX Command Station from an Uno or Mega is easier than building a throttle, so I was hoping someone already tested or could make a CS with an Arduino and Motor Shield they may have already. It can be tested with just an Arduino, a WiFi shield or ESP-01S and a computer connected as a serial monitor since we can turn on wifi and Withrottle diagnostics and watch if commands are being sent back and forth. That way you don't have to have a motor shield and actually use it as a CS connected to a track.

newHeiko, 2021-11-06:
I haven't - but if you send me a DCC++EX sketch for a NodeMCU (with ESP12F) or an ESP32-S2-DevKit https://www.olimex.com/Products/IoT/ESP32-S2/ESP32-S2-DevKit-Lipo/open-source-hardware I'm happy to try it. I don't have any motor shield or anything, so please give detailed info how to test...

I did test it with an LNWI, which also does not broadcast its information and also expects wiThrottle to ask, and I made it work.

Heiko

newHeiko, 2022-10-16:
@FrightRisk A colleague of mine tested this with DCC++Ex and got it to work after a little shuffling around the initialization. So it should work since  #62290d501ff1ae78cc65b820608219e5dc9286e6

Feel free to re-open if it doesn't,
Heiko

Closed 2022-10-16.

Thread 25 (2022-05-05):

Anti-twist protection for toggle switch

MOppHub, 2022-05-05:
The direction toggle switch has a washer with a bent over edge. This can be used to fix the switch inside the PCB so it can not twist.
Therefore a new hole is needed next to the existing hole for the switch.

Closed 2022-10-09.

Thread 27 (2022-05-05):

Extended PCB silkscreen for LEDs

MOppHub, 2022-05-05:
Mark the color of the LED directly on the PCB for easier assembly.

Better footprint documentation to see the orientation of the LED in the silkscreen.

Closed 2022-10-09.

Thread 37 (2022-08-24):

Configure wiFred via USB port

newHeiko, 2022-08-24:
- Understand all key/value pairs already allowed via HTTP GET
- Add "list" option to output entire configuration (XML?)
- Mostly important to quickly connect wiFred to new/previously unknown WiFi network

newHeiko, 2022-08-24:
Only for 0.6+ PCBs with ESP32-S2.
Not an option for versions up to 0.51 with ESP12

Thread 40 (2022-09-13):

Esp32-S2 upgrade to esp32-s3

MOppHub, 2022-09-13:
The eps32-s2 modules are in the meantime NRND. So long term procurement could become difficult.
Maybe it's worth to do an upgrade to esp32-s3 modules, when the next PCB redesinge is necessary.

This would also enable to implement Bluetooth communication as alternative option in the future.

newHeiko, 2022-10-05:
With Espressif's longevity commitment https://www.espressif.com/en/products/longevity-commitment for the S2 reaching into 2031 and the S3 only a year longer, I hope there will be a different option when 2031 gets closer.

Closed 2022-10-05.

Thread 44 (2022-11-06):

Fix description of battery voltage calibration

newHeiko, 2022-11-06:

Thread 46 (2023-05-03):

Rotary Encoder support

steampunklolcat, 2023-05-03:
Would it be possible to implement support for a rotary encoder instead of a potentiometer?

The button could be used for fast switching to speedstep 0.

newHeiko, 2023-05-16:
I personally have no interest in a rotary encoder and a long TODO list ahead of it.

But I do know someone working on it. We'll see how it goes and if I can incorporate the code into this repo.

Heiko

pischky, 2023-05-28:
There is no need to support rotary encoders. That is my experience from FRED and FREDI project.

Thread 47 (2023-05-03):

Drilljig missing in 0.6

steampunklolcat, 2023-05-03:
The drilljig is missing from the 0.6 releases of the gerber-files.

newHeiko, 2023-05-16:
True, we started creating laser engraved housings somewhere around 0.5. But I'll have a look into creating the drilljig again.

Heiko

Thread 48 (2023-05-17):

wiFRED use with command stations equipped with the WiThrottle protocol

HonzaM44, 2023-05-17:
It seems not very practical to have to use computer with JMRI for connection to the Train command station. There might be several ways how to use the wiFRED operating on WiThrottle protocol, either using the Digitrax  LNWI unit to connect it to the LocoNet used to standard FREDs, or to use some command station equipped with the wifi and WiThrottle protocol, such as YaMoRC YC7100 or YC7100, TCS-2. Probably as well the ESU Smart Control.
It is only necessary that it would exist a way of easy wifi connection to the LNWI or command stations mentioned above.

danielb987, 2023-05-17:
Running JMRI on a Raspberry Pi is a good choice. There is a prebuilt image for RPi with JMRI here: https://mstevetodd.com/rpi

And instructions to install JMRI on RPi if you want to do it yourself:
https://www.jmri.org/install/Raspbian.shtml

HonzaM44, 2023-05-17:
I want to use the wiFRED  without the need of PC with installed JMRI - WiThrottle might be used on the train command station which “understand” to it! Same way can communicate mobile phones using WiThrottle Application (iOS) or Engine Driver (Android).

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

newHeiko, 2023-05-17:
Well, the wiFred is designed under the premise that you have a smartphone, a tablet or a notebook computer to _configure_ it (WiFi and loco addresses at the minimum). You don't need JMRI for that, just WiFi and a web browser.

But once you've done that, sure, you can use it with DCC++EX or an LNWI (unless I broke something since I last tested) or with the YaMoRC WiFi https://youtu.be/azPPXs0PULk?t=197 or the upcoming Uhlenbrock WiFi thingie or Intellibox neo.

I have no idea about the ESU Smart Control - does that even support wiThrottle? - or the TCS command station. If I can get my hands on one, I might test it.

biteater, 2023-05-22:
You can find the documentation in the directory 'documentation' of this wiFred Github repository or here:
https://newheiko.github.io/wiFred/documentation/docu_en.html#throttle

I suggest creating separate issues for the additional topics you mentioned, just to keep the discussion focused.

newHeiko, 2023-05-22:
Let's pick this apart:

- I'm not aware of any place or person selling ready-made wiFreds. I personally do not and I will not.
- You can either leave out three of the four slide switches when assembling the wiFred (you'll need to solder a jumper wire in then for the three not in use) or just configure only one address and ignore the other three switches, IMHO. Or maybe I don't understand your "only one address" concern correctly.
- Easy setting of the address is something I will not implement, as it's a very explicit Fremo rule to not allow that. Have a look at one of the many other projects like https://model-railroad-hobbyist.com/sites/model-railroad-hobbyist.com/files/esp32_sma30_pcnry_v1_0_0.pdf / https://forum.mrhmag.com/post/sma30-a-simplified-wifi-throttle-you-can-customize-12211948 or https://github.com/flash62au/WiTcontroller (by JMRI's / EngineDriver's very own Peter Akers) and see if one of those better suits your use needs.
- The wiFred will already fail to pick up an address that's in use by another throttle (if the wiThrottle server supports it as JMRI does - from 5.4 onwards also for wiFred<->wiFred). I do need to add some LED blink codes to let the user know, though (see #45 )
- The wiFred enables "heartbeat" timeout if the wiThrottle server offers it. As JMRI does. So after the heartbeat timeout, JMRI will stop the loco (I don't know how other wiThrottle-commpatible servers handle that) But when the connection is gone, there's nothing else the wiFred can do to stop the loco.

Heiko

HonzaM44, 2023-05-25:
Hi,

you wrote, that for setting of wiFRED can be, beside the notebook with JMRI, used as well a smartphone - what application should be used for this purpose and how to do it?

As regards four slide switches, their use is in fact against the FREMO rules, as in this case, user can choose any one of the four Locos - user alone should not be able to control more than one loco with its throttle.

Jan

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

newHeiko, 2023-05-25:
> you wrote, that for setting of wiFRED can be, beside the notebook with JMRI, used as well a smartphone - what application should be used for this purpose and how to do it?

You can use any web browser (Safari, FOSS browser, Chrome, Brave, Opera, Firefox, Chromium, Edge...). Connect your Smartphone or Tablet or Laptop to the wiFred-configXXXXXX network, wait for the captive portal to load, or - if it does not automatically - open it through the "Sign into network" button or just enter http://neverssl.com or any other non-https website into your browser.

> As regards four slide switches, their use is in fact against the FREMO rules, as in this case, user can choose any one of the four Locos - user alone should not be able to control more than one loco with its throttle.

I read the Fremo rules more like the user should not be allowed to choose any loco address, but if your group implements that in a different way, don't install slide switches 2-4. Or just don't configure loco addresses for them.

Heiko

HonzaM44, 2023-05-26:
Hi,
thanks for your answers and explanations. There is one more item I would like to be clarified. According to FREMO rules, it must not be possible to connect simultaneously two throttles having the same address. If there would be two (wired) FREDs programmed with the same address, than after one is already connected and active on the LocoNet bus, when you connect the other one, the address in this second one is automatically deleted, if somebody wants to use this FRED again, its address has to be newly programmed. I have been testing on our meeting the layout equipped with the LNiWI interface LocoNet/WiThrottle enabling communication with the wifi throttle ESU mobile control II. When some slot was already occupied by the connected wired FRED, then when I wanted to choose the same address on the ESU throttle, it was not possible and the throttle informed me on the display that it is impossible. ESU throttle obviously checks if the address (the slot) is free. wiFRED should function similar way - at least letting know the user that the address is occupied and respective train can not be controlled. I hope I explained what I mean.
Sorry for my bad English, I hope you understand what I mean.
Regards
Jan

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

newHeiko, 2023-05-26:
What the wiFred does when its address is already in use by another throttle depends entirely on how it's connected to Loconet / the DCC system.

JMRI will notify the wiFred if the address is already in use. The wiFred will not control the loco then (although it will not forget it's configuration, so the next time you turn it on, it will try again).

And I will implement some LED pattern to tell the user "that loco is busy". Soon. That's what #45 is about.

I don't know how the LNWI handles that case.

Heiko

pischky, 2023-05-28:
I do not really understand the request. Using a computer or mobile phone to setup wiFred to use a specific loco is part of the design and there is no need to provied another way. This is also a saftey feature required.
I vote to reject this request.

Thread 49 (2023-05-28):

Hidden SSID

pischky, 2023-05-28:
wiFred doesnot connect to a WLAN with hidden SSID.

Switching SSID to hidden is essiantial on exhibitions and meetings when to expect many mobile phones that are trying to connect to every WLAN they see.

I have tested with FW 2022-10-16 and Fritzbox 7590 and FRITZ!OS 07.29.

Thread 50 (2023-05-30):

register with throttle name in DNS

pischky, 2023-05-30:
wiFred registers in DNS (by DHCP) with somethings like "esp32s2-3D733E".
Instead the throttle name as entered should be used.

This would help calling the configuration page on systems without mDNS (e.g. Win7).

To test a Fritzbox (like 7590) can be used. The device shows as name "esp32s2-3D461A". Also
"nslookup esp32s2-3D461A" or "nslookup esp32s2-3D461A.fitz.box". But
"nslookup &lt;throttle name&gt;" should work.
On other APs without a DNS (like WRT54GL) this will not work.

I assume calling a setHostname() should help,

Firmware revision used: 2022-10-16-71ca8c3-master
AFAIK older versions of firmware showed the correct throttle name.

Closed 2023-11-14.

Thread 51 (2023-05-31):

Support of 28 Speed Steps

pischky, 2023-05-31:
wiThrottle should support DCC decoders with 28 speed steps.

There should be a selection after the DCC address with at least the options "128", "28" speed steps.
May be this could extended to all options available on a Loconet command station (14, 128 DAC, 28 DAC, SX, ...).

I assume that this requires an extension of the wiThrottle protocol, selection of speed steps in the wiThrottle server is much to complicated for the average user.

There are many (older) decoders (like Lenz LE103, LE040) that does not work with 128 speed steps but are still used. Also there are some decoders that support speed table only when used with 28 speed steps.

pischky, 2023-05-31:
> actually there is a command to set the speed step mode

I did not find this. Any Hint?

> I'll look into it, though I won't be able to test on anything else beside JMRI.

I will test it from throttle to loco. I have DCS100 and Loco with LE103 (or DCC Sniffer) for this.

newHeiko, 2023-05-31:
> Throttle Commands >> 's' set speed step mode.

:) I'd hope it's the same as these: https://www.jmri.org/help/en/package/jmri/jmrit/withrottle/Protocol.shtml#ThrottleChangeNotification

(though I don't know what 27 speed steps is)

pischky, 2023-05-31:
> though I don't know what 27 speed steps is

Older Dekoders from Lenz (LE075 or Roco 10741) supported only 14 and 27 speed steps. 27 was like 14, but the CU was sending two different speed steps alternating. [http://www.dcc-mueller.de/decoder/dectab_o.htm](http://www.dcc-mueller.de/decoder/dectab_o.htm)

pischky, 2023-06-01:
About guessing the values:

JMRI has a class (enum) jmri.SpeedStepMode. The ordinal values would be 0=UNKNOWN, 1=NMRA_DCC_128, 2=NMRA_DCC_28, 3=NMRA_DCC_27, 4=NMRA_DCC_14, 5=MOTOROLA_28, 6=TMCC_32, 7=INCREMENTAL.

That does not match what is documented in ThrottleChangeNotification.

https://www.jmri.org/JavaDoc/doc/src-html/jmri/SpeedStepMode.html
https://www.jmri.org/JavaDoc/doc/jmri/SpeedStepMode.html

May be a hint is the method decodeSpeedStepMode() in jmri.jmrit.withrottle.ThrottleController:
https://www.jmri.org/JavaDoc/doc/src-html/jmri/jmrit/withrottle/ThrottleController.html#line.734

So I would guess that possible values are

- "1",
- "2"
- "4"
- "8"
- "16"

and

- "unknown"
- "128"
- "28"
- "27"
- "14"
- "motorola_28"
- "tmcc_32"
- "incremental"

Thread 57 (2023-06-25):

configuration website should send favicon.ico an set title

pischky, 2023-06-25:
Wifred should send a favicon.ico on URL "/favicon.ico".
The title should include the throttle name.

This would improve the distinction of bookmarks set on the configuration page.

[https://de.wikipedia.org/wiki/Favicon](https://de.wikipedia.org/wiki/Favicon)

[https://wiki.selfhtml.org/wiki/Grafik/Favicon](https://wiki.selfhtml.org/wiki/Grafik/Favicon)

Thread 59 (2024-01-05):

JLCPCB extended parts and kits?

fodi666, 2024-01-05:
Hi,
I have just found this wonderful project. I have two questions, though:
Is there a version which would replace most of the extended selection parts from JLCPCB with ones from the standard selection? I found that roughly one third of the cost when ordering with top side assembly is related to additional labor costs related to extended parts.
Do you know of anyone selling (semi)assembled kits, like in a Tindie store or something? It would be nice if there were some kits where the SMD parts would be assembled and the rest would be at least packed up in a bag along with the PCB. I understand though, if that is something that you do not want to start.
Thanks and keep up the good work.

newHeiko, 2024-05-19:
Hi,

I tried to use JLC standard parts where I could, so I don't think there will be a different version with (many) more basic parts. I may have missed some, though - so let me know if you find any extended parts I used that can easily be replaced with basic parts.

I'm not planning to sell kits and I'm not aware of anyone who is doing so for the general public. However, I intentionally chose relatively open licenses so anyone who wants to sell kits can do so and there may well be someone I don't know of.

Please do not expect me to support them, though.

Sorry for being so late, I haven't been following the issues here too closely.

Heiko

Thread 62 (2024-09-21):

Current master does not build for arduino-esp32 3.x

newHeiko, 2024-09-21:
After updating my local boards, current master does not build. Will have to fix it.

newHeiko, 2024-09-21:
Fixed with clean install of arduino-esp32 version 3.0.5.

Closed 2024-09-21.

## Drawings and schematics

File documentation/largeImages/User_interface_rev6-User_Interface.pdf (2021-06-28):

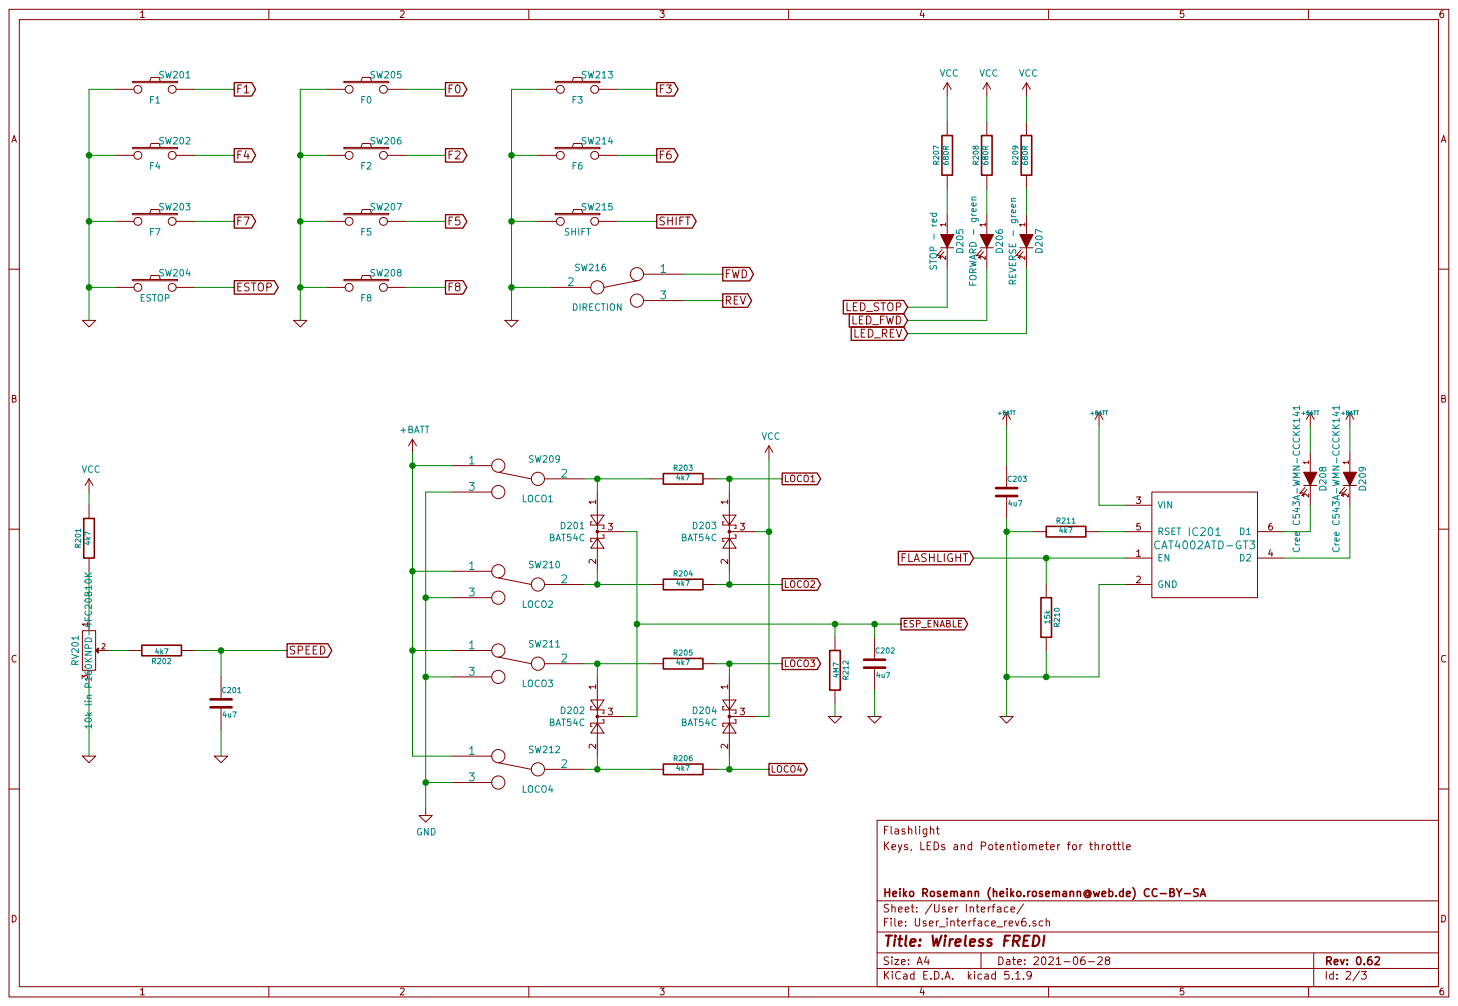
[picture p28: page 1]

1 2 D207 REVERSE - green 1 2 D206 FORWARD - green R209 680R R210 15k

1 2 D209 Cree C543A-WMN-CCCKK141 1 2 D208 Cree C543A-WMN-CCCKK141 EN 1 GND 2 VIN 3 D2 4 RSET 5 D1 6

Flashlight
Keys, LEDs and Potentiometer for throttle

File: User_interface_rev6.sch Sheet: /User Interface/ Heiko Rosemann (heiko.rosemann@web.de) CC-BY-SA

Id: 2/3 Title: Wireless FREDI

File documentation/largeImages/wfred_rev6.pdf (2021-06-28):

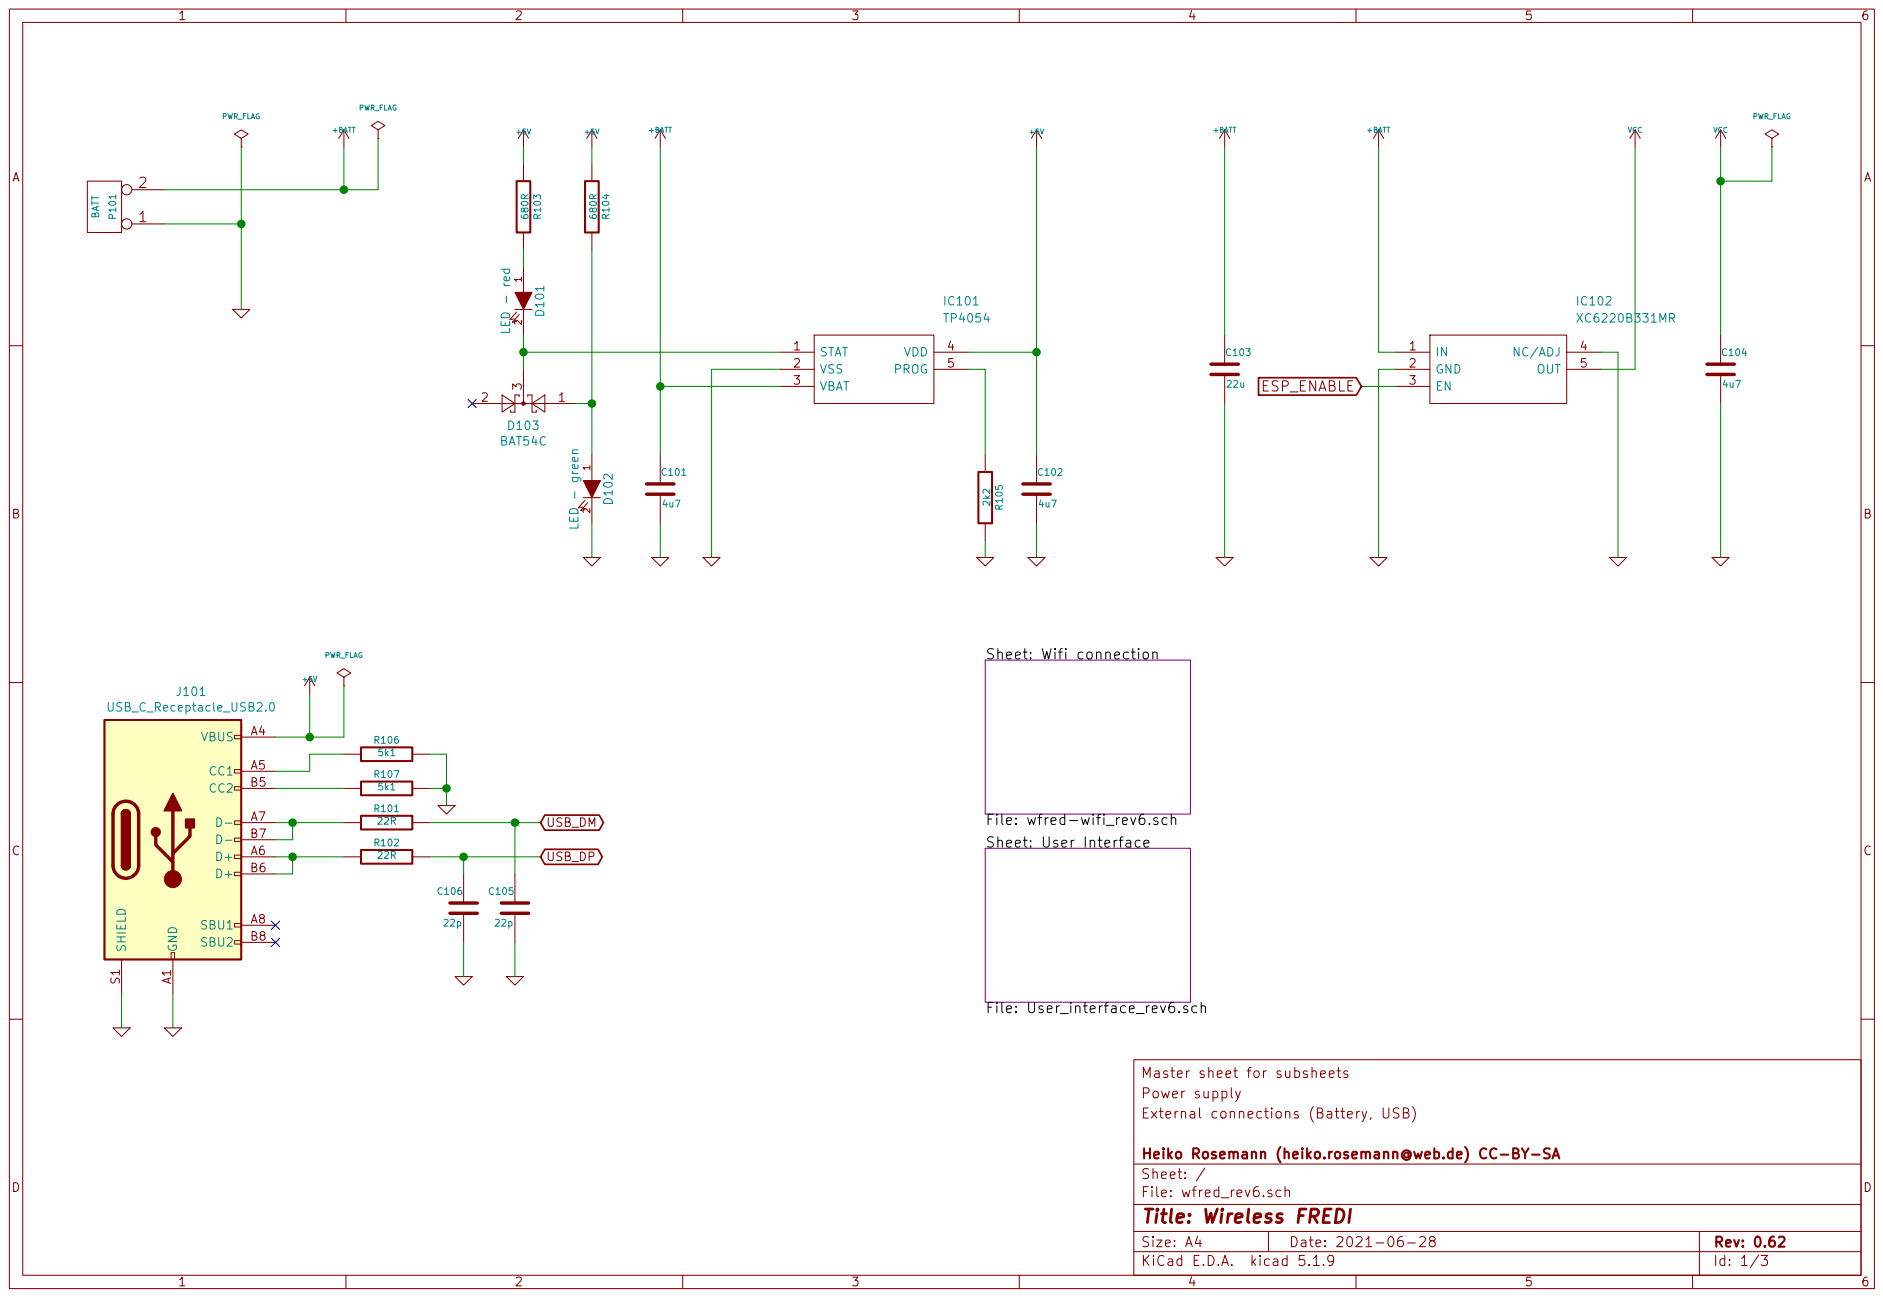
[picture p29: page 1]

Power supply Master sheet for subsheets Sheet: User Interface

External connections (Battery, USB)

File: wfred_rev6.sch Sheet: / Heiko Rosemann (heiko.rosemann@web.de) CC-BY-SA

Id: 1/3 Title: Wireless FREDI

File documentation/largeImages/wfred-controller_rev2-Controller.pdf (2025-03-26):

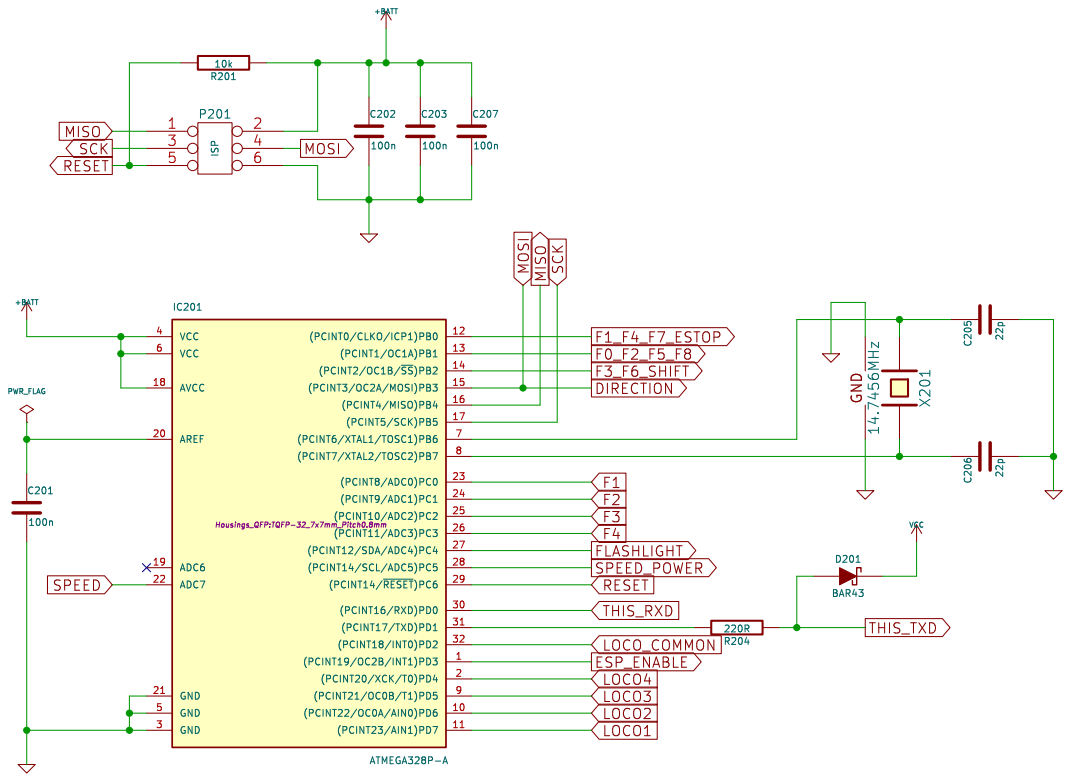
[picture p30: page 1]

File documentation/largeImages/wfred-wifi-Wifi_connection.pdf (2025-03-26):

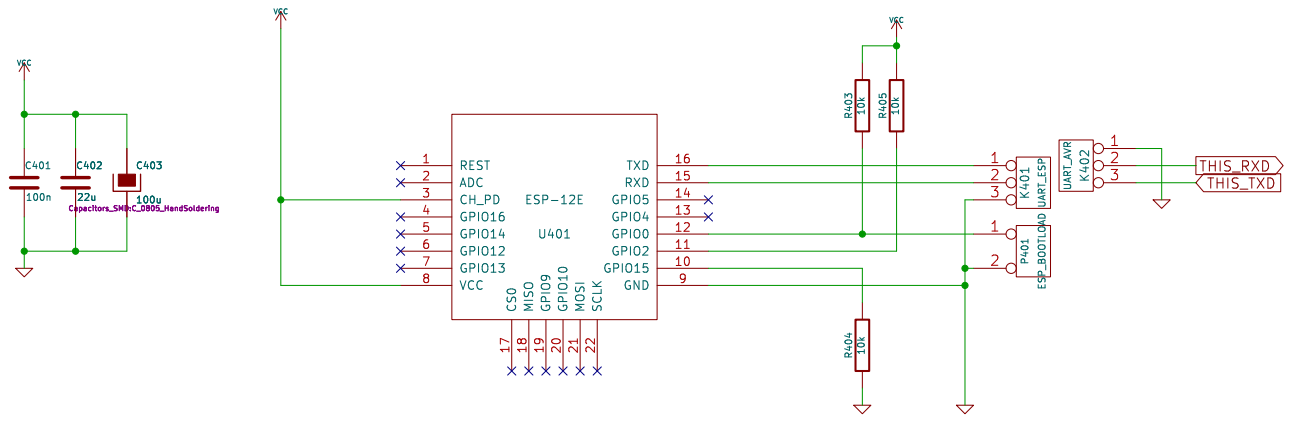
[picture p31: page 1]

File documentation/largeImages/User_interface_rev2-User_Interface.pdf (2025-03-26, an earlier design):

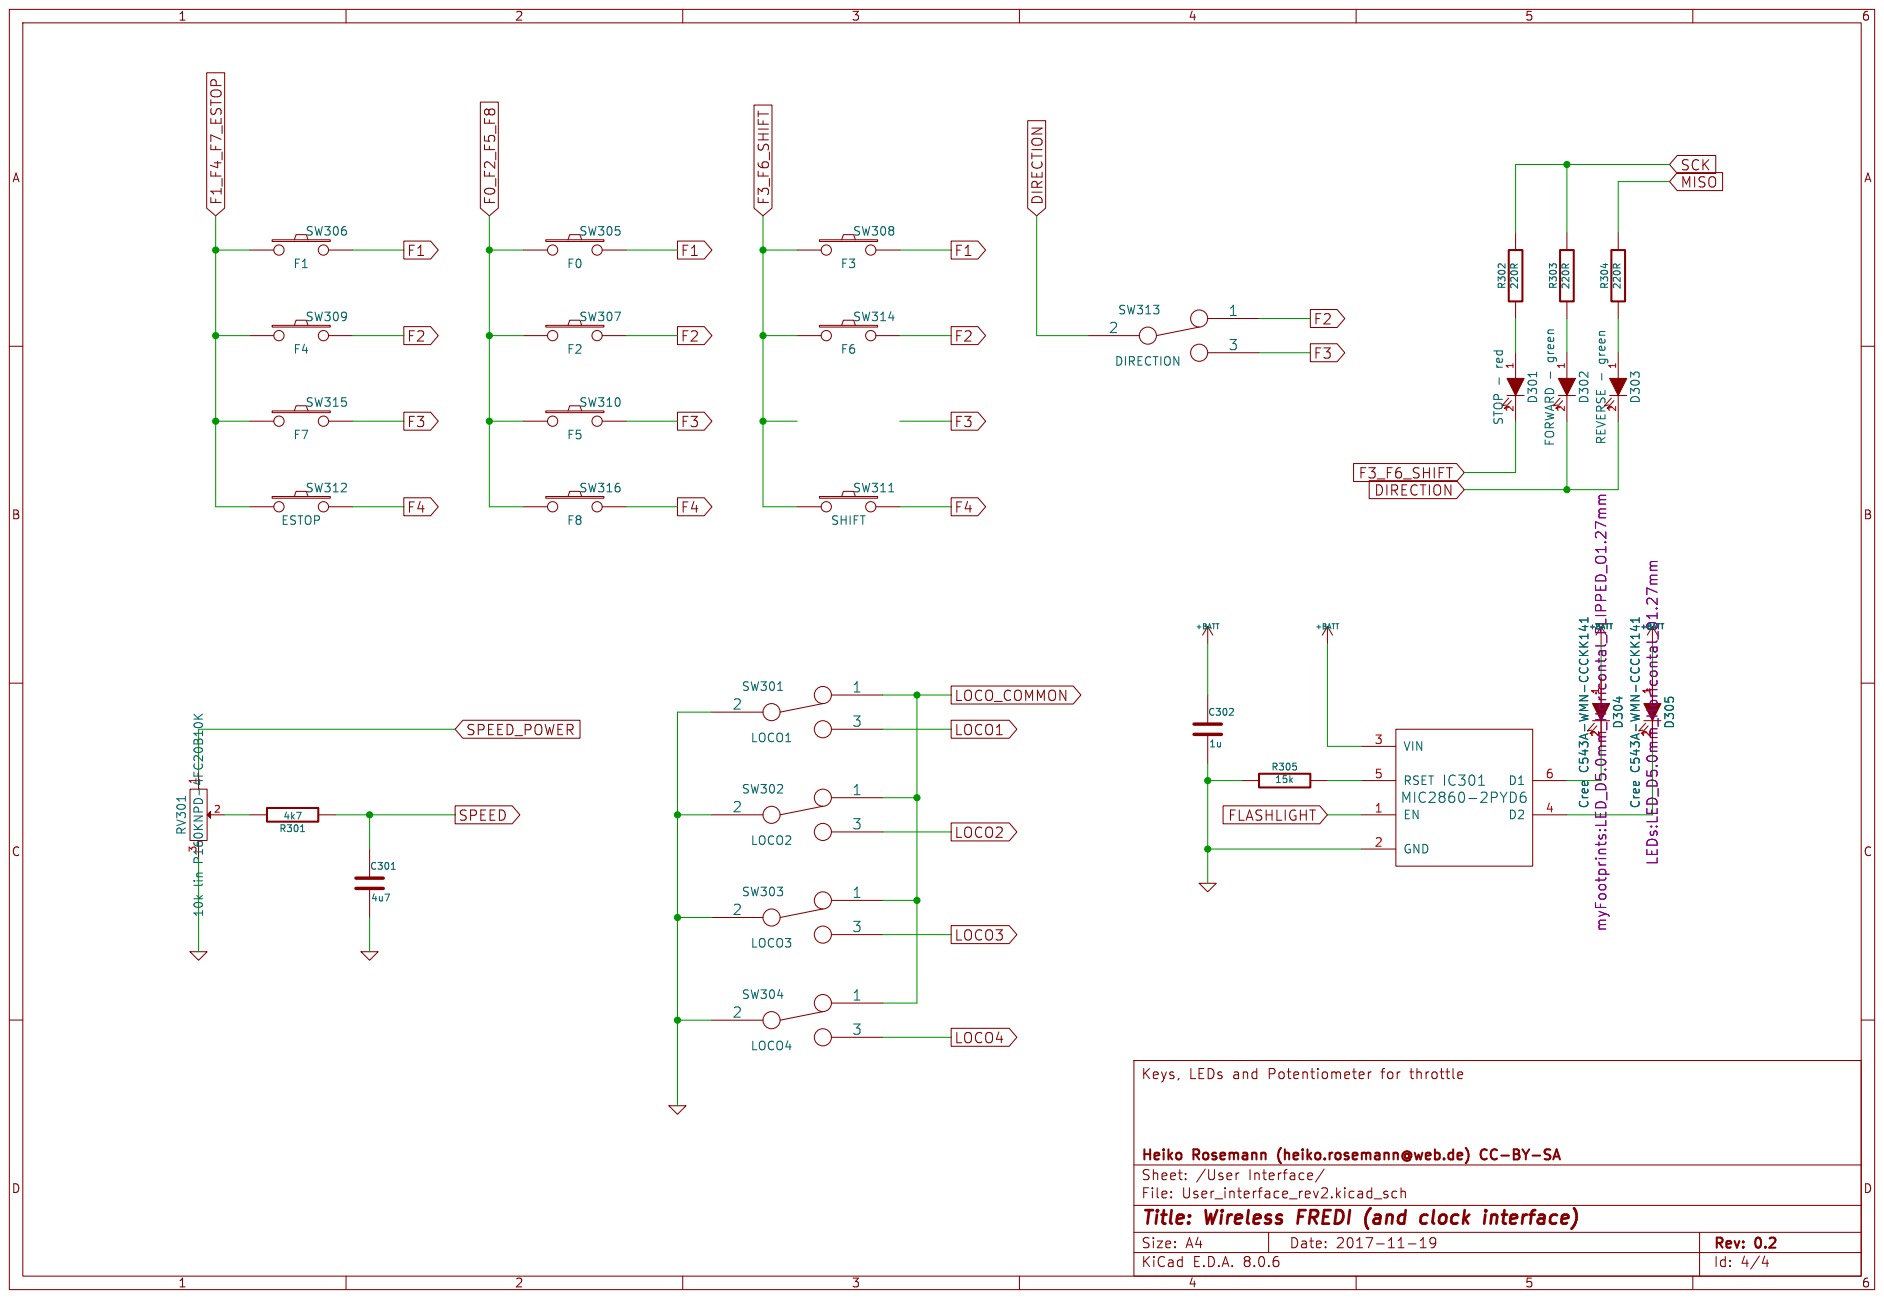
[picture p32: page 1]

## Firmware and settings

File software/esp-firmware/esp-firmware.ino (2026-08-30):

/**
 * This file is part of the wiFred wireless model railroading throttle project
 * Copyright (C) 2018-2026 Heiko Rosemann
 *
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
 * This file ties everything together to initialize the hardware and
 * form the main loop.
 * 
 * This project was made for ESP32-S2
 * with Arduino ESP32 from the 3.3 series
 * 
 * Versions:
 *    Arduino IDE 1.8.19
 *    esp32 3.3.11
 * 
 * Libraries:
 *    ArduinoJson 7.4.3
 *    SafeString 4.1.45
 * 
 * Board settings:
 *    Board: "ESP32S2 Dev Module"
 *    Upload Speed: "921600"
 *    USB CDC On Boot: "Disabled"
 *    USB Firmware MSC On Boot; "Disabled"
 *    USB DFU On Boot: "Disabled"
 *    Upload Mode: "UART0"
 *    CPU Frequency: "160MHz (WiFI/BT)
 *    Flash Frequency: "40 MHz"
 *    Flash Mode "QIO"
 *    Flash Size: "4MB (32Mb)"
 *    Partion Scheme: "Default 4MB with spiffs (1.2MB APP/1.5MB SPIFFS)"
 *    Core Debug Level: "None"
 *    PSRAM: "Disabled"
 *    Erase All Flash Before Sketch Upload: "Disabled"
 *    Port: "COMxx"
 */
/* Boards:
 * - ESP32S2 Dev Module * esp32:esp32:esp32s2:UploadSpeed=921600,CDCOnBoot=default,MSCOnBoot=default,DFUOnBoot=default,UploadMode=default,CPUFreq=160,FlashFreq=40,FlashMode=qio,FlashSize=4M,PartitionScheme=default,DebugLevel=none,PSRAM=disabled,EraseFlash=none,JTAGAdapter=default,CONSOLEBAUD=115200
 */

#include "wifiHandling.h"
#include "config.h"
#include "locoHandling.h"
#include "lowbat.h"
#include "stateMachine.h"
#include "throttleHandling.h"

#define DEBUG

state wiFredState = STATE_STARTUP;
uint32_t stateTimeout = UINT32_MAX;

void setup() {
// put your setup code here, to run once:

  delay(100);

  Serial.begin(115200);
  Serial.setTimeout(10);
  initConfig();

  initThrottle();
  
  #ifdef DEBUG
  Serial.setDebugOutput(true);
  #else
  Serial.setDebugOutput(false);
  #endif
  
  delay(100);

  initWiFi();

}

void loop() {
  // put your main code here, to run repeatedly:
  handleWiFi();
  handleThrottle();

  // check for empty battery
  // only if not online and not on the path for wiFred reset
  // if online, check will be done in locoHandler
  // (to disconnect before power down)
  if(emptyBattery &&
      wiFredState != STATE_LOCO_ONLINE &&
      wiFredState != STATE_WAIT_ON_RED_KEY &&
      wiFredState != STATE_STARTUP &&
      wiFredState != STATE_LOWPOWER_WAITING &&
      wiFredState != STATE_LOWPOWER)
  {
    switchState(STATE_LOWPOWER_WAITING, 100);
  }
  
  static uint32_t nextOutput = 0;

  if(nextOutput < millis())
  {
    nextOutput = millis() + 5000;
    log_d("Heap: %d", ESP.getFreeHeap());
  }

  switch(wiFredState)
  {
    case STATE_STARTUP:
      showVoltageIfOff("0/0", "0/0", "100/200");
      if(getInputState(KEY_ESTOP))
      {
        switchState(STATE_WAIT_ON_RED_KEY, WAIT_ON_KEY_TIMEOUT);
      }
      else if(getInputState(KEY_SHIFT))
      {
        switchState(STATE_WAIT_ON_YELLOW_KEY, WAIT_ON_KEY_TIMEOUT);
      }
      else
      {
        switchState(STATE_CONNECTING, TOTAL_NETWORK_TIMEOUT_MS);
        initWiFiSTA();
      }
      break;
      
    case STATE_CONNECTING:
      showVoltageIfOff("0/0", "0/0", "100/200");
      if(WiFi.status() == WL_CONNECTED)
      {
        initMDNS();
        if(getInputState(KEY_F0))
        {
          switchState(STATE_WAIT_ON_F0_KEY, WAIT_ON_KEY_TIMEOUT);
        }
        else
        {
          switchState(STATE_CONNECTED, TOTAL_NETWORK_TIMEOUT_MS);
          broadcastUDP();
        }
      }
      else if(millis() > stateTimeout)
      {
        initWiFiAP();
        switchState(STATE_CONFIG_AP);
      }
      break;

    case STATE_CONNECTED:
      showVoltageIfOff("0/0", "0/0", "25/50");
      if(WiFi.status() != WL_CONNECTED)
      {
        switchState(STATE_STARTUP);
      }
      locoConnect();
      if(millis() > stateTimeout)
      {
        initWiFiConfigSTA();
        switchState(STATE_CONFIG_STATION_WAITING, 120 * 1000);
      }
      break;

    case STATE_LOCO_CONNECTING:
      if(WiFi.status() != WL_CONNECTED)
      {
        switchState(STATE_STARTUP);
      }
      locoRegister();
      if(millis() > stateTimeout)
      {
        initWiFiConfigSTA();
        switchState(STATE_CONFIG_STATION_WAITING, 120 * 1000);
      }
      break;

    case STATE_LOCO_WAITFORTIMEOUT:
      if(WiFi.status() != WL_CONNECTED)
      {
        switchState(STATE_STARTUP);
      }
      if(timeoutReceived() || millis() > stateTimeout)
      {
        switchState(STATE_LOCO_ONLINE);      
      }
      break;

    case STATE_LOCO_ONLINE:
      if(WiFi.status() != WL_CONNECTED)
      {
        switchState(STATE_STARTUP);
      }
      locoHandler();
      break;
    
    case STATE_CONFIG_STATION_WAITING:
      showVoltageIfOff("200/200", "200/200", "200/200");
      if(WiFi.status() != WL_CONNECTED)
      {
        switchState(STATE_STARTUP);
      }
      if(millis() > stateTimeout)
      {
        shutdownWiFiConfigSTA();
        switchState(STATE_LOCO_ONLINE);
      }
      break;

    case STATE_CONFIG_STATION:
      showVoltageIfOff("200/200", "200/200", "200/200");
      if(WiFi.status() != WL_CONNECTED)
      {
        initWiFiAP();
        switchState(STATE_STARTUP);
      }
      break;

    case STATE_LOCOS_OFF:
      showVoltage();
      if(millis() > stateTimeout)
      {
        locoDisconnect();
        switchState(STATE_LOWPOWER_WAITING, 100);
      }
      if(!allLocosInactive())
      {
        switchState(STATE_LOCO_ONLINE);
      }
      break;

    case STATE_LOWPOWER_WAITING:
      setLEDvalues("0/0", "0/0", "1/250");
      if(millis() > stateTimeout)
      {
        shutdownWiFiSTA();
        switchState(STATE_LOWPOWER, 60000);
      }
      if(!allLocosInactive() && !lowBattery && !emptyBattery)
      {
        switchState(STATE_LOCO_ONLINE);
      }
      break;
    
    case STATE_LOWPOWER:
      setLEDvalues("0/0", "0/0", "1/250");
      // shut down ESP if low on battery or inactivity timeout plus delay reached
      if(lowBattery || emptyBattery || millis() > stateTimeout)
      {
        delay(1000);
        ESP.deepSleep(0);
      }
      // restart when user reenables a loco switch
      else if(!allLocosInactive())
      {
        ESP.restart();
      }
      // else wait for RC delay to switch off power
      break;
      
    case STATE_CONFIG_AP:
    // no way to get out of here except for restart
      showVoltageIfOff("0/0", "0/0", "200/200");
      break;

    case STATE_WAIT_ON_RED_KEY:
      setLEDvalues("0/0", "25/50", "25/50");
      if(!getInputState(KEY_ESTOP))
      {
        showVoltageIfOff("0/0", "0/0", "100/200");
        initWiFiSTA();
        switchState(STATE_CONNECTING, TOTAL_NETWORK_TIMEOUT_MS);
      }
      else if(millis() > stateTimeout)
      {
        // delete all configuration info
        deleteAllConfig();
        // wait for key release, then restart
        while(getInputState(KEY_ESTOP))
        {
          setLEDvalues("0/0", "0/0", "0/0");
        }
        ESP.restart();
      }
      break;

    case STATE_WAIT_ON_YELLOW_KEY:
      setLEDvalues("25/50", "0/0", "25/50");
      if(!getInputState(KEY_SHIFT))
      {
        showVoltageIfOff("0/0", "0/0", "100/200");
        initWiFiSTA();
        switchState(STATE_CONNECTING, TOTAL_NETWORK_TIMEOUT_MS);
      }
      else if(millis() > stateTimeout)
      {
        initWiFiAP();
        switchState(STATE_CONFIG_AP);
      }
      break;

    case STATE_WAIT_ON_F0_KEY:
      setLEDvalues("25/50", "25/50", "0/0");
      if(!getInputState(KEY_F0))
      {
        switchState(STATE_CONNECTED, TOTAL_NETWORK_TIMEOUT_MS);
      }
      else if(millis() > stateTimeout)
      {
        initWiFiConfigSTA();
        switchState(STATE_CONFIG_STATION);
      }
      break;
  }
}

const char* nameState(state x)
{
  switch (x)
  {
    case STATE_STARTUP:                 return "STARTUP";
    case STATE_CONNECTING:              return "CONNECTING";
    case STATE_CONNECTED:               return "CONNECTED";
    case STATE_LOCO_CONNECTING:         return "LOCO_CONNECTING";
    case STATE_LOCO_WAITFORTIMEOUT:     return "LOCO_WAITFORTIMEOUT";
    case STATE_LOCO_ONLINE:             return "LOCO_ONLINE";
    case STATE_LOCOS_OFF:               return "LOCOS_OFF";
    case STATE_CONFIG_AP:               return "CONFIG_AP";
    case STATE_CONFIG_STATION_WAITING:  return "CONFIG_STATION_WAITING";
    case STATE_CONFIG_STATION:          return "CONFIG_STATION";
    case STATE_LOWPOWER_WAITING:        return "LOWPOWER_WAITING";
    case STATE_LOWPOWER:                return "LOWPOWER";
    case STATE_WAIT_ON_RED_KEY:         return "WAIT_ON_RED_KEY";
    case STATE_WAIT_ON_YELLOW_KEY:      return "WAIT_ON_YELLOW_KEY";
    case STATE_WAIT_ON_F0_KEY:          return "WAIT_ON_F0_KEY";
    default:                            return "<invalid>";
  }
} 

void switchState(state newState, uint32_t timeout)
{
  log_d("Old state: %d: %s, New state: %d: %s", wiFredState, nameState(wiFredState), newState, nameState(newState));
  wiFredState = newState;
  if(timeout == UINT32_MAX)
  {
    stateTimeout = timeout;
  }
  else
  {
    stateTimeout = millis() + timeout;
  }
}

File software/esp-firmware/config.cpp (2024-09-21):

/**
 * This file is part of the wiFred wireless model railroading throttle project
 * Copyright (C) 2018-2022 Heiko Rosemann
 *
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
 * This file provides functions for handling configuration settings in
 * non-volatile memory.
 */

#include <stdbool.h>
//sloeber>> #include <string.h>      // strndup(), strdup()
#include <FS.h>
#include <SPIFFS.h>
//sloeber>> #include <WString.h>     // class String
#include <ArduinoJson.h>

#include "config.h"
#include "wifiHandling.h"
#include "locoHandling.h"
#include "throttleHandling.h"

char * throttleName;

/*
 * Read all configuration from EEPROM
 */
void initConfig(void)
{
// initialize to default values
  uint8_t mac[6];
  WiFi.macAddress(mac);
  String tN = "wiFred-" + String(mac[3], 16) + String(mac[4], 16) + String(mac[5], 16);
  throttleName = strdup(tN.c_str());

  locoServer.automatic = true;
  locoServer.name = strdup("undef");
  locoServer.port = 12090;

  for(int i=0; i<4; i++)
  {
    locos[i].address = -1;
    locos[i].mode = strdup(MODE_DEFAULT); // allocate on heap
    locos[i].direction = DIR_NORMAL;
    locos[i].longAddress = true;
    for(int j=0; j<MAX_FUNCTION + 1; j++)
      {
	      locos[i].functions[j] = THROTTLE;
      }
  }

  potiMin = 1100;
  potiMax = 1100;
  battFactor = 1.05f;

  centerFunction = CENTER_FUNCTION_IGNORE;
  
  if(!SPIFFS.begin())
  {
    return;
  }
  
  JsonDocument doc;

// read device name from SPIFFS (deprecated)
  if(File f = SPIFFS.open(FN_NAME, "r"))
  {
    if(!deserializeJson(doc, f))
    {
      const char * s = doc[FIELD_NAME_NAME];
      if(s != nullptr)
      {
        free(throttleName);
        throttleName = strdup(s);
      }
    }
    f.close();
  }

// read general configuration from SPIFFS
  if(File f = SPIFFS.open(FN_CONFIG, "r"))
  {
    if(!deserializeJson(doc, f))
    {
      const char * s = doc[FIELD_NAME_NAME];
      if(s != nullptr)
      {
        free(throttleName);
        throttleName = strdup(s);
      }
      centerFunction = doc[FIELD_CONFIG_CENTERSWITCH] | CENTER_FUNCTION_IGNORE;
    }
    f.close();
  }

// read server configuration/information from SPIFFS
  if(File f = SPIFFS.open(FN_SERVER, "r"))
  {
    if(!deserializeJson(doc, f))
    {
      const char * s = doc[FIELD_SERVER_NAME];
      if(s != nullptr)
      {
        free(locoServer.name);
        locoServer.name = strdup(s);
      }
      uint16_t p = doc[FIELD_SERVER_PORT];
      if(p != 0)
      {
        locoServer.port = p;
      }
      if(doc[FIELD_SERVER_AUTOMATIC].is<bool>())
      {
        locoServer.automatic = doc[FIELD_SERVER_AUTOMATIC];
      }
    }
    f.close();
  }

// read as many wifi configurations as there are available from SPIFFS  
  for(uint8_t i = 0; true; i++)
  {
    // create new filename
    String filename = String(FN_WIFI_STUB) + i + ".txt";
    // check if it exists, exit loop if not
    if(!SPIFFS.exists(filename))
    {
      break;
    }

    if(File f = SPIFFS.open(filename, "r"))
    {
      if(!deserializeJson(doc, f))
      {
        wifiAPEntry newAP;
        newAP.ssid = strdup(doc[FIELD_WIFI_SSID] | "");
        newAP.key = strdup(doc[FIELD_WIFI_PSK] | "");
        if(doc[FIELD_WIFI_DISABLED].is<bool>())
        {
          newAP.disabled = doc[FIELD_WIFI_DISABLED];
        }
  
        if(strcmp(newAP.ssid, ""))
        {
          apList.push_back(newAP);
        }
        else
        {
          free(newAP.ssid);
          free(newAP.key);
        }
      }
      f.close();
    }
  }

  // read four loco configurations from SPIFFS if available
  for(uint8_t i = 0; i < 4; i++)
  {
    // create new filename
    String filename = String(FN_LOCO_STUB) + (i+1) + ".txt";
    // check if it exists
    if(!SPIFFS.exists(filename))
    {
      continue;
    }

    if(File f = SPIFFS.open(filename, "r"))
    {
      if(!deserializeJson(doc, f))
      {
        locos[i].address = doc[FIELD_LOCO_ADDRESS] | -1;
        if(doc[FIELD_LOCO_MODE].is<String>())
        {
          free(locos[i].mode);
          locos[i].mode = strdup(doc[FIELD_LOCO_MODE]);
        }
        if(doc[FIELD_LOCO_LONG].is<bool>())
        {
          locos[i].longAddress = doc[FIELD_LOCO_LONG];
        }
        if(doc[FIELD_LOCO_REVERSE].is<bool>())
        {
          locos[i].reverse = doc[FIELD_LOCO_REVERSE];
          if(locos[i].reverse)
          {
            locos[i].direction = DIR_REVERSE;
          }
          else
          {
            locos[i].direction = DIR_NORMAL;
          }
        }
        if(doc[FIELD_LOCO_DIRECTION].is<int>())
        {
          locos[i].direction = doc[FIELD_LOCO_DIRECTION];
        }
        for(uint8_t j = 0; j < MAX_FUNCTION + 1; j++)
        {
          locos[i].functions[j] = (functionInfo) doc[FIELD_LOCO_FUNCTIONS][j].as<int>();
        }
      }
      f.close();
    }
  }
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

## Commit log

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2018-01-06 Bugfix: Moved PCB mounting holes to correct corners
    (had been fitting for original FRED with UI on screw side,
    which does not fit housing with battery cover)
    [wfred_loconet_clock.kicad_pcb, wfred_rev2.kicad_pcb]
2018-01-08 Bugfix: Increased SW313 mounting hole clearance
    plus made GND fill distance to PCB edges larger for panelizing
    [wfred_loconet_clock.kicad_pcb, wfred_rev2.kicad_pcb]
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2018-03-18 WiFi Bug fix and refactoring
    - Fixed a bug in lowbat handling eating too much CPU time
    so WiFi would not work
    - Began refactoring WiFi - using ESP8266WebServer, a lot of my
    serving and argument-handling code is obsolete
    - Added a status page
    [arduino_main_sketch.ino.ino, config.cpp, config.h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]
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2018-03-25 Bugfix: Clock rate initialization was wrong...
    ...did not take into account the edge counter changes for low battery
    signalling.
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2018-04-09 Bugfix: If state switch timeout == maximum, don't overflow
    [arduino_main_sketch.ino.ino]
2018-04-09 Bugfixes in handle clock configuration page
    - server.arg returns unescaped strings -> replace %%3A with : in
    sscanf filtering
    - arguments to sscanf need to be aligned to 4 bytes -> alignas(4)
    - Removed debug printouts
    [wifi.cpp]
2018-04-09 Bugfixes in WiFi startup/shutdown, time saving
    - Increased startup timeout for WiFi connection
    - Added reset to DHCP for leaving config mode/shutdown
    - Limiting startup hours to [0..11] instead of [0..23]
    [arduino_main_sketch.ino.ino, wifi.cpp]
2018-04-10 Reboot WiFi if connection is lost
    [arduino_main_sketch.ino.ino]
2018-04-10 Debugging memory leak in clockHandling.cpp
    Seems like WiFiClient needs to be re-created and destroyed at every
    call.
    We'll see how to handle that with loco control...
    [arduino_main_sketch.ino.ino]
2018-04-11 Changed low battery detection after first test run
    - changed hardware: Reduced R402 from 100kOhm to 47kOhm so battery
    voltage can be measured above 2V
    - changed firmware accordingly (instead of * 2 now calculate * 147 / 47
    and * 1000 / 1024 to correct for 10Bit = 1V
    - raised thresholds for low and empty battery voltate - on first test,
    battery still showed 1988mV one minute and system was down the next
    minute (after 12 hours)
    [wfred-wifi.sch]
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2018-04-13 Returned to re-using WiFiClient
    - Memory leak was due to bug in arduino core 2.4.0/2.4.1
    (see esp8266/Arduino#4497 also for workaround implemented here)
    - This removes 10ms delay after connection, will look for available data at
    every main loop run instead.
2018-05-25 First version of usage documentation for throttle
    Figures and tables still missing
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2018-06-04 Fixed compiler error due to wrong definitions
    - Wrong MCU set in Makefile
    - Wrong names for some UART registers
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2018-06-04 Fixed two small bugs:
    - ledInfo should have been volatile
    - Fixed an off-by-one error in reading in LED info from UART
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2018-06-05 Timer init added to main, corner case cycle time=0 bugfix
    - Added missing includes to main
    - Added timer initialization to main
    - Fixed a corner case bug for LED cycle time == 0 to timer
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2018-06-09 Added support for DCC short addresses
    - Added longAddress checkbox and internal config parameter
    - Added checks for out-of-range short addresses
    - Changed maximum long address to 10239 as per NMRA standard
    [config.cpp, wifi.cpp]
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2018-06-09 git FU: commit --amend went wrong, fixed now
    [locoHandling.cpp]
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2018-06-10 Added keypad handling and loco messaging
    - Including: Reaction to input changes on loco selection
    - Missing: Function parsing when loco is acquired
    [arduino_main_sketch.ino.ino, locoHandling.cpp, throttleHandling.cpp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]
2018-06-11 Fixed a few bugs in loco connection
    [locoHandling.cpp, wifi.cpp]
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2018-06-11 Fixed bugs in sscanf( ... (unsigned int *) uint8_t
    [throttleHandling.cpp, wifi.cpp]
2018-06-11 Some bugfixes in connect/reconnect to loco server
    [arduino_main_sketch.ino.ino, locoHandling.cpp]
2018-06-11 Fixing bugs... next test on real layout :)
    [arduino_main_sketch.ino.ino, locoHandling.cpp, throttleHandling.cpp]
2018-06-12 Fixing some disconnect/reconect bugs
    [locoHandling.cpp, throttleHandling.cpp]
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2018-06-22 Small documentation improvements
    - Corrected shift and function key numbers
    - Clearer wording in the last sentence of the abstract
    - Added right and left instructions for direction toggle switch
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2018-06-23 Realized there was a bug in function status saving
    - While documenting this feature, I realized the function status of
    throttle controlled functions (remembered for acquiring a new loco)
    has to be toggled when function keys are pressed.
    [locoHandling.cpp, throttleHandling.cpp]
2018-07-14 Debugging communication between AVR and ESP
    - AVR: Don't go to sleep when no keep alive has been received
    - AVR: Added second timer initialization
    - ESP: Moved LED setup from state switching into states
    - ESP: Removed debugging - was resulting in too much data from AVR in
    response
    - ESP: Added "flush serial port input buffer"
    [arduino_main_sketch.ino.ino, locoHandling.cpp, wifi.cpp]
2018-07-15 Bugfix: Really send a WiFi packet when new speed
    [throttleHandling.cpp]
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2018-07-15 Searching for LED bugs
    [arduino_main_sketch.ino.ino, throttleHandling.cpp]
2018-07-15 Fix a bug in emergency stop recovery
    [throttleHandling.cpp]
2018-07-15 Re-implement UART receive handling on AVR
    ...to enable multiple messages in a short timeframe
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2018-07-15 Changed LED handling on ESP side
    - Only send one LED at a time after changes (to give AVR more time)
    - Reversed LED1 and LED2 meaning for forward/reverse to match Fredi and
    direction switch
    [throttleHandling.cpp]
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2018-11-04 Switched schematic over to LiPo cell
    - Removed AA battery holder
    - Removed switching power regulator
    - Added micro USB connector
    - Added two pin battery connector
    - Added LiPo charging IC
    - Added 3.0V linear regulator
    - Replaced ATMega328 with ATMega32
    - Added F5-F8 keys
    - Removed SHIFT2 key
    - Moved LOCO keys from ESP to ATMega32
    [User_interface_rev2.sch, wfred-controller_rev2.sch, wfred-wifi.sch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]
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2018-11-04 Added ESP reset connection to AVR
    - Enables ESP to go into deep sleep and be woken up by AVR
    [wfred-controller_rev2.sch, wfred-wifi.sch]
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2018-11-07 Changed function keys for better PCB layout
    - Replaced super-splim KSC621 with regular PTS645 (fits now)
    - Redistributed keys to nets for key matrix to make PCB layout
    nicer/easier
    [User_interface_rev2.sch, wfred_rev2.kicad_pcb]
2018-11-08 Fixed PCB with key matrix
    [wfred_rev2.kicad_pcb]
2018-11-11 Fixed silk screen, exported PCB for manufacturing
    [wfred_rev2.kicad_pcb]
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2018-12-26 Fixed a bug where the device did not wake up
    - changed the sequence of sleep enabling according to the avr-libc
    documentation to make sure the IRQ would not get called and
    deactivated before the device goes to sleep
2019-01-24 Commenting out workarounds for Arduino bug...
    - ...fixed in 2.4.2
    - Original Issue was: https://github.com/esp8266/Arduino/issues/4497
    [locoHandling.cpp]
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2019-02-04 Add code to measure battery voltage
    - Reverse measurement: Measure (constant) internal reference voltage
    using battery voltage as reference
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2019-02-09 Fix bugs in voltage measurement and power mgmt
    - Don't calculate bandgap voltage but adjust in single steps
    - Add LED blink when AVR on but ESP off
    - Only small timeout at wakeup
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2019-02-09 Fixed PCB: Added proper GND connection...
    ...and removed unrequired power measurement resistors
    [User_interface_rev2.sch, wfred-controller_rev2.sch, wfred-wifi.sch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]
2019-02-09 Further reduce IDLE power consumption
    - Switch from "full swing" to "low power" oscillator -1mA
    - Reduce clock frequency by 50% (to be tested!) -1mA
    Now at 2.5...3mA power consumption in IDLE.
    Less than 1uA in POWER DOWN.
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2019-03-04 Switched back to 3.686MHz to fix key debouncing - too long for 1.843MHz
2019-03-04 Change handling of new speed value
    - only send if UART queue is clear
    - do not clear "new speed trigger" when not sending
    This reduces the noise on the serial port when quickly turning the
    potentiometer and removes the need for a "TOLERANCE" before signalling a
    new value.
2019-03-04 Fix off-by-one errors in uart_send...
    ...because sizeof("text") == 5, including the '\0'-terminator byte
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2019-03-04 Only send loco add/remove command when switch correct
    When booting up, after waiting for the ESP to connect and signal ONLINE,
    this helps avoid spurious loco connects
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2019-03-07 PCB changes
    - Add extra 100uF capacitor for ESP8266 power supply
    - Turn battery connector to avoid pushing pins across screw
    [wfred-wifi.sch, wfred_rev2.kicad_pcb]
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2019-03-13 Re-structured documentation
    - Moved background info to end of document
    - Renamed wiThrottle description chapter to describe first prototypes
    and moved it after the server options chapter
    - Added wiThrottle description chapter for lithium battery versions
    - Pulled configuration sub-chapter into separate chapter, renaming the
    other chapters "hardware"
    - Removed description of wiClock from document, replaced with a
    reference to WiFi-JMRI-Clock project on github
    - Added some text describing the history of the project
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2019-05-04 Corrected ordering information for black switches
    Taster 9319 (Reichelt) is too long, may cause shorts
    [wfred_rev5-Partlist.ods]
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2019-05-06 Turn off UART TX pin when shutting down ESP...
    ...to avoid shadow power through clamping diodes.
    This fixes some cases where the ESP8266 does not restart because its
    supply voltage never dropped low enough. Hard to track down, because it
    only happens on some boards, depending on part tolerances.
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2019-05-07 Add a clamping diode to AVR TXD...
    ...to avoid overloading the ESP internal body diodes
    [User_interface_rev2.sch, wfred-controller_rev2.sch, wfred-wifi.sch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]
2019-05-07 Fixed merge conflicts from last commit in pcbNew
    [User_interface_rev2.sch, wfred-controller_rev2.sch, wfred-wifi.sch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]
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2019-06-16 Revert "Increase key-and-LED-matrix frequency by 8"
    This reverts commit 24f7a4169bf681b2536f77eeb015e35bfb2ec6f1.
    Apparently, the flicker has a different source.
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2019-06-21 Revert "When losing connection during configuration mode..."
    This reverts commit 5aeb60a8d5359dc42c685daffec4a358968f8e16.
    [arduino_main_sketch.ino.ino]
2019-06-21 Fix up cherry-picks from wiClock project...
    ...to make the firmware compile again.
    Also added TODO-#warnings where appropriate.
    Configuration HTML pages need reworking too.
    [config.cpp, locoHandling.cpp, wifi.cpp]
2019-06-28 Fix off-by-one errors in writing loco config
    [config.cpp]
2019-07-01 Bugfix: Null pointer access
    [config.cpp, locoHandling.cpp]
2019-07-01 Bugfix: add braces around loco+1 to avoid string...
    ...concatenation before arithmetic addition
    Also removed unconditional debug output
    [config.cpp]
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2019-07-01 Fix bug in reset configuration data...
    ...link target was missing .html
    [wifi.cpp]
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2019-07-21 Cherry-picked small fixes from AABatteryPrototype
    [arduino_main_sketch.ino.ino, locoHandling.cpp, wifi.cpp]
2019-07-27 Add some timeout for empty battery
    - will re-enable device if battery voltage comes back
    - to avoid glitches
2019-07-27 Match full string "PWR_DOWN" instead of first "P"
    Should avoid spurious power down events
    [throttleHandling.cpp]
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2019-08-18 Workaround a bug in voltage transmission
    For some unknown reason, 'V' after the speed command got distorted
    sometimes. When transmitting "BOK" between speed and voltage, this does
    not happen.
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2019-08-18 Added missing break; to last switch-case statement
    [throttleHandling.cpp]
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2019-11-16 Added C302 to partlist - was missing before
    [wfred_rev5-Partlist.ods]
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2019-12-03 PCB: Fixed silkscreen to be legible
    - Moved silkscreen away from holes and overlaps
    - Upgraded revision to 0.51 (no copper changes)
    [wfred_rev2.kicad_pcb]
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2021-02-06 Fix building and flashing process
    - Unused fusebits set to 1 to enable verify
    - Removed saving eeprom step
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2021-02-06 Automatically format SPIFFS if mount fails
    [config.cpp]
2021-02-06 Remove call to client.flush()
    fails on ESP32 when there is no data to read.
    [locoHandling.cpp]
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2021-02-17 Converting documentation to asciidoc
    - Fixed two typos in abstract
    - Placed table rows on single lines
    - Started with AA battery prototype description
2021-02-19 Tested fix for images not showing on github.io
    - renamed _DSC to DSC
    - added icons
    Also removed a couple unused images
2021-02-20 Revert "Automatically format SPIFFS if mount fails"
    This reverts commit 4ee1db0e3e5ea1ba732a4ad6454a88523b2c5ff5.
    Not available for ESP8266, only for ESP32-S2
    [config.cpp]
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2021-02-20 Revert "Remove call to client.flush()"
    This reverts commit d0d50b67b0b6d91626fed427d2e3d976e6761402.
    Attempting to fix bug in old version...
    [locoHandling.cpp]
2021-02-20 Change loco connect handling to...
    ...skip over disabled locos
    [locoHandling.cpp]
2021-02-20 Handle new reverse options (WIP)
    [config.cpp, locoHandling.cpp]
2021-02-20 Fix URL get parameter missing loco.
    [wifi.cpp]
2021-02-20 Change loco connect handling to...
    (cherry picked from commit 5a72a248c3a0c15a45b8ae86a04c6cd85a256a4c)
    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
    [locoHandling.cpp]
2021-02-20 Handle new reverse options (WIP)
    (cherry picked from commit 61be35f47156db144b8669bc6474f96e46134998)
    [config.cpp, locoHandling.cpp]
2021-02-20 Fix URL get parameter missing loco.
    (cherry picked from commit e6cbfdc95be351f17c17309bc1ff76e60f2b0f77)
    [wifi.cpp]
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2021-02-24 Correct LEDs for first cycle
    [throttleHandling.cpp]
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2021-03-13 Replace magic number timeouts with define/variable
    [esp-firmware.ino, locoHandling.cpp]
2021-03-13 Correct pin definitions instead of placeholders
    [throttleHandling.h]
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2021-03-14 Switch forward and reverse key inputs
    [throttleHandling.h]
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2021-03-14 Fix IP address and Hostname logging
    [locoHandling.cpp]
2021-03-14 Add 1% tolerance around 0 for potiMin and potiMax
    [throttleHandling.cpp]
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2021-05-01 Transmit (N)ame before receiving greeting
    ...fix for LNWI
    [locoHandling.cpp]
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2021-06-12 Replace Micro-USB-B with USB-C connector
    ...including 5k1 resistors for CC-pins
    [wfred_rev6.sch]
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2021-06-14 Connect USB-C-connector and cleanup
    - Replace 2pin + 3pin for RS232 + BOOT with 2x3pin
    - Connect USB-C-connector
    - Add CC1 and CC2 resistors
    - Correct ESP32-S2-WROOM package for hand soldering
    - Increase pad sizes for user installed switches / poti
    - Correct direction switch pad distance (DRC violation)
    - Rearrange some traces and vias
    - Add LCSC numbers for pin headers
    [wfred-wifi_rev6.sch, wfred_rev6.kicad_pcb, wfred_rev6.sch]
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2021-06-27 WIP: Documentation: Added 0.6 hardware description
    Text done.
    Missing: Schematic images, BOM tables
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2021-08-01 Switch network scanning to passive...
    ...to avoid disconnecting clients when in AP mode
    [wifi.cpp]
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2021-08-01 Accept reverse at speed, just set ESTOP
    Mimics behaviour of Fredi
    [locoHandling.cpp]
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2021-08-01 Revert "Accept reverse at speed, just set ESTOP"
    This reverts commit 7680c6df1de334dfc5600c4e1dc69fd48ee9e95b.
    [locoHandling.cpp]
2021-08-01 Change reverse handling to state based
    [throttleHandling.cpp]
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2021-08-04 Fixed Partlist
    Designator and package to order info association was broken
    Still not 100% correct, designators have been reassigned for v0.5/v0.6,
    but good enough to calculate pricing
    [wfred_rev6-Partlist.ods]
2021-08-20 Broader analog input tolerance for zero and max
    [throttleHandling.cpp]
2021-08-20 Correct default value handling for analog values
    ...potiMin/potiMax and battFactor
    [config.cpp]
2021-08-21 Workaround for analog issue #5503 in arduino core
    See https://github.com/espressif/arduino-esp32/issues/5503
    Expected to be fixed in 2.0.0.
    [throttleHandling.cpp]
2021-08-21 Create an update path to next firmware version
    Do not read old, broken battery voltage calibration.
    [config.cpp]
2021-08-21 Revert "Create an update path to next firmware version"
    This reverts commit 15a7a629e112fa349f430bb6f854dc4a801656e3.
    [config.cpp]
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2021-09-03 Fix switch/poti holes to be PTH
    [wfred_rev6.kicad_pcb]
2021-10-03 Fix loco disconnect command
    Thanks to @paoSoft for catching my misunderstanding of the docs.
    Fixes #1.
    [locoHandling.cpp]
2021-10-04 Fixed disconnect problem + improved speed command handling
    [locoHandling.cpp]
2021-10-04 Bugfixing modified speed/heart schema
    [locoHandling.cpp]
2021-10-09 Add startup options to reset config / open AP mode
    Press and hold ESTOP for 5 seconds at startup to reset all configuration
    data.
    Press and hold SHIFT for 5 seconds at startup to open configuration AP
    instead of trying to connect to pre-configured network.
    Fixes #4 and #5.
    [esp-firmware.ino]
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2021-10-12 Slow down auto calibration. Fixes #10 (partly).
    [throttleHandling.cpp, throttleHandling.h, wifi.cpp]
2021-10-12 Very slowly reduce speed if not at zero.
    About 1 speed step in 5 minutes.
    This ensures the poti will reach zero eventually.
    Improve fix for #10.
    [throttleHandling.cpp]
2021-10-16 Skip low bat power down only if going for reset
    [esp-firmware.ino]
2021-10-16 Fix #13 - push F0 during connect to enable config
    [esp-firmware.ino]
2021-10-16 Realign loco server config on web page
    Fixes #14
    [wifi.cpp]
2021-10-16 Blink once per 100mV above 3500mV at power down
    (once at 3600mV, twice at 3700mV ...)
    Fixes #12
    [esp-firmware.ino]
2021-10-16 Add signal strength and WiFi name to status
    Fixes #15
    [wifi.cpp]
2021-10-16 Add signal strength to WiFi scan page
    Fixes #15 even further.
    [wifi.cpp]
2021-10-16 Follow-up fix for non-existant wifiKey...
    ...now possible after removing PSK field for open networks from scan
    page
    [wifi.cpp]
2021-10-16 Add an option to disable wifi networks
    Not saved into flash so far
    If no active networks available, go straight into config_AP mode
    As a side note, also fixes #6
    [wifi.cpp]
2021-10-16 Also save disabled status for WiFi networks
    Fixes #7
    [config.cpp, config.h]
2021-10-16 Fix bug in starting config ap with no networks
    [esp-firmware.ino]
2021-10-23 Revert "Blink once per 100mV above 3500mV at power down"
    This reverts commit 51d1d1de2de7428706d60149ecd2ec18185b186e.
    [esp-firmware.ino]
2021-10-23 Show battery voltage when turning off all switches
    Fixes #12.
    See documentation for exact description.
    (cherry picked from commit c83e356247edecc13b789761c1bd03eada83ed20)
    [esp-firmware.ino, locoHandling.cpp]
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2021-10-27 Remove easy to break release file
    This was the only release file with new low battery calibration, but
    without delete-all option. So installing this version easily leads to a
    broken wiFred that falsely detects a low battery.
2021-11-07 Replace CAT4002 with HX4004A...
    ...for flashlight LEDs.
    [User_interface_rev6.sch, wfred_rev6.kicad_pcb]
2021-11-07 Replace out-of-stock components with others
    [wfred_rev6.kicad_pcb, wfred_rev6.sch]
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2021-12-05 Fix center position setting and display
    [wifi.cpp]
2021-12-05 Fiddling with "zero speed -> allow reversing"
    [locoHandling.cpp, throttleHandling.cpp, throttleHandling.h]
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2021-12-17 Fixed a few HTML errors
    No functional changes, just moving <form> outside <table>
    (cherry picked from commit d8c660aa7b0e70732a0b12974f7748b8d7ad78ce)
    [wifi.cpp]
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2022-04-09 Correct default value for switch center position
    [config.cpp]
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2022-05-01 Change default direction switch setting to NORMAL
    - Same behaviour as classic Fredi
    - DONTCHANGE does not work correctly yet anyway #18
    [config.cpp]
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2022-05-06 Add MAC to config page, use 3 bytes for short MAC
    ...in default throttle name, config AP name.
    Fixes #19.
    Fixes #22.
    (cherry picked from commit 253bb82d1793401287eb7ba4296c7741b4b60db7)
    [config.cpp, wifi.cpp]
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2022-10-08 Fix compilation error due to missing switch cases
    Showed up after updating arduino core to 2.0.5
    [wifi.cpp]
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2022-10-09 Move flashlight LEDs further apart
    Fixes #21
    Also change rev to 0.64
    [wfred_rev6.kicad_pcb]
2022-10-09 Add anti-twist protection for direction switch
    Fixes #25.
    [wfred_rev6.kicad_pcb]
2022-10-09 Add silk screen texts for pushbutton colors
    Fixes #26.
    [wfred_rev6.kicad_pcb]
2022-10-09 Add silk screen texts for 3mm LED colors
    Fixes #27.
    [wfred_rev6.kicad_pcb]
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2022-10-11 Detect too low battery voltage after core change
    https://github.com/espressif/arduino-esp32/pull/6799
    Fixes #41.
    [config.cpp]
2022-10-11 Also show battery status turning off before online
    Fixes #32.
    [esp-firmware.ino, throttleHandling.cpp, throttleHandling.h]
2022-10-14 Allow immediate no-ESTOP reverse on zero speed
    Fixes #29.
    [locoHandling.cpp, throttleHandling.cpp]
2022-10-14 Activating/deactivating loco in center position...
    ...will now also set/reset function settings.
    Fully tested with momentary functions.
    Fixes #34.
    [locoHandling.cpp, throttleHandling.h]
2022-10-14 Match center position LED to (SWD-)Fredi
    Show both LEDs when in center position, just like Fredi and SWD-Fredi do
    it.
    Fixes #33.
    [locoHandling.cpp]
2022-10-14 Add a website to reboot and reset handlers.
    Fixes #31.
    [wifi.cpp]
2022-10-14 Add /flashred.html?count=x handler to blink red LED.
    Fixes #36.
    [throttleHandling.cpp, throttleHandling.h, wifi.cpp]
2022-10-15 Fix off-by-one error in blink number of times.
    Also allows the user to turn off blinking with count=0
    (cherry picked from commit 0a17ff06db0029360a27264b12876261d92c0394)
    [throttleHandling.cpp]
2022-10-16 Fix bug in blink handling dependent on LED being on
    [throttleHandling.cpp]
2022-10-16 Revert "Fix off-by-one error in blink number of times."
    This reverts commit beff6ea3a9c923ff9c44f6cd736eaf76ae951cf5.
    [throttleHandling.cpp]
2023-04-28 Revert 0f80c41a935b6b483da60b2e610f70cfcff2a1fb
    Messed up while cleaning up...
    [esp-firmware.ino]
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2023-11-14 Set DHCP hostname before starting WiFi network
    Fixes #50.
    (cherry picked from commit 0ebdd8a97e0bcfeeb27d80be194b6b06e1734c9b)
    [wifi.cpp]
2023-11-14 Use subnet mask to find server if MDNS fails
    Fixes #58.
    [locoHandling.cpp]
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2024-09-21 Replace deprecated calls into ArduinoJson
    (cherry picked from commit e53b4963c61b8be2750f24dcc86a3a2a10c8cb7c)
    [config.cpp]
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2025-12-08 New feature 'Keep ESTOP pressed to clear all functions' + minor 'bug fix' setLEDblink()
    [locoHandling.cpp, throttleHandling.cpp]
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2026-01-12 Typo fix in locoHandling.cpp comment
    [locoHandling.cpp]
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2026-05-13 fix: Allow to connect using host name if IP address was not discovered
    [locoHandling.cpp]
2026-06-08 Fix invalid XML declaration in getConfigXML() (#71)
    The XML config declaration used uppercase `<?XML` (not a valid XML
    declaration per W3C XML 1.0, and a reserved PI target) and a corrupted
    encoding name `UTF?8`. Correct both to a spec-compliant
    `<?xml version="1.0" encoding="UTF-8"?>` so the output parses with
    standards-compliant XML parsers without a client-side workaround.
    [wifiHandling.cpp]
2026-08-30 Fix compilation error in key removal
    (cherry picked from commit f11bd83b5282134a3918fc85736941445addf74d)
    [wifiHandling.cpp]
2026-08-30 Correct number of blinks
    [throttleHandling.cpp]
2026-08-30 Correctly set lowBattery status instead of empty
    [throttleHandling.cpp]

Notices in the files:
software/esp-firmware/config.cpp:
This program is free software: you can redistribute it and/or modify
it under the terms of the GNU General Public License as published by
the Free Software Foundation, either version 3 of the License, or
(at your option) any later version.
